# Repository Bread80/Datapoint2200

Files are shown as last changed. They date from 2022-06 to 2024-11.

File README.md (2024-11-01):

# Datapoint 2200 Schematics, Documents and PCB Recreations (WiP)

This is my project to transcribe the schematics for a Datapoint 2200 serial processor machine, reverse engineer them, and recreate the original hardware with added blinkenlights.

The repository contains schematics, PCB layout files, documents and software relevant to the 2200.

The schematics are in Kicad 5 format (at least until I make my peace with the UI in newer versions). To open them you may need to import the symbol library in Datapoint2200.lib and the Datapoint2200.pretty folder.

NOTES:
* These documents are still a work in progress.
* Schematics have not been double checked or verified against original hardware.
* On the original schematics some of the connector pinouts are ambiguous. DO NOT rely on the data in this repository when working with original hardware.

## Files
Some of the included files/PDFs:
* 2200_Drawing_package.pdf - Original schematics and engineering drawings.
* 2200_Reference_Manual.pdf - The operating manual for the machine including the assembly instruction set.
* 2200_Programmers_Man_Aug71.pdf - The processor instruction set, description of the standard libraries and operating instructions for the operating system, editor and assembler. Also contains a source code listing of the operating system software (but not the libraries, assembler or editor).
* 1405_Shift_Memory.pdf - Datasheet for the shift memory used in processor and video display.
* 74LS189_FairchildSemiconductor.pdf - Datasheet for the memory ICs used to implement the processor stack. (Which actually used very similiar 7489 ICs. The recreation has been designed to be able to use either).
* 1982_Standard_Microsystems.pdf - A datasheet catalogue which includes that for a character ROM compatible with one of those used in the video display, including character bitmaps.
* Datapoint2200.lib and .dcm - Kicab custom symbols (for Kicad 5).
* InstructionSet.txt - The instruction sets for both versions of the 2200 and the (very similar) Intel 8008.
* InstructionSet.xlsx - Spreadsheet version of the instruction sets (2200 and 8008) including comparisons against the Z80/8080.

## Folders/Boards
Schematics for each board are in their own folder.

The following lists the key boards of the Datapoint 2200 and the current status of each board.

### Board A1: Power Supply, Regulator
Status: Not transcribed.

### Board A2: Modulator
Modulator for the tape drives

Status: Not transcribed yet.

### Board A3: Demodulator
Demodulator for the tape drives

Status: Not transcribed yet.

### Board A4: Decoder
The system sequencer and output port/command decoder.

The schematic is split into the following files and functional units:
* Scheduler: Contains the system clock and gneerates signals to control the processort and machine as a whole.
* IODecoder: Decodes output port (command) addresses into individual signal lines.
* Speaker_Tape: Generates sound to the speaker (beeps and clicks), and houses some gates spilled over from the tape drive boards.

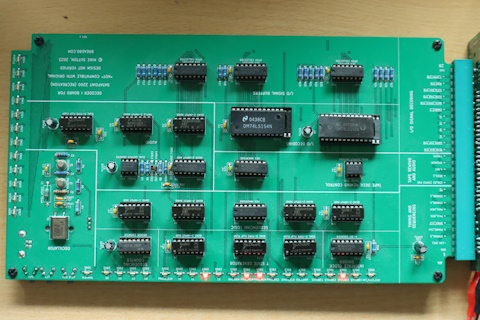
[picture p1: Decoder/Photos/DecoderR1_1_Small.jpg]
Decoder revision 1 PCB


Status: A first revision board has been manufactured and works but has a couple of largely cosmetic issues, the worst of which is an incorrect footprint for the wide-body TTL chips. The PCB currently in the repository is the proposed next revision but which has not been tested - I'll have it manufactured when I know it is driving the rest of the system correctly.

### Board A5: Processor
---
The processor itself. The schematic is divided up as follows:
* AddressRegister: The address register (counter).
* AddrRegAndStackControl: Controls reading data into the address register and program counter, incrementing the program counter, and the stack.
* ALU: The ALU and carry flag.
* ARegister: The A register and I/O bus.
* Flags: The flags (other than carry) and conditional jump/call/return handling.
* InstrDecdoing: Instruction decoding.
* IRegister: The instruction register and register decoding.
* Processor: The main overview.
* Registers1: The H and L registers and data bus logic.
* Registers2: The B, C, D and E registers.
* Stack: The stack and stack pointer, and memory card selection.
* Timing: Fetch-execute cycle, memory word sync, HALTing and running, clocking and miscellaneous.

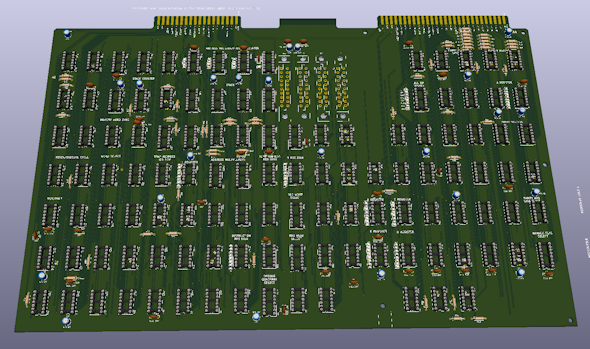
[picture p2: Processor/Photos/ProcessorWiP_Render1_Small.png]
Render of Processor PCB, WiP


Status: The design has been tested in a logic emulator and appears to function correctly. A PCB layout has been made up and I'm currently adding LEDs (and establishing which signals should have LEDs) before sending the board for production.

### Board A6: Keyboard
---
Houses the keyswitches and multiplexing circuitry.

Status: Transcribed but not checked.

### Board A7: Deflection Amplifier
---
This board houses the circuitry for driving the CRT, and also some TTL logic spilled over from the Display Control board.

Status: The TTL circuits have been transcribed. I'm proposing to replace the CRT circuitry with something capable of driving a suitable modern display (ie. something microcontroller based).

### Board A8: Display Control
The 'video card'. Contains video memory, character generator and display driver. The board also controls the reading of data from the keyboard.

The schematic is divided as follows
* Input: I/O decoder for the display and keyboard (they use the same port address) and controls the latching of video data (control register, horizontal and vertical position and data).
* Memory: Video memory (using 1405 shift registers).
* Pixel Gen: Pixel clock, 'diddle scanning' (row and column wthin each character), characters ROMs and cursor generation.
* RowColumnSync: Row and column scanning and latches, and syncing the two for writing video data to memory.
* ClearAndOutput: Clearing memory for to-end-of-row, to-end-of-screen and clear-display functions. Outputting the status register (display busy and keyboard mounted switches).

Status: Transcribed and checked (but not validated).

### Board A9: Keyboard Logic
Contains the logic for scanning the keyboard, latching returned keypresses, and outputting characted codes in ASCII.

Contains the following modules:
* Reboot: Drives the processor after rebooting to load the boot data from a tape drive.
* ReadControl: Controls the processor's input bus. The board either outputs data from the keyboard itself or the bus buffers(probably).
* 'Sheet1': The main keyboard scanning and latching circuit. This name is probably not optimal.
* Shift: A circuit spilled opver from 'Sheet1' which controls 'shifting' of ASCII codes.
* BusBuffers: Comparators to boost the signals from the external bus and forward them to the processor's input bus.
* RunSwitch: A small circuit to latch the state of the Run switch.

Status: Transcribed and checked but not validated.

### Boards A11 to A14: Memory cards
Houses the Intel 1405 shift memories ICs used by the processor and related row and column decoders.

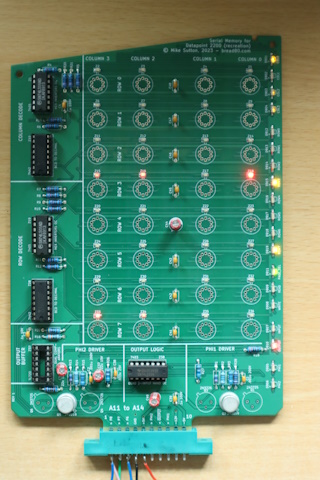
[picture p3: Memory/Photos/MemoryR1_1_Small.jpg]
Memory card revision 1 PCB


Status: Transcribed and first revision boards manufactured. The recreated PCBs include solder links to enable the memory to be operated at TTL voltage levels.
Note: The board has not been tested with actual 1405 chips.
Note: The 1405 ICs require a lot of power. The original PCBs are heavily engineered to be able to supply this power, and include a pair of bus bars for power distribution. The recreated PCBs have not been engineered to the same standards and shift should *not* be used with shift memories.

### Board A17: Motherboard
The 'backplane' into which many of the above boards slot (A1 to A9 except A6) or connect.

Status: Not transcribed yet

(Other board numbers are for smaller boards such as those in the tape machines, speaker mountings etc).

## Other Repository Contents
* Egde56: A test for for attaching to an edge connector.
* Software: A transcription and binaries for the operating system software listed in the Programmers Manual.

## Design Standards
These are mainly notes for myself to keep things consistent between boards.
  
Components:
  LEDs, side facing: Datapoint2200:LED_Dialight_597_xxxx_407F_SMT_RA_3mmx2mmx1mm (custom component and footprint in Datapoint2200 library)

Footprints:
Decoupling capacitors: Capacitor_THT:C_Disc_D7.0mm_W2.5mm_P5.00mm
Resistors (through hole): Resistor_THT:R_Axial_DIN0207_L6.3mm_D2.5mm_P10.16mm_Horizontal
Resistors (surface mount): 
  Decoder uses 0805: Resistor_SMD:R_0805_2012Metric_Pad1.20x1.40mm_HandSolder
  (other boards will vary!)
Mounting holes: MountingHole:MountingHole_3.2mm_M3
  Holes positioned 7x 25mils from board edges
Buttons (side mounted): Button_Switch_THT:SW_Tactile_SPST_Angled_PTS645Vx58-2LFS (exact model to be clarified)

Silkscreen:
All silkscreen placed on a 25mil (0.6250mm) grid
Section titles font size: W1.5 H1.5 Thickness: .25
Text for ICs:
  Top left: chip code (e.g. 7493), stated with original 74 series (no LS, HCT etc)
  Top right: reference code (e.g Z19)
  Below: chip description, centred. Use summary from datasheet where possible
Text for edge connector pins:
  Left (right on reverse) aligned to edge connector
  Use a < or > at connector end to indicate signal direction
  Positioned 50mil (2x0.6350mm) from connector pad
Edge connector pin numbers:
  Label first and last pin on each side.
  Font size: H1.5 H1.5 Thickness: 0.25
  Position: centred aligned
    8x 25mil horizontally from edge of connector pads
	4x 25mil vertically from centre of first pad
Board identifier (e.g. A4)
  Font size: H2 W2 Thickness: 0.35, orientation 90 degrees (i.e. from bottom to top) (Orientation valid for 'main' PCBs)
  Positioning: Centre aligned, 6x 25mils from board edge, 6x 25mils from edge of edge connector
Lines:
  Section separators: 0.5mm width
  Sub-section separators: 0.12mm width

*74x00	4	quad 2-input NAND gate			14	SN74LS00
*74x02	4	quad 2-input NOR gate			14	SN74LS02
*74x03	4	quad 2-input NAND gate		open-collector	14	SN74LS03
*74x04	6	hex inverter gate			14	SN74LS04
*74x05	6	hex inverter gate		open-collector	14	SN74LS05
**74x06	6	hex inverter gate		open-collector 30 V / 40 mA	14
*74x08	4	quad 2-input AND gate			14	SN74LS08
*74x10	3	triple 3-input NAND gate			14	SN74LS10
*74x20	2	dual 4-input NAND gate			14	SN74LS20
*74x30	1	single 8-input NAND gate			14	SN74LS30
**74x37	4	quad 2-input NAND gate		driver NO=30	14	SN74LS37
**74x40	2	dual 4-input NAND gate		driver NO=30	14	SN74LS40
*74x42	1	BCD to decimal decoder			16	SN74LS42
*74x73	2	dual J-K flip-flop, asynchronous clear			14	SN54LS73A
*74x74	2	dual D positive edge triggered flip-flop, asynchronous preset and clear			14	SN74LS74A
*74x85	1	4-bit magnitude comparator			16	SN74LS85
*74x89	1	64-bit RAM (16x4), 4 data inputs, 4 inverted data outputs		open-collector	16	SN7489
*74x95	1	4-bit shift register, parallel in, parallel out, serial input; different pinout for 74L95			14
*74x151	1	8-line to 1-line data selector/multiplexer			16	SN74151A
*74x153	2	dual 4-line to 1-line data selector/multiplexer, non-inverting outputs			16	SN74153
*74x164	1	8-bit serial-in parallel-out (SIPO) shift register, asynchronous clear, not output latch			14	SN74164
*74x193	1	synchronous presettable up/down 4-bit binary counter, clear			16	SN74193

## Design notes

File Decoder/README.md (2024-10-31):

Revision History

===Change History

Rev 1
Original

Revision 2
Fixed footprints for Z14, Z21
Beefed up connections to edge connector for +5V and GND
Renamed S0 to S3 LEDs as C0 to C3
Swapped order of C0 to C3
Added central mounting hole to provide extra physical support
Slightly repositioned sequencer LEDs due to central spacer, and for better grouping
LED for DIV64_CLK LED now driven from S3 (DIV64_CLK requires a pull-up which is positioned on the processor board)

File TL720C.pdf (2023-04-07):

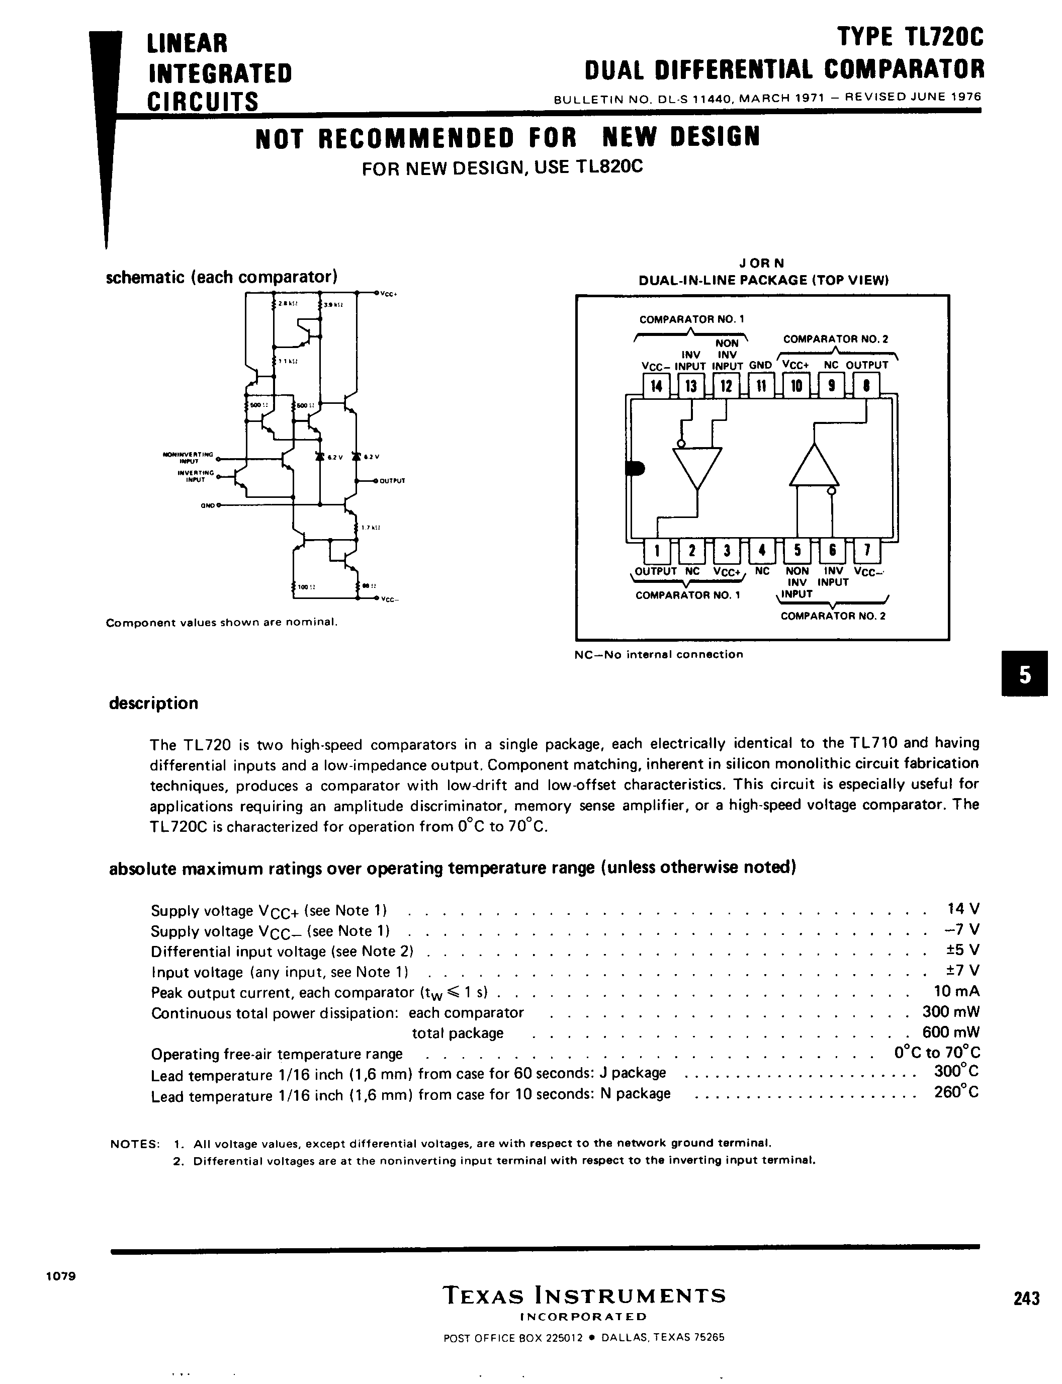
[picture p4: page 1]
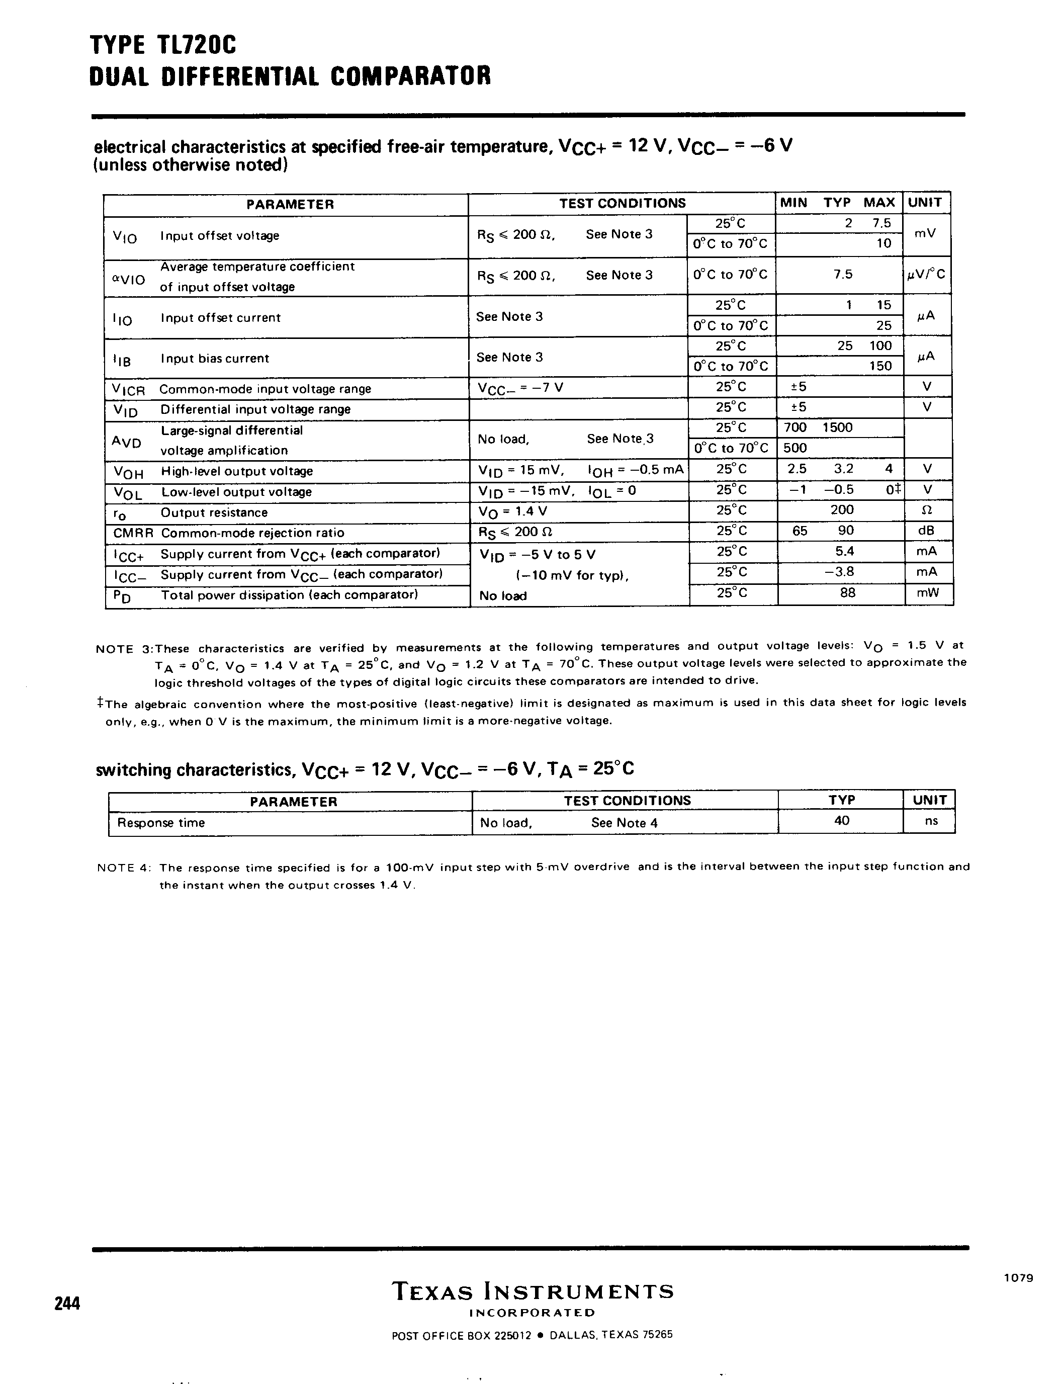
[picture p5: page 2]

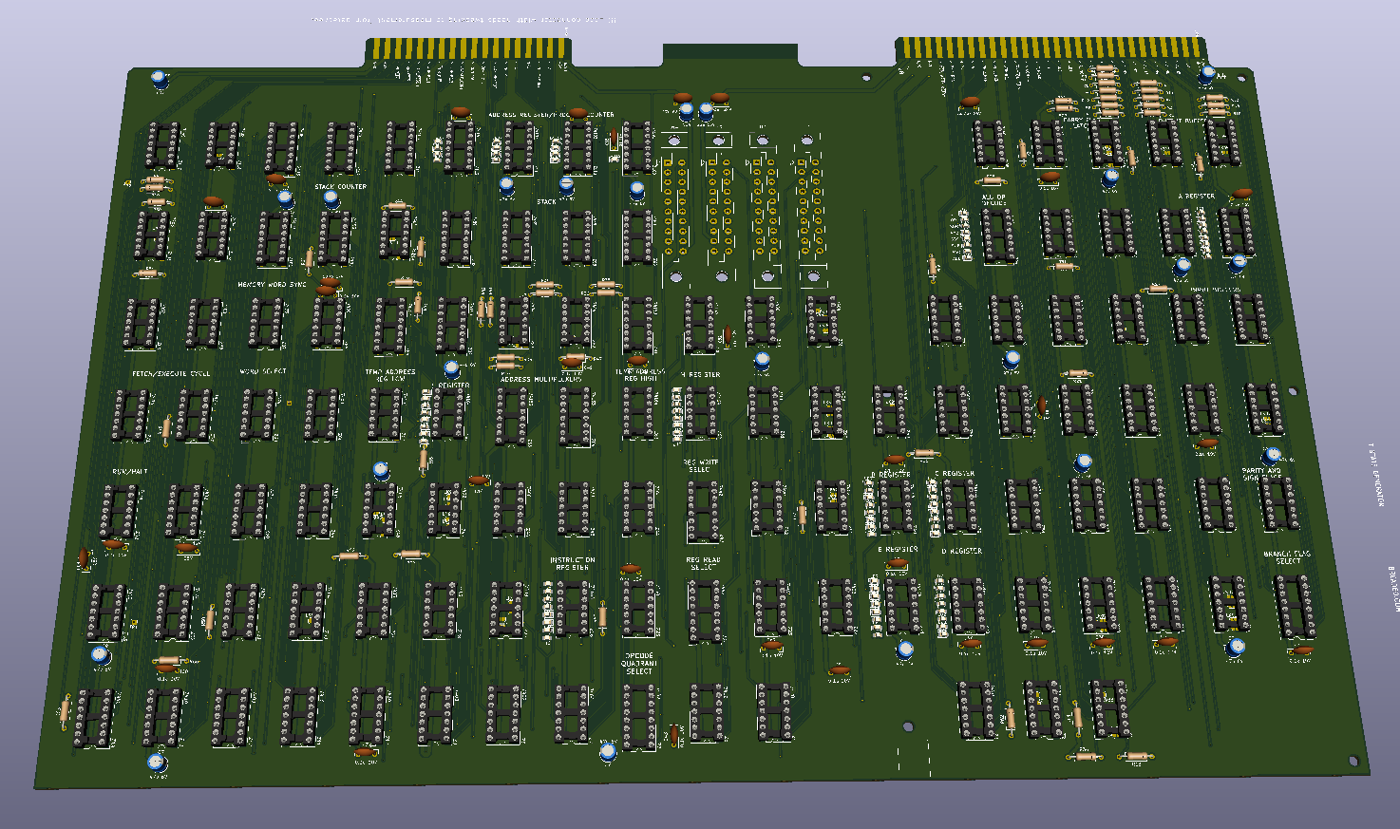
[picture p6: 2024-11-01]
Processor/Photos/ProcessorWiP_Render1.png

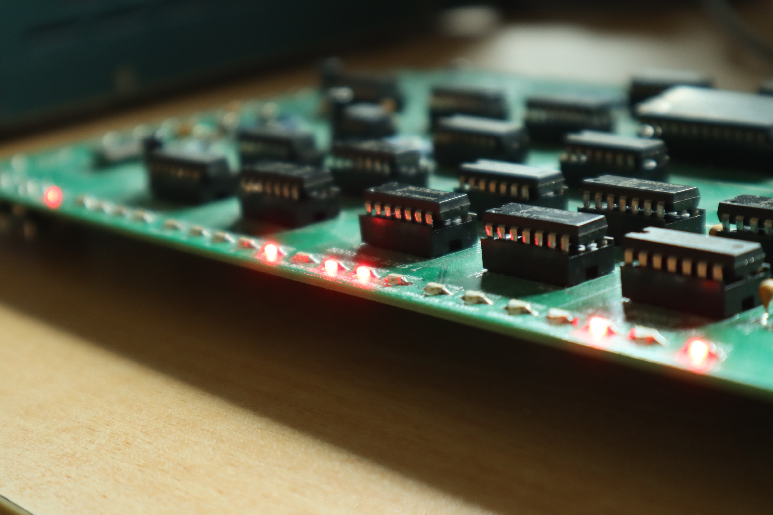
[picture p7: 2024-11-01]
Decoder/Photos/DecoderR1_8.JPG

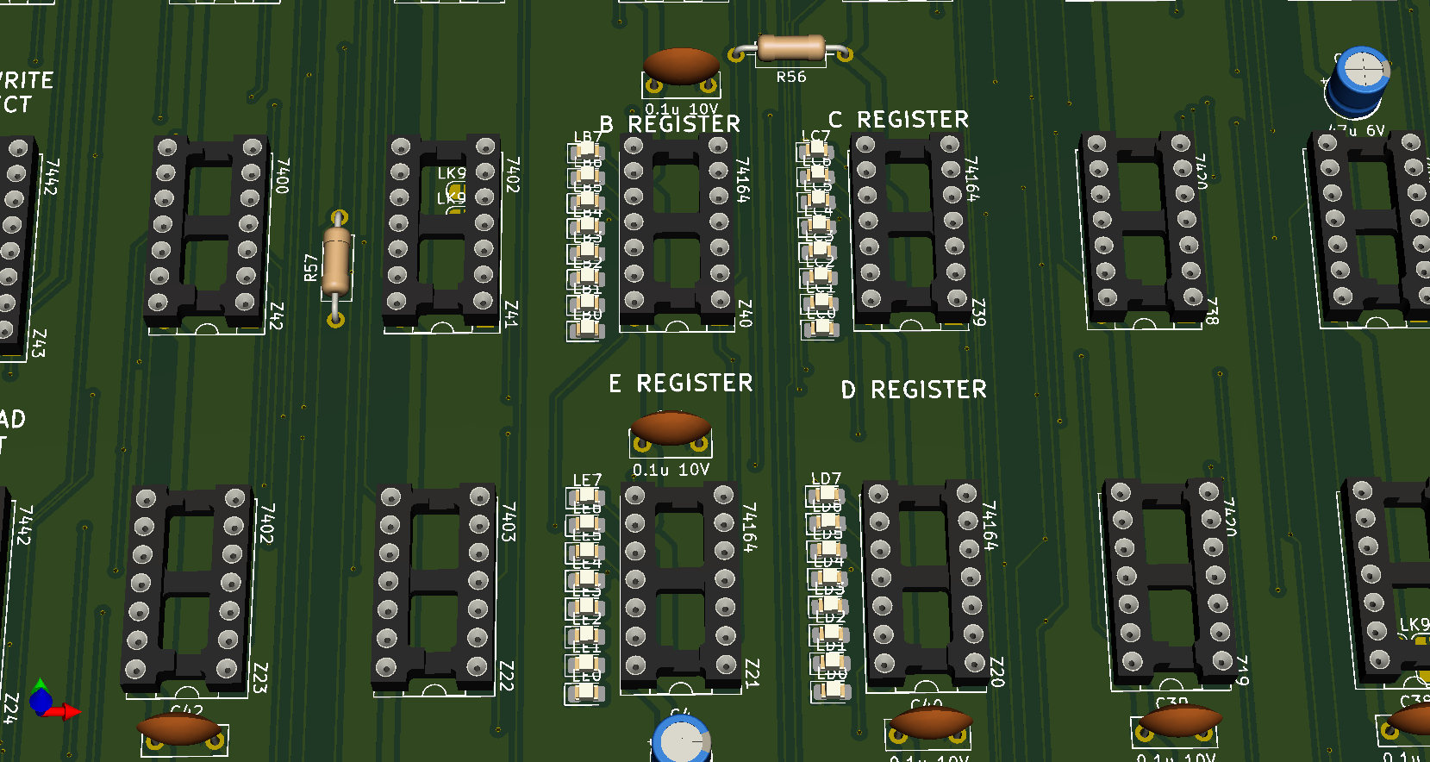
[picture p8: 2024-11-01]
Processor/Photos/ProcessorWiP_Render2.png

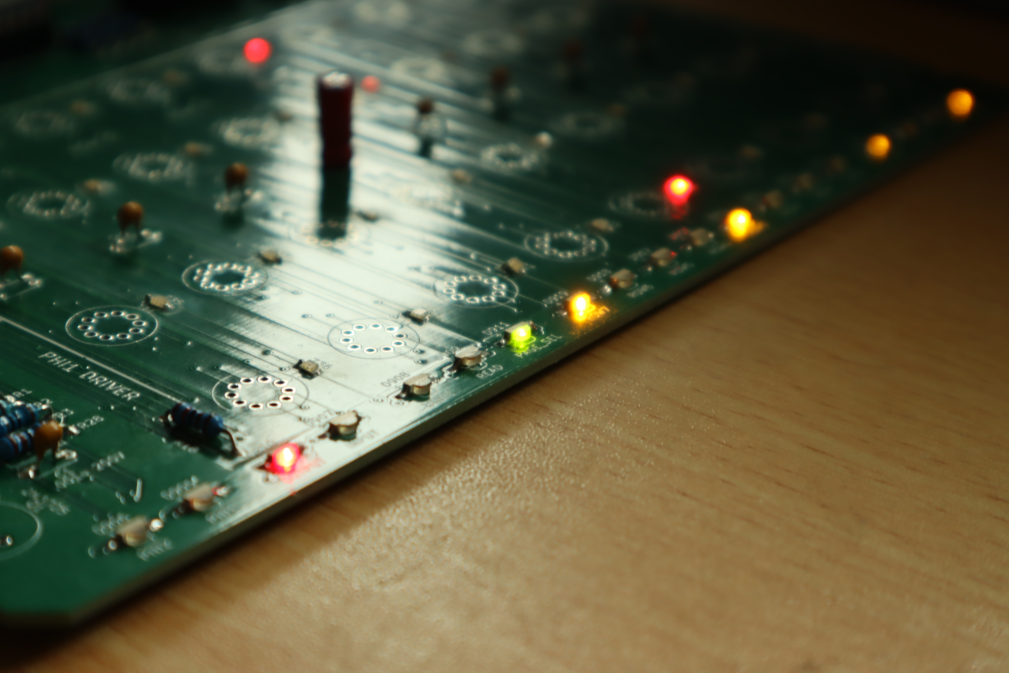
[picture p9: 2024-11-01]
Memory/Photos/MemoryR1_4.JPG

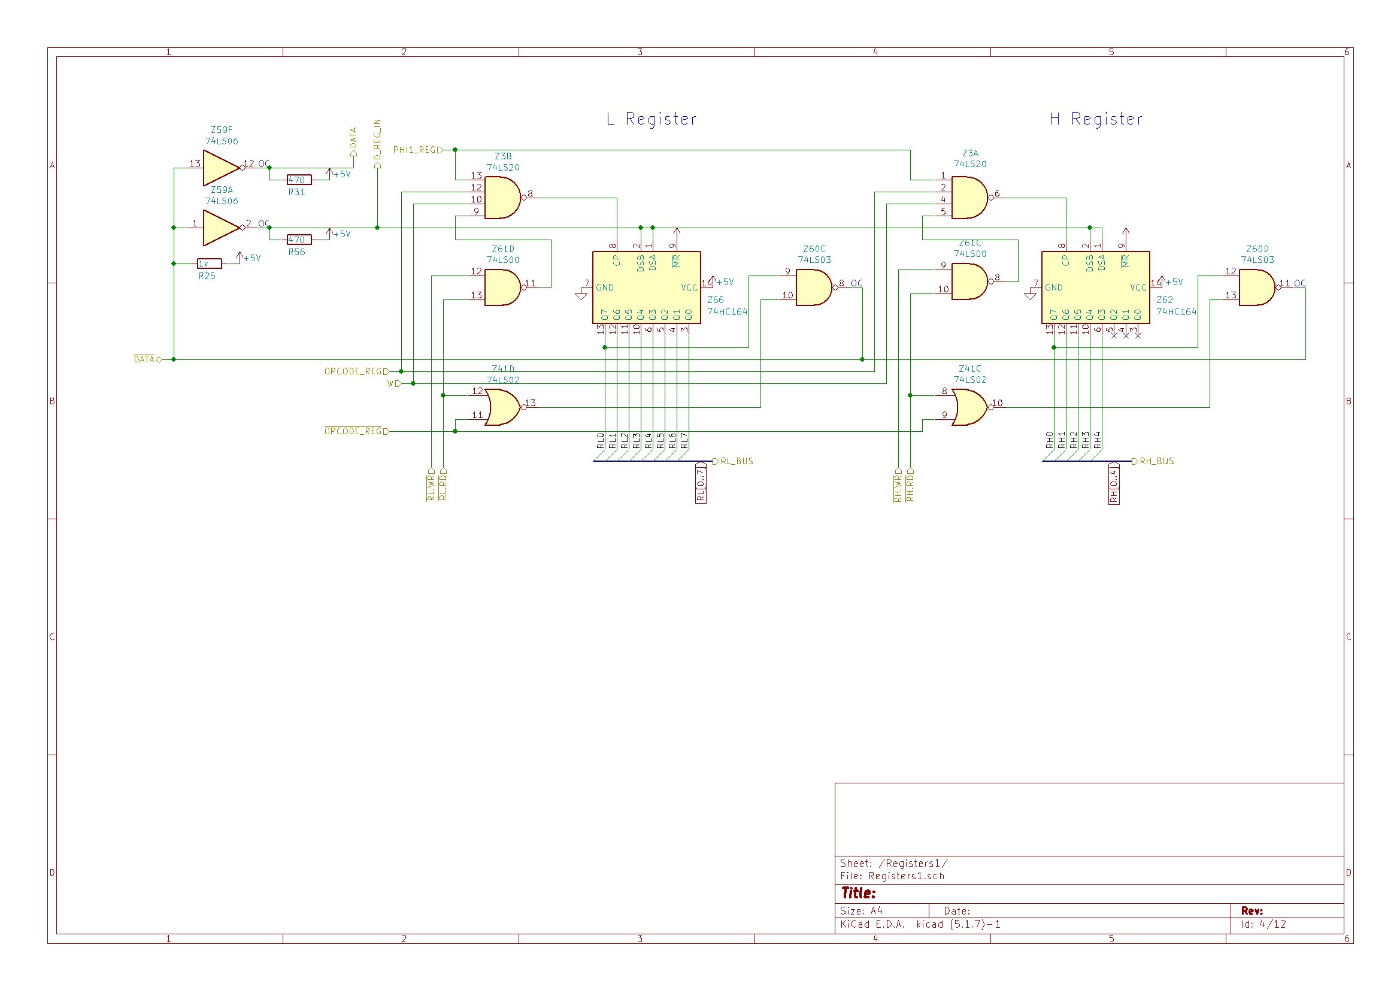
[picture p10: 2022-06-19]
Processor/Registers1.png

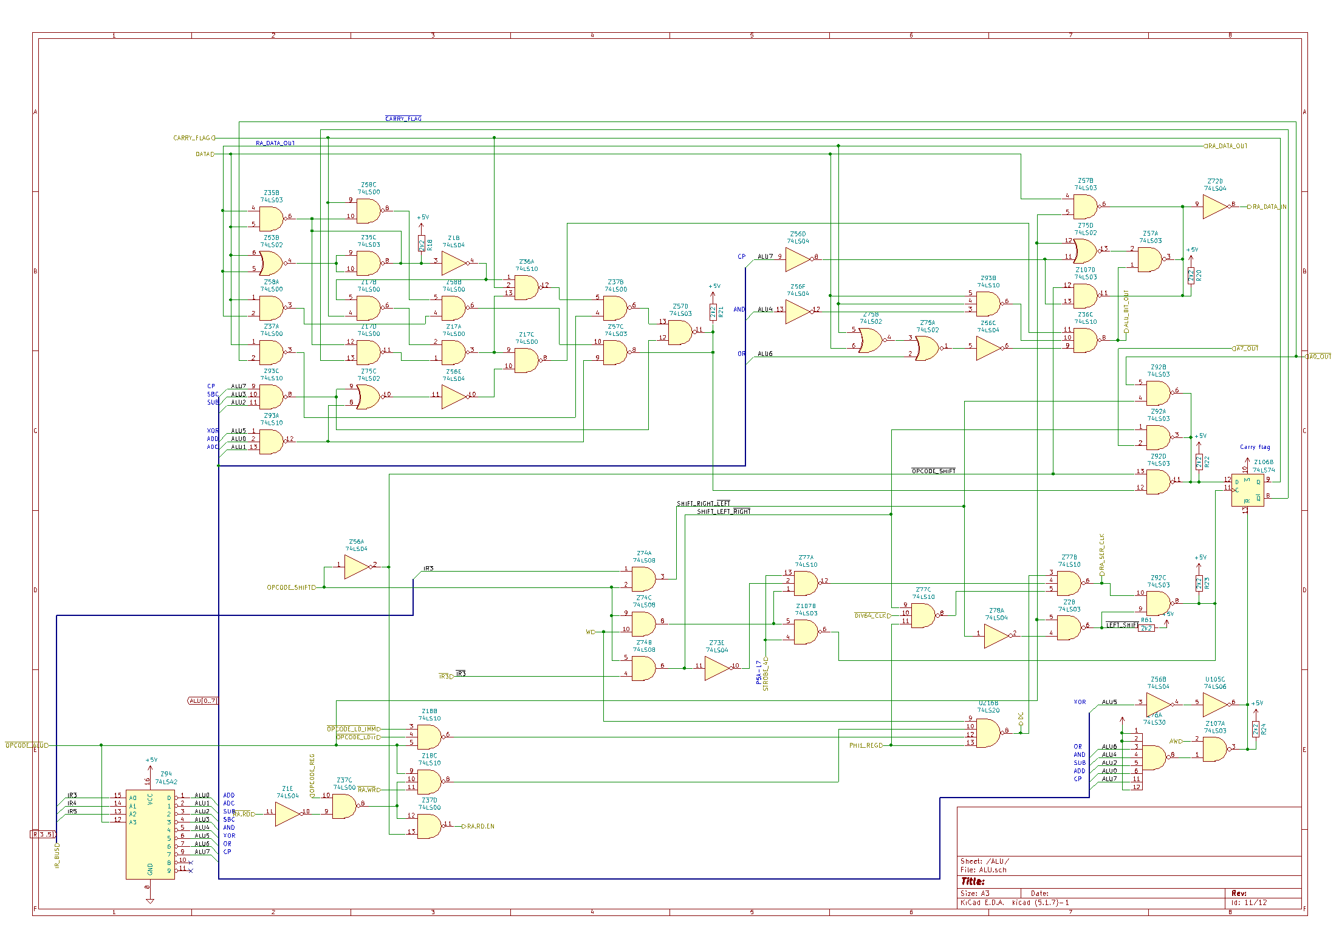
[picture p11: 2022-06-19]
Processor/ALU.png

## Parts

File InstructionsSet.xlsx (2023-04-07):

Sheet: Sheet1
Datapoint 2200 Instruction Set
 | x0 | x1 | x2 | x3 | x4 | x5 | x6 | x7 | x8 | x9 | xA | xB | xC | xD | xE | xF
0x | HALT | HALT | SLC | RFC | AD n |  | LA n | RETURN |  |  | SRC | RFZ | AC n |  | LB n
1x | BETA* |  |  | RFS | SU n |  | LC n |  | ALPHA* |  |  | RFP | SB n |  | LD n
2x | DI* |  |  | RTC | ND n |  | LE n |  | EI* |  |  | RTZ | XR n |  | LH n
3x | POP* |  |  | RTS | OR n |  | LL n |  | PUSH* |  |  | RTP | CP n |  | LM n
4x | JFC nn | INPUT | CFC nn |  | JMP nn |  | CALL nn |  | JFZ nn |  | CFZ nn
5x | JFS nn | EX ADR | CFS nn | EX STATUS |  | EX DATA |  | EX WRITE | JFP nn | EX COM1 | CFP nn | EX COM2 |  | EX COM3 |  | EX COM4
6x | JTC nn | (EX unassigned) | CTC nn | (EX unassigned) |  | (EX unassigned) |  | (EX unassigned) | JTZ nn | EX BEEP | CTZ nn | EX CLICK |  | EX DECK1 |  | EX DECK2
7x | JTS nn | EX RBK | CTS nn | EX WBK |  | (EX unassigned) |  | EX BSP | JTP nn | EX SF | CTP nn | EX SB |  | EX REWIND |  | EX TSTOP
8x | ADA | ADB | ADC | ADD | ADE | ADH | ADL | ADM | ACA | ACB | ACC | ACD | ACE | ACH | ACL | ACM
9x | SUA | SUB | SUC | SUD | SUE | SUH | SUL | SUM | SBA | SBB | SBC | SBD | SBE | SBH | SBL | SBM
Ax | NDA | NDB | NDC | NDD | NDE | NDH | NDL | NDM | XRA | XRB | XRC | XRD | XRE | XRH | XRL | XRM
Bx | ORA | ORB | ORC | ORD | ORE | ORH | ORL | ORM | CPA | CPB | CPC | CPD | CPE | CPH | CPL | CPM
Cx | NOP | LAB | LAC | LAD | LAE | LAH | LAL | LAM | LBA | LBB | LBC | LBD | LBE | LBH | LBL | LBM
Dx | LCA | LCB | LCC | LCD | LCE | LCH | LCL | LCM | LDA | LDB | LDC | LDD | LDE | LDH | LDL | LDM
Ex | LEA | LEB | LEC | LED | LEE | LEH | LEL | LEM | LHA | LHB | LHC | LHD | LHE | LHH | LHL | LHM
Fx | LLA | LLB | LLC | LLD | LLE | LLH | LLL | LLM | LMA | LMB | LMC | LMD | LME | LMH | LML | HALT
* - Instruction only available on version 2 processor
Key:
Load/store/Move
ALU operations
Flow control (Jump, Call, Return)
Input/Output
Miscellaneous
Lxx = Load/store/move. First parameter is destination, second is source. M=indirect read from/write to address in HL register
ADx=Add
ACx=Add with carry
SUx=Subtract
SBx=Substract with borrow
NDx=AND
XRx=XOR
ORx=OR
CPx=Compare
SLC=Shift left circular (rotate accumulator left)
SRC=Shift right circular (rotate the accumulator right)
RTx=Return if flag true
RFX=Return if flag false
Similary, Cxx=Call, Jxx=Jump
EX='Execute', ie send a command to an IO device.
EX ADR=Select a device at the address in the A register
INPUT reads value on IO bus. (Ie use an EX instructions beforehand to select a device and get it to put an input value onto the bus)

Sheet: Sheet2
Datapoint 2200 Instruction Set - Comparison to Z80
 | x0 | x1 | x2 | x3 | x4 | x5 | x6 | x7 | x8 | x9 | xA | xB | xC | xD | xE | xF
0x | HALT | HALT | RLA | RET NC | ADD A,n |  | LD A,n | RET |  |  | RRA | RET NZ | ADC A,n |  | LD B,n
1x | BETA* |  |  | RET P | SUB A,n |  | LD C,n |  | ALPHA* |  |  | RET PO | SBC A,n |  | LD D,n
2x | DI* |  |  | RET C | AND A,n |  | LD E,n |  | EI* |  |  | RET Z | XOR A,n |  | LD H,n
3x | POP HL* |  |  | RET M | OR A,n |  | LD L,n |  | PUSH HL* |  |  | RET PE | CP A,n |  | LD (HL),n
4x | JP NC,nn | INPUT | CALL NC,nn |  | JP nn |  | CALL nn |  | JP NZ,nn |  | CALL NZ,nn
5x | JP P,nn | EX ADR | CALL P,nn | EX STATUS |  | EX DATA |  | EX WRITE | JP PO,nn | EX COM1 | CALL PO,nn | EX COM2 |  | EX COM3 |  | EX COM4
6x | JP C,nn | (EX unassigned) | CALL C,nn | (EX unassigned) |  | (EX unassigned) |  | (EX unassigned) | JP Z,nn | EX BEEP | CALL Z,nn | EX CLICK |  | EX DECK1 |  | EX DECK2
7x | JP M,nn | EX RBK | CALL M,nn | EX WBK |  | (EX unassigned) |  | EX BSP | JP PE,nn | EX SF | CALL PE,nn | EX SB |  | EX REWIND |  | EX TSTOP
8x | ADD A,A | ADD A,B | ADD A,C | ADD A,D | ADD A,E | ADD A,H | ADD A,L | ADD A,(HL) | ADC A,A | ADC A,B | ADC A,C | ADC A,D | ADC A,E | ADC A,H | ADC A,L | ADC A,(HL)
9x | SUB A,A | SUB A,B | SUB A,C | SUB A,D | SUB A,E | SUB A,H | SUB A,L | SUB A,(HL) | SBC A,A | SBC A,B | SBC A,C | SBC A,D | SBC A,E | SBC A,H | SBC A,L | SBC A,(HL)
Ax | AND A | AND B | AND C | AND D | AND E | AND H | AND L | AND (HL) | XOR A | XOR B | XOR C | XOR D | XOR E | XOR H | XOR L | XOR (HL)
Bx | OR A | OR B | OR C | OR D | OR E | OR H | OR L | OR (HL) | CP A | CP B | CP C | CP D | CP E | CP H | CP L | CP (HL)
Cx | NOP | LD A,B | LD A,C | LD A,D | LD A,E | LD A,H | LD A,L | LD A,(HL) | LD B,A | LD B,B | LD B,C | LD B,D | LD B,E | LD B,H | LD B,L | LD B,(HL)
Dx | LD C,A | LD C,B | LD C,C | LD C,D | LD C,E | LD C,H | LC C,L | LD C,(HL) | LD D,A | LD D,B | LD D,C | LD D,D | LD D,E | LD D,H | LD D,L | LD D,(HL)
Ex | LD E,A | LD E,B | LD E,C | LD E,D | LD E,E | LD E,H | LD E,L | LD E,(HL) | LD H,A | LD H,B | LD H,C | LD H,D | LD H,E | LD H,H | LD H,L | LD H,(HL)
Fx | LD L,A | LD L,B | LD L,C | LD L,D | LD L,E | LD L,H | LD H,L | LD H,(HL) | LD (HL),A | LD (HL),B | LD (HL),C | LD (HL),D | LD (HL),E | LD (HL),H | LD (HL),L | HALT
* - Instruction only available on version 2 processor
Key:
Instructions with direct Z80 equivalents

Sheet: Sheet3
Intel 8008 Instruction Set
 | x0 | x1 | x2 | x3 | x4 | x5 | x6 | x7 | x8 | x9 | xA | xB | xC | xD | xE | xF
0x | HLT | HLT | RLC | RFC | ADI n | RST &00 | LAI n | RET | INB | DCB | RRC | RFZ | ACI n | RST &08 | LBI n | RET
1x | INC | DCC | RAL | RFS | SUI n | RST &10 | LCI n | RET | IND | DCD | RAR | RFP | SBI n | RST &18 | LDI n | RET
2x | INE | DCE |  | RTC | NDI n | RST &20 | LEI n | RET | INH | DCH |  | RTZ | XRI n | RST &28 | LHI n | RET
3x | INL | DCL |  | RTS | ORI n | RST &30 | LLI n | RET |  |  |  | RTP | CPI n | RST &38 | LMI n | RET
4x | JFC nn | INP 0 | CFC nn | INP 1 | JMP nn | INP 2 | CALL nn | INP 3 | JFZ nn | INP 4 | CFZ nn | INP 5 | JMP nn | INP 6 | CALL nn | INP 7
5x | JFS nn | OUT 0 | CFS nn | OUT 1 | JMP nn | OUT 2 | CALL nn | OUT 3 | JFP nn | OUT 4 | CFP nn | OUT 5 | JMP nn | OUT 6 | CALL nn | OUT 7
6x | JTC nn | OUT 8 | CTC nn | OUT 9 | JMP nn | OUT 10 | CALL nn | OUT 11 | JTZ nn | OUT 12 | CTZ nn | OUT 13 | JMP nn | OUT 14 | CALL nn | OUT 15
7x | JTS nn | OUT 16 | CTS nn | OUT 17 | JMP nn | OUT 18 | CALL nn | OUT 19 | JTP nn | OUT 20 | CTP nn | OUT 21 | JMP nn | OUT 22 | CALL nn | OUT 23
8x | ADA | ADB | ADC | ADD | ADE | ADH | ADL | ADM | ACA | ACB | ACC | ACD | ACE | ACH | ACL | ACM
9x | SUA | SUB | SUC | SUD | SUE | SUH | SUL | SUM | SBA | SBB | SBC | SBD | SBE | SBH | SBL | SBM
Ax | NDA | NDB | NDC | NDD | NDE | NDH | NDL | NDM | XRA | XRB | XRC | XRD | XRE | XRH | XRL | XRM
Bx | ORA | ORB | ORC | ORD | ORE | ORH | ORL | ORM | CPA | CPB | CPC | CPD | CPE | CPH | CPL | CPM
Cx | LAA | LAB | LAC | LAD | LAE | LAH | LAL | LAM | LBA | LBB | LBC | LBD | LBE | LBH | LBL | LBM
Dx | LCA | LCB | LCC | LCD | LCE | LCH | LCL | LCM | LDA | LDB | LDC | LDD | LDE | LDH | LDL | LDM
Ex | LEA | LEB | LEC | LED | LEE | LEH | LEL | LEM | LHA | LHB | LHC | LHD | LHE | LHH | LHL | LHM
Fx | LLA | LLB | LLC | LLD | LLE | LLH | LLL | LLM | LMA | LMB | LMC | LMD | LME | LMH | LML | HLT
* - Instruction only available on version 2 processor
Key:
Load/store/Move
ALU operations
Flow control (Jump, Call, Return)
Input/Output
Miscellaneous
Lxx = Load/store/move. First parameter is destination, second is source. M=indirect read from/write to address in HL register. I=read immediate data.
ADx=Add
ACx=Add with carry
SUx=Subtract
SBx=Substract with borrow
NDx=AND
XRx=XOR
ORx=OR
CPx=Compare
RLC/RRC= Rotate accumulator left/right
RLCA/RRCA=Rotate accumulator left/right through carry
INx=Increment register. Note the lack of a variants for A and (HL)
DCx=Decrement register. Note the lack of variants for A and (HL)
RTx=Return if flag true
RFx=Return if flag false
Similary, Cxx=Call, Jxx=Jump
RST=A single byte call to the listed destination address. Intended to be 'jammed' into the processor by a interrupt hardware.
INP=Input from the selected port (to the accumulator)
OUT=Output to the selected port (from the accumulator)

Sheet: Sheet4
Intel 8008 Instruction Set - Comparison to Z80
 | x0 | x1 | x2 | x3 | x4 | x5 | x6 | x7 | x8 | x9 | xA | xB | xC | xD | xE | xF
0x | HALT | HALT | RLCA | RET NC | ADD A,n | RST &00 | LD A,n | RET | INC B | DEC B | RRCA | RET NZ | ADC A,n | RST &08 | LD B,n
1x | INC C | DEC C | RLA | RET P | SUB A,n | RST &10 | LD C,n |  | INC D | DEC D | RRA | RET PO | SBC A,n | RST &18 | LD D,n
2x | INC E | DEC E |  | RET C | AND A,n | RST &20 | LD E,n |  | INC H | DEC H |  | RET Z | XOR A,n | RST &28 | LD H,n
3x | INC L | DEC L |  | RET M | OR A,n | RST &30 | LD L,n |  |  |  |  | RET PE | CP A,n | RST &38 | LD (HL),n
4x | JP NC,nn | INP 0 | CALL NC,nn | INP 1 | JP nn | INP 2 | CALL nn | INP 3 | JP NZ,nn | INP 4 | CALL NZ,nn | INP 5 |  | INP 6 |  | INP 7
5x | JP P,nn | OUT 0 | CALL P,nn | OUT 1 | JP nn | OUT 2 | CALL nn | OUT 3 | JP PO,nn | OUT 4 | CALL PO,nn | OUT 5 |  | OUT 6 |  | OUT 7
6x | JP C,nn | OUT 8 | CALL C,nn | OUT 9 | JP nn | OUT 10 | CALL nn | OUT 11 | JP Z,nn | OUT 12 | CALL Z,nn | OUT 13 |  | OUT 14 |  | OUT 15
7x | JP M,nn | OUT 16 | CALL M,nn | OUT 17 | JP nn | OUT 18 | CALL nn | OUT 19 | JP PE,nn | OUT 20 | CALL PE,nn | OUT 21 |  | OUT 22 |  | OUT 23
8x | ADD A,A | ADD A,B | ADD A,C | ADD A,D | ADD A,E | ADD A,H | ADD A,L | ADD A,(HL) | ADC A,A | ADC A,B | ADC A,C | ADC A,D | ADC A,E | ADC A,H | ADC A,L | ADC A,(HL)
9x | SUB A,A | SUB A,B | SUB A,C | SUB A,D | SUB A,E | SUB A,H | SUB A,L | SUB A,(HL) | SBC A,A | SBC A,B | SBC A,C | SBC A,D | SBC A,E | SBC A,H | SBC A,L | SBC A,(HL)
Ax | AND A | AND B | AND C | AND D | AND E | AND H | AND L | AND (HL) | XOR A | XOR B | XOR C | XOR D | XOR E | XOR H | XOR L | XOR (HL)
Bx | OR A | OR B | OR C | OR D | OR E | OR H | OR L | OR (HL) | CP A | CP B | CP C | CP D | CP E | CP H | CP L | CP (HL)
Cx | NOP | LD A,B | LD A,C | LD A,D | LD A,E | LD A,H | LD A,L | LD A,(HL) | LD B,A | LD B,B | LD B,C | LD B,D | LD B,E | LD B,H | LD B,L | LD B,(HL)
Dx | LD C,A | LD C,B | LD C,C | LD C,D | LD C,E | LD C,H | LC C,L | LD C,(HL) | LD D,A | LD D,B | LD D,C | LD D,D | LD D,E | LD D,H | LD D,L | LD D,(HL)
Ex | LD E,A | LD E,B | LD E,C | LD E,D | LD E,E | LD E,H | LD E,L | LD E,(HL) | LD H,A | LD H,B | LD H,C | LD H,D | LD H,E | LD H,H | LD H,L | LD H,(HL)
Fx | LD L,A | LD L,B | LD L,C | LD L,D | LD L,E | LD L,H | LD L,L | LD L,(HL) | LD (HL),A | LD (HL),B | LD (HL),C | LD (HL),D | LD (HL),E | LD (HL),H | LD (HL),L | HALT
* - Instruction only available on version 2 processor
Key:
Instructions with direct Z80 equivalents

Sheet: Sheet5
Z80 Instruction History
 | x0 | x1 | x2 | x3 | x4 | x5 | x6 | x7 | x8 | x9 | xA | xB | xC | xD | xE | xF
0x | NOP | LD BC,nn | LD (BC),A | INC BC | INC B | DEC B | LD B,n | RLCA | EX AF,AF' | ADD HL,BC | LD A,(BC) | DEC BC | INC C | DEC C | LD C,n | RRCA
1x | DJNZ e | LD DE,nn | LD (DE),A | INC DE | INC D | DEC D | LD D,n | RLA | JR e | ADD HL,DE | LD A,(DE) | DEC DE | INC E | DEC E | LD E,n | RRA
2x | JR NZ,e | LD HL,nn | LD (nn),HL | INC HL | INC H | DEC H | LD H,n | DAA | JR Z,e | ADD HL,HL | LD HL,(nn) | DEC HL | INC L | DEC L | LD L,n | CPL
3x | JR NC,e | LD SP,nn | LD (nn),A | INC SP | INC (HL) | DEC (HL) | LD (HL),n | SCF | JR C,e | ADD HL,SP | LD A,(nn) | DEC SP | INC A | DEC A | LD A,n | CCF
4x | LD B,B | LD B,C | LD B,D | LD B,E | LD B,H | LD B,L | LD B,(HL) | LD B,A | LD C,B | LD C,C | LD C,D | LD C,E | LD C,H | LC C,L | LD C,(HL) | LD C,A
5x | LD D,B | LD D,C | LD D,D | LD D,E | LD D,H | LD D,L | LD D,(HL) | LD D,A | LD E,B | LD E,C | LD E,D | LD E,E | LD E,H | LD E,L | LD E,(HL) | LD E,A
6x | LD H,B | LD H,C | LD H,D | LD H,E | LD H,H | LD H,L | LD H,(HL) | LD H,A | LD L,B | LD L,C | LD L,D | LD L,E | LD L,H | LD L,L | LD L,(HL) | LD L,A
7x | LD (HL),B | LD (HL),C | LD (HL),D | LD (HL),E | LD (HL),H | LD (HL),L | HALT | LD (HL),A | LD A,B | LD A,C | LD A,D | LD A,E | LD A,H | LD A,L | LD A,(HL) | LD A,A
8x | ADD A,B | ADD A,C | ADD A,D | ADD A,E | ADD A,H | ADD A,L | ADD A,(HL) | ADD A,A | ADC A,B | ADC A,C | ADC A,D | ADC A,E | ADC A,H | ADC A,L | ADC A,(HL) | ADC A,A
9x | SUB A,B | SUB A,C | SUB A,D | SUB A,E | SUB A,H | SUB A,L | SUB A,(HL) | SUB A,A | SBC A,B | SBC A,C | SBC A,D | SBC A,E | SBC A,H | SBC A,L | SBC A,(HL) | SBC A,A
Ax | AND B | AND C | AND D | AND E | AND H | AND L | AND (HL) | AND A | XOR B | XOR C | XOR D | XOR E | XOR H | XOR L | XOR (HL) | XOR A
Bx | OR B | OR C | OR D | OR E | OR H | OR L | OR (HL) | OR A | CP B | CP C | CP D | CP E | CP H | CP L | CP (HL) | CP A
Cx | RET NZ | POP BC | JP NZ,nn | JP nn | CALL NZ,nn | PUSH BC | ADD A,n | RST &00 | RET Z | RET | JP Z,nn | CB prefix | CALL Z,nn | CALL nn | ADC A,n | RST &08
Dx | RET NC | POP DE | JP NC,nn | OUT (n),A | CALL NC,nn | PUSH DE | SUB A,n | RST &10 | RET C | EXX | JP C,nn | IN A,(n) | CALL C,nn | IX prefix | SBC A,n | RST &18
Ex | RET PO | POP HL | JP PO,nn | EX (SP),HL | CALL PO,nn | PUSH HL | AND A,n | RST &20 | RET PE | JP (HL) | JP PE,nn | EX DE,HL | CALL PE,nn | ED prefix | XOR A,n | RST &28
Fx | RET P | POP AF | JP P,nn | DI | CALL P,nn | PUSH AF | OR A,n | RST &30 | RET M | LD SP,HL | JP M,nn | EI | CALL M,nn | IY prefix | CP A,n | RST &38
Key, showing when the instruction was first introduced:
Datapoint 2200, version 1
Intel 8008
Intel 8080
Zilog Z80
Notes:
(1) Instructions are only shown if they act identically to that in a previous generation (excluding half carry, subtract and undocumented flags).
(2) DI, EI, POP HL and PUSH HL where added by the Datapoint 2200 version 2 processor but this processor existed in a separate timeline.
(3) Bytecodes changed between the 8008 and the 8080.

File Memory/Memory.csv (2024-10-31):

Source: | C:\Dropbox\InfoLaptop\Bread80\Datapoint2200\Memory\Memory.sch
Date: | 04/08/2023 15:44
Tool: | Eeschema (5.1.12)-1
Generator: | C:\Program Files\KiCad\bin\scripting\plugins/bom_csv_grouped_by_value_with_fp.py
Component Count: | 173
Ref | Qnty | Value | Cmp name | Footprint | Description | Vendor
C1, C2, | 2 | .001u 200V | C | Capacitor_THT:C_Disc_D4.7mm_W2.5mm_P5.00mm | Unpolarized capacitor
C3, | 1 | .1u 10V | C | Capacitor_THT:C_Disc_D7.0mm_W2.5mm_P5.00mm | Unpolarized capacitor
C6, C39, C41, C42, C43, C45, C46, C47, C48, | 9 | .1u 100V | C | Capacitor_THT:C_Disc_D7.0mm_W2.5mm_P5.00mm | Unpolarized capacitor
C36, C37, C49, | 3 | 22u 15V | CP | Capacitor_THT:CP_Radial_D5.0mm_P2.50mm | Polarized capacitor
C38, | 1 | .033u 25V | C | Capacitor_THT:C_Disc_D4.7mm_W2.5mm_P5.00mm | Unpolarized capacitor
C44, | 1 | 68u 15V | CP | Capacitor_THT:CP_Radial_D6.3mm_P2.50mm | Polarized capacitor
D901, | 19 | COL0 | LED | DataPoint_2200:LED_Dialight_597_xxxx_407F_SMT_RA_3mmx2mmx1mm | Light emitting diode
D920, | 32 | Z5 | LED | LED_SMD:LED_0805_2012Metric_Pad1.15x1.40mm_HandSolder | Light emitting diode
Q1, Q6, | 2 | 2N3725 | 2N2219 | Package_TO_SOT_THT:TO-39-3 | 800mA Ic, 50V Vce, NPN Transistor, TO-39
Q2, Q5, | 2 | 2N2219 | 2N2219 | Package_TO_SOT_THT:TO-39-3 | 800mA Ic, 50V Vce, NPN Transistor, TO-39
Q3, Q4, | 2 | 2N3726 | Q_PNP_BCE | Package_TO_SOT_THT:TO-39-3 | PNP transistor, base/collector/emitter
R1, R13, | 2 | 220 | R | Resistor_THT:R_Axial_DIN0207_L6.3mm_D2.5mm_P10.16mm_Horizontal | Resistor
R2, R14, | 2 | 100 | R | Resistor_THT:R_Axial_DIN0207_L6.3mm_D2.5mm_P10.16mm_Horizontal | Resistor
R3, R15, | 2 | 680 | R | Resistor_THT:R_Axial_DIN0207_L6.3mm_D2.5mm_P10.16mm_Horizontal | Resistor
R4, R5, R6, R7, R8, R9, R10, R11, R12, R18, R19, R20, R21, | 13 | 2k2 | R | Resistor_THT:R_Axial_DIN0207_L6.3mm_D2.5mm_P10.16mm_Horizontal | Resistor
R16, | 1 | 330 | R | Resistor_THT:R_Axial_DIN0207_L6.3mm_D2.5mm_P10.16mm_Horizontal | Resistor
R22, | 1 | 470 | R | Resistor_THT:R_Axial_DIN0207_L6.3mm_D2.5mm_P10.16mm_Horizontal | Resistor
R25, R28, | 2 | 1k | R | Resistor_THT:R_Axial_DIN0207_L6.3mm_D2.5mm_P10.16mm_Horizontal | Resistor
R26, R27, | 2 | 6R8 | R | Resistor_THT:R_Axial_DIN0207_L6.3mm_D2.5mm_P10.16mm_Horizontal | Resistor
R901, R902, R903, R904, R905, R906, R907, R908, R909, R910, R911, R912, R913, R914, R915, R916, R917, R918, R919, R920, R921, R922, R923, | 23 | 470R | R | Resistor_SMD:R_0805_2012Metric_Pad1.20x1.40mm_HandSolder | Resistor
U904, U905, U906, | 3 | 74HCT245 | 74LS245 | Package_SO:TSSOP-20_4.4x6.5mm_P0.65mm | Octal BUS Transceivers, 3-State outputs
Z1, Z19, | 2 | 7405 | 74LS05 | Package_DIP:DIP-14_W7.62mm_Socket | Inverter Open Collect
Z2, Z3, Z4, Z5, Z6, Z7, Z8, Z9, Z11, Z12, Z13, Z14, Z15, Z16, Z17, Z18, Z20, Z21, Z22, Z23, Z24, Z25, Z26, Z27, Z29, Z30, Z31, Z32, Z33, Z34, Z35, Z36, | 32 | 1405 | 1405 | DataPoint_2200:TO-99-10 | Intel 1405 512-bit (512 x 1) Dymanic Recirculating Shift Register (Shift Memory)
Z10, Z28, | 2 | 7442 | 74LS42 | Package_DIP:DIP-16_W7.62mm_Socket | 4 to 10 line Decoder
Z37, | 1 | TL720 | TL720 | Package_DIP:DIP-14_W7.62mm_Socket | Dual Differential Comparator
Z38, | 1 | 7403 | 74LS03 | Package_DIP:DIP-14_W7.62mm_Socket | Quad 2-input NAND open collector

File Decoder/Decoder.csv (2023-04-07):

Source: | C:\Dropbox\InfoLaptop\Bread80\Datapoint2200\Decoder\Decoder.sch
Date: | 28/03/2023 18:18
Tool: | Eeschema (5.1.12)-1
Generator: | C:\Program Files\KiCad\bin\scripting\plugins/bom_csv_grouped_by_value_with_fp.py
Component Count: | 198
Ref | Qnty | Value | Cmp name | Footprint | Description | Vendor
C1, C2, | 2 | 160p | C | Capacitor_THT:C_Disc_D7.0mm_W2.5mm_P5.00mm | Unpolarized capacitor
C3, | 1 | 51p | C | Capacitor_THT:C_Disc_D7.0mm_W2.5mm_P5.00mm | Unpolarized capacitor
C4, C8, C9, C15, C20, | 5 | 6V47u | CP | Capacitor_THT:CP_Radial_D6.3mm_P2.50mm | Polarized capacitor
C5, C6, C7, C11, C12, C13, C14, C17, C19, C24, C25, C26, | 12 | .1u | C | Capacitor_THT:C_Disc_D7.0mm_W2.5mm_P5.00mm | Unpolarized capacitor
C10, | 1 | .01u 50V | C | Capacitor_THT:C_Disc_D7.0mm_W2.5mm_P5.00mm | Unpolarized capacitor
C16, | 1 | 0.1 | C | Capacitor_THT:C_Disc_D7.0mm_W2.5mm_P5.00mm | Unpolarized capacitor
C21, C22, C23, | 3 | .001u 200V | C | Capacitor_THT:C_Disc_D7.0mm_W2.5mm_P5.00mm | Unpolarized capacitor
CR1, CR2, | 2 | 1N914 | D | Diode_THT:D_DO-34_SOD68_P7.62mm_Horizontal | Diode
D901, to D921 | 21 | 9.84MHz | LED | Datapoint2200:LED_Dialight_597_xxxx_407F_SMT_RA_3mmx2mmx1mm | Light emitting diode
D941, to D964 | 24 | PORT8 | LED | Datapoint2200:LED_Dialight_597_xxxx_407F_SMT_RA_3mmx2mmx1mm | Light emitting diode
H901, H902, H903, H904, H905, H906, | 6 | MountingHole | MountingHole | MountingHole:MountingHole_3.2mm_M3 | Mounting Hole without connection
J4A1, | 1 | EdgeTop | Conn_01x28_Male | Datapoint2200:EdgeConn_28_Pin_Pitch_3.96mm | Generic connector, single row, 01x28, script generated (kicad-library-utils/schlib/autogen/connector/)
J4B1, | 1 | EdgeBottom | Conn_01x28_Male | Datapoint2200:EdgeConn_28_Pin_Pitch_3.96mm | Generic connector, single row, 01x28, script generated (kicad-library-utils/schlib/autogen/connector/)
J981, | 1 | USB_B | USB_B | Connector_USB:USB_B_Lumberg_2411_02_Horizontal | USB Type B connector
JP901, | 1 | CLK SRC | Jumper_3_Open | Connector_PinHeader_2.54mm:PinHeader_1x03_P2.54mm_Vertical | Jumper, 3-pole, both open
L1, | 1 | 120uH 75mA | INDUCTOR | Inductor_THT:L_Axial_L9.5mm_D4.0mm_P12.70mm_Horizontal_Fastron_SMCC | Inductor symbol for simulation only
Q1, Q2, | 2 | 2N2369A | Q_NPN_EBC | Package_TO_SOT_THT:TO-18-3 | NPN transistor, emitter/base/collector
Q901, Q902, Q903, Q904, Q905, | 5 | 2N7002 | 2N7002 | Package_TO_SOT_SMD:SOT-23 | 0.115A Id, 60V Vds, N-Channel MOSFET, SOT-23
R1, | 1 | 1k5 | R | Resistor_THT:R_Axial_DIN0207_L6.3mm_D2.5mm_P7.62mm_Horizontal | Resistor
R2, R9, R19, R20, R21, R22, R23, R24, R25, R26, R27, | 11 | 2k2 | R | Resistor_THT:R_Axial_DIN0207_L6.3mm_D2.5mm_P7.62mm_Horizontal | Resistor
R3, R5, R6, | 3 | 1k | R | Resistor_THT:R_Axial_DIN0207_L6.3mm_D2.5mm_P7.62mm_Horizontal | Resistor
R4, | 1 | 560 | R | Resistor_THT:R_Axial_DIN0207_L6.3mm_D2.5mm_P7.62mm_Horizontal | Resistor
R7, | 1 | 5.1 | R | Resistor_THT:R_Axial_DIN0207_L6.3mm_D2.5mm_P7.62mm_Horizontal | Resistor
R8, | 1 | 1.2 | R | Resistor_THT:R_Axial_DIN0207_L6.3mm_D2.5mm_P7.62mm_Horizontal | Resistor
R10, | 1 | 10k | R | Resistor_THT:R_Axial_DIN0207_L6.3mm_D2.5mm_P7.62mm_Horizontal | Resistor
R11, R12, R13, R14, R15, R16, R17, R18, R28, | 9 | 470 | R | Resistor_THT:R_Axial_DIN0207_L6.3mm_D2.5mm_P7.62mm_Horizontal | Resistor
R901, R902, R903, R904, R905, R906, R907, R908, R909, R910, R911, R912, R913, R914, R915, R916, R917, R918, R919, R920, R921, R941, R942, R943, R944, R945, R946, R947, R948, R949, R950, R951, R952, R953, R954, R955, R956, R957, R958, R959, R960, R961, R962, R963, R964, | 45 | 470 | R | Resistor_SMD:R_0805_2012Metric_Pad1.20x1.40mm_HandSolder | Resistor
SW981, | 1 | BOOTSEL | SW_Push | Button_Switch_SMD:SW_Push_1P1T_NO_6x6mm_H9.5mm | Push button switch, generic, two pins
SW982, | 1 | RUN STOP | SW_Push | Button_Switch_THT:SW_Tactile_SPST_Angled_PTS645Vx58-2LFS | Push button switch, generic, two pins
SW983, | 1 | +/T | SW_Push | Button_Switch_THT:SW_Tactile_SPST_Angled_PTS645Vx58-2LFS | Push button switch, generic, two pins
SW984, | 1 | -/S | SW_Push | Button_Switch_THT:SW_Tactile_SPST_Angled_PTS645Vx58-2LFS | Push button switch, generic, two pins
U901, U902, | 2 | 74HCT245 | 74LS245 | Package_SO:TSSOP-20_4.4x6.5mm_P0.65mm | Octal BUS Transceivers, 3-State outputs
U941, U942, U943, U944, | 4 | 74LS04 | 74LS04 | Package_SO:TSSOP-14_4.4x5mm_P0.65mm | Hex Inverter
U981, | 1 | RP2040_Stamp | RP2040_Stamp | RP2040Stamp:RP2040_Stamp_SMD
U982, | 1 | 74LVC245 | 74LS245 | Package_SO:TSSOP-20_4.4x6.5mm_P0.65mm | Octal BUS Transceivers, 3-State outputs
Y1, | 1 | 9.8400MHz | Crystal | Crystal:Crystal_HC49-U_Horizontal | Two pin crystal
Z1, Z11, Z16, | 3 | 7474 | 74LS74 | Package_DIP:DIP-14_W7.62mm_Socket | Dual D Flip-flop, Set & Reset
Z2, | 1 | 7490 | 74LS90 | Package_DIP:DIP-14_W7.62mm_Socket | BCD Counter ( div 2 & div 5 )
Z3, Z6, Z19, | 3 | 7402 | 74LS02 | Package_DIP:DIP-14_W7.62mm_Socket | quad 2-input NOR gate
Z4, Z20, | 2 | 75451 | 75451 | Package_DIP:DIP-8_W7.62mm_Socket | Dual-Peripheral Drivers for High-Current, High-Speed Switching
Z5, | 1 | 7410 | 74LS10 | Package_DIP:DIP-14_W7.62mm_Socket | Triple 3-input NAND
Z7, Z9, Z17, | 3 | 7400 | 74LS00 | Package_DIP:DIP-14_W7.62mm_Socket | quad 2-input NAND gate
Z8, | 1 | 7408 | 74LS08 | Package_DIP:DIP-14_W7.62mm_Socket | Quad And2
Z10, Z15, Z22, | 3 | 7407 | 74LS07 | Package_DIP:DIP-14_W7.62mm_Socket | Hex Buffers and Drivers With Open Collector High Voltage Outputs
Z12, Z13, | 2 | 7404 | 74LS04 | Package_DIP:DIP-14_W7.62mm_Socket | Hex Inverter
Z14, Z21, | 2 | 74154 | 74LS154 | Package_DIP:DIP-24_W10.16mm_Socket | Decoder 4 to 16
Z18, | 1 | 7493 | 74LS93 | Package_DIP:DIP-14_W7.62mm_Socket | Divide by 2 & 8 counter

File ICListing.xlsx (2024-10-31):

Identifier (Z) | Type (LS) | Outputs used… |  |  |  |  |  | Unit count | Unused | Identifier | Type | Units | Description |  | Pins
1 | 4 | 12 | 6 | 4 | 10 |  |  | 4 | 2 | Z1 | 74x04 | 6 | hex inverter gate |  | 14
2 | 3 | 3 | 6 | 11 |  |  |  | 3 | 1 | Z2 | 74x03 | 4 | quad 2-input NAND gate | open-collector | 14
3 | 20 | 6 | 8 |  |  |  |  | 2 | 0 | Z3 | 74x20 | 2 | dual 4-input NAND gate |  | 14
4 | 20 | 6 | 8 |  |  |  |  | 2 | 0 | Z4 | 74x20 | 2 | dual 4-input NAND gate |  | 14
5 | 10 | 8 | 6 | 12 |  |  |  | 3 | 0 | Z5 | 74x10 | 3 | triple 3-input NAND gate |  | 14
6 | 42 |  |  |  |  |  |  | 1 | 0 | Z6 | 74x42 | 1 | BCD to decimal decoder |  | 16
7 | 4 | 2 | 4 | 6 | 12 | 8 | 10 | 6 | 0 | Z7 | 74x04 | 6 | hex inverter gate |  | 14
8 | 2 | 1 | 4 | 10 | 13 |  |  | 4 | 0 | Z8 | 74x02 | 4 | quad 2-input NOR gate |  | 14
9 | 8 | 8 | 6 | 11 | 3 |  |  | 4 | 0 | Z9 | 74x08 | 4 | quad 2-input AND gate |  | 14
10 | 30 |  |  |  |  |  |  | 1 | 0 | Z10 | 74x30 | 1 | single 8-input NAND gate |  | 14
11 | 10 | 12 | 6 | 8 |  |  |  | 3 | 0 | Z11 | 74x10 | 3 | triple 3-input NAND gate |  | 14
12 | 0 | 11 | 3 | 8 | 99 |  |  | 4 | 0 | Z12 | 74x00 | 4 | quad 2-input NAND gate |  | 14
13 | 10 | 8 | 6 | 12 |  |  |  | 3 | 0 | Z13 | 74x10 | 3 | triple 3-input NAND gate |  | 14
14 | 40 | 6 | 8 |  |  |  |  | 2 | 0 | Z14 | 74x40 | 2 | dual 4-input NAND gate | driver NO=30 | 14
15 | 151 |  |  |  |  |  |  | 1 | 0 | Z15 | 74x151 | 1 | 8-line to 1-line data selector/multiplexer |  | 16
16 | 20 | 8 |  |  |  |  |  | 1 | 1 | Z16 | 74x20 | 2 | dual 4-input NAND gate |  | 14
17 | 0 | 6 | 11 | 3 | 8 |  |  | 4 | 0 | Z17 | 74x00 | 4 | quad 2-input NAND gate |  | 14
18 | 10 | 6 |  |  | 99 |  |  | 2 | 1 | Z18 | 74x10 | 3 | triple 3-input NAND gate |  | 14
19 | 20 | 6 | 8 |  |  |  |  | 2 | 0 | Z19 | 74x20 | 2 | dual 4-input NAND gate |  | 14
20 | 164 |  |  |  |  |  |  | 1 | 0 | Z20 | 74x164 | 1 | 8-bit serial-in parallel-out (SIPO) shift register, asynchronous clear, not output latch |  | 14
21 | 164 |  |  |  |  |  |  | 1 | 0 | Z21 | 74x164 | 1 | 8-bit serial-in parallel-out (SIPO) shift register, asynchronous clear, not output latch |  | 14
22 | 3 | 3 | 6 | 8 | 11 |  |  | 4 | 0 | Z22 | 74x03 | 4 | quad 2-input NAND gate | open-collector | 14
23 | 2 | 1 | 4 | 10 | 13 |  |  | 4 | 0 | Z23 | 74x02 | 4 | quad 2-input NOR gate |  | 14
24 | 42 |  |  |  |  |  |  | 1 | 0 | Z24 | 74x42 | 1 | BCD to decimal decoder |  | 16
25 | 30 |  |  |  |  |  |  | 1 | 0 | Z25 | 74x30 | 1 | single 8-input NAND gate |  | 14
26 | 164 |  |  |  |  |  |  | 1 | 0 | Z26 | 74x164 | 1 | 8-bit serial-in parallel-out (SIPO) shift register, asynchronous clear, not output latch |  | 14
27 | 8 | 3 | 8 |  |  |  |  | 2 | 2 | Z27 | 74x08 | 4 | quad 2-input AND gate |  | 14
28 | 2 | 4 | 1 | 10 | 13 |  |  | 4 | 0 | Z28 | 74x02 | 4 | quad 2-input NOR gate |  | 14
29 | 3 | 3 | 6 | 8 | 11 |  |  | 4 | 0 | Z29 | 74x03 | 4 | quad 2-input NAND gate | open-collector | 14
30 | 4 | 2 |  | 6 | 8 | 10 | 12 | 5 | 1 | Z30 | 74x04 | 6 | hex inverter gate |  | 14
31 | 74 | 5 | 9 |  |  |  |  | 2 | 0 | Z31 | 74x74 | 2 | dual D positive edge triggered flip-flop, asynchronous preset and clear |  | 14
32 | 74 | 5 | 9 |  |  |  |  | 2 | 0 | Z32 | 74x74 | 2 | dual D positive edge triggered flip-flop, asynchronous preset and clear |  | 14
33 | 10 | 6 | 8 | 12 |  |  |  | 3 | 0 | Z33 | 74x10 | 3 | triple 3-input NAND gate |  | 14
34 | 74 | 8 | 5 |  |  |  |  | 2 | 0 | Z34 | 74x74 | 2 | dual D positive edge triggered flip-flop, asynchronous preset and clear |  | 14
35 | 3 | 3 | 11 | 6 | 8 |  |  | 4 | 0 | Z35 | 74x03 | 4 | quad 2-input NAND gate | open-collector | 14
36 | 10 | 6 | 8 | 12 |  |  |  | 3 | 0 | Z36 | 74x10 | 3 | triple 3-input NAND gate |  | 14
37 | 0 | 3 | 6 | 8 | 11 |  |  | 4 | 0 | Z37 | 74x00 | 4 | quad 2-input NAND gate |  | 14
38 | 20 | 6 | 8 |  |  |  |  | 2 | 0 | Z38 | 74x20 | 2 | dual 4-input NAND gate |  | 14
39 | 164 |  |  |  |  |  |  | 1 | 0 | Z39 | 74x164 | 1 | 8-bit serial-in parallel-out (SIPO) shift register, asynchronous clear, not output latch |  | 14
40 | 164 |  |  |  |  |  |  | 1 | 0 | Z40 | 74x164 | 1 | 8-bit serial-in parallel-out (SIPO) shift register, asynchronous clear, not output latch |  | 14
41 | 2 | 1 |  | 10 | 13 |  |  | 3 | 1 | Z41 | 74x02 | 4 | quad 2-input NOR gate |  | 14
42 | 0 | 3 | 6 | 11 | 8 |  |  | 4 | 0 | Z42 | 74x00 | 4 | quad 2-input NAND gate |  | 14
43 | 42 |  |  |  |  |  |  | 1 | 0 | Z43 | 74x42 | 1 | BCD to decimal decoder |  | 16
44 | 4 | 6 | 4 | 2 | 10 | 12 | 8 | 6 | 0 | Z44 | 74x04 | 6 | hex inverter gate |  | 14
45 | 30 |  |  |  |  |  |  | 1 | 0 | Z45 | 74x30 | 1 | single 8-input NAND gate |  | 14
46 | 0 | 3 | 6 | 8 | 11 |  |  | 4 | 0 | Z46 | 74x00 | 4 | quad 2-input NAND gate |  | 14
47 | 2 | 10 | 13 |  |  |  |  | 2 | 2 | Z47 | 74x02 | 4 | quad 2-input NOR gate |  | 14
48 | 5 | 12 |  | 6 | 8 |  |  | 3 | 3 | Z48 | 74x05 | 6 | hex inverter gate | open-collector | 14
49 | 4 | 2 | 6 | 4 | 10 | 8 | 12 | 6 | 0 | Z49 | 74x04 | 6 | hex inverter gate |  | 14
50 | 37 | 3 | 6 | 8 | 11 |  |  | 4 | 0 | Z50 | 74x37 | 4 | quad 2-input NAND gate | driver NO=30 | 14
51 | 2 | 1 | 4 | 10 | 13 |  |  | 4 | 0 | Z51 | 74x02 | 4 | quad 2-input NOR gate |  | 14
52 | 74 | 5 | 9 |  |  |  |  | 2 | 0 | Z52 | 74x74 | 2 | dual D positive edge triggered flip-flop, asynchronous preset and clear |  | 14
53 | 2 | 10 | 13 | 4 |  |  |  | 3 | 1 | Z53 | 74x02 | 4 | quad 2-input NOR gate |  | 14
54 | 0 | 11 | 8 | 6 | 3 |  |  | 4 | 0 | Z54 | 74x00 | 4 | quad 2-input NAND gate |  | 14
55 | 10 | 8 | 12 | 6 |  |  |  | 3 | 0 | Z55 | 74x10 | 3 | triple 3-input NAND gate |  | 14
56 | 4 | 2 | 4 | 10 | 12 | 8 | 6 | 6 | 0 | Z56 | 74x04 | 6 | hex inverter gate |  | 14
57 | 3 | 3 | 6 | 8 | 11 |  |  | 4 | 0 | Z57 | 74x03 | 4 | quad 2-input NAND gate | open-collector | 14
58 | 0 | 3 | 6 | 8 | 11 |  |  | 4 | 0 | Z58 | 74x00 | 4 | quad 2-input NAND gate |  | 14
59 | 6 | 2 | 4 |  | 8 | 10 | 12 | 5 | 1 | Z59 | 74x06 | 6 | hex inverter gate | open-collector 30 V / 40 mA | 14
60 | 3 |  |  | 8 | 11 |  |  | 2 | 2 | Z60 | 74x03 | 4 | quad 2-input NAND gate | open-collector | 14
61 | 0 | 3 | 6 | 8 | 11 |  |  | 4 | 0 | Z61 | 74x00 | 4 | quad 2-input NAND gate |  | 14
62 | 164 |  |  |  |  |  |  | 1 | 0 | Z62 | 74x164 | 1 | 8-bit serial-in parallel-out (SIPO) shift register, asynchronous clear, not output latch |  | 14
63 | 164 |  |  |  |  |  |  | 1 | 0 | Z63 | 74x164 | 1 | 8-bit serial-in parallel-out (SIPO) shift register, asynchronous clear, not output latch |  | 14
64 | 153 |  |  |  |  |  |  | 2 | 0 | Z64 | 74x153 | 2 | dual 4-line to 1-line data selector/multiplexer, non-inverting outputs |  | 16
65 | 153 |  |  |  |  |  |  | 2 | 0 | Z65 | 74x153 | 2 | dual 4-line to 1-line data selector/multiplexer, non-inverting outputs |  | 16
66 | 164 |  |  |  |  |  |  | 1 | 0 | Z66 | 74x164 | 1 | 8-bit serial-in parallel-out (SIPO) shift register, asynchronous clear, not output latch |  | 14
67 | 164 |  |  |  |  |  |  | 1 | 0 | Z67 | 74x164 | 1 | 8-bit serial-in parallel-out (SIPO) shift register, asynchronous clear, not output latch |  | 14
68 | 0 | 3 | 6 | 8 | 11 |  |  | 4 | 0 | Z68 | 74x00 | 4 | quad 2-input NAND gate |  | 14
69 | 74 | 5 | 9 |  |  |  |  | 2 | 0 | Z69 | 74x74 | 2 | dual D positive edge triggered flip-flop, asynchronous preset and clear |  | 14
70 | 74 | 5 | 9 |  |  |  |  | 2 | 0 | Z70 | 74x74 | 2 | dual D positive edge triggered flip-flop, asynchronous preset and clear |  | 14
71 | 74 | 5 | 9 |  |  |  |  | 2 | 0 | Z71 | 74x74 | 2 | dual D positive edge triggered flip-flop, asynchronous preset and clear |  | 14
72 | 4 | 12 | 8 | 10 | 4 | 2 | 6 | 6 | 0 | Z72 | 74x04 | 6 | hex inverter gate |  | 14
73 | 4 | 10 | 8 | 6 | 4 | 2 | 12 | 6 | 0 | Z73 | 74x04 | 6 | hex inverter gate |  | 14
74 | 8 | 3 | 6 | 8 |  |  |  | 3 | 1 | Z74 | 74x08 | 4 | quad 2-input AND gate |  | 14
75 | 2 | 10 | 13 | 4 | 1 |  |  | 4 | 0 | Z75 | 74x02 | 4 | quad 2-input NOR gate |  | 14
76 | 30 | 8 |  |  |  |  |  | 1 | 0 | Z76 | 74x30 | 1 | single 8-input NAND gate |  | 14
77 | 10 | 12 | 8 | 6 |  |  |  | 3 | 0 | Z77 | 74x10 | 3 | triple 3-input NAND gate |  | 14
78 | 4 | 12 | 10 | 2 |  |  |  | 3 | 3 | Z78 | 74x04 | 6 | hex inverter gate |  | 14
79 | 0 | 3 | 6 | 11 | 8 |  |  | 4 | 0 | Z79 | 74x00 | 4 | quad 2-input NAND gate |  | 14
80 | 153 |  |  |  |  |  |  | 2 | 0 | Z80 | 74x153 | 2 | dual 4-line to 1-line data selector/multiplexer, non-inverting outputs |  | 16
81 | 153 |  |  |  |  |  |  | 2 | 0 | Z81 | 74x153 | 2 | dual 4-line to 1-line data selector/multiplexer, non-inverting outputs |  | 16
82 | 4 | 4 | 6 | 8 | 10 | 2 |  | 5 | 1 | Z82 | 74x04 | 6 | hex inverter gate |  | 14
83 | 4 | 4 | 6 | 8 | 10 |  |  | 4 | 2 | Z83 | 74x04 | 6 | hex inverter gate |  | 14
84 | 153 |  |  |  |  |  |  | 2 | 0 | Z84 | 74x153 | 2 | dual 4-line to 1-line data selector/multiplexer, non-inverting outputs |  | 16
85 | 153 |  |  |  |  |  |  | 2 | 0 | Z85 | 74x153 | 2 | dual 4-line to 1-line data selector/multiplexer, non-inverting outputs |  | 16
86 | 0 | 3 | 6 | 8 | 11 |  |  | 4 | 0 | Z86 | 74x00 | 4 | quad 2-input NAND gate |  | 14
87 | 73 | 9 | 12 |  |  |  |  | 2 | 0 | Z87 | 74x73 | 2 | dual J-K flip-flop, asynchronous clear |  | 14
88 | 0 | 3 | 6 | 11 | 8 |  |  | 4 | 0 | Z88 | 74x00 | 4 | quad 2-input NAND gate |  | 14
89 | 3 | 8 | 6 | 11 | 3 |  |  | 4 | 0 | Z89 | 74x03 | 4 | quad 2-input NAND gate | open-collector | 14
90 | 95 |  |  |  |  |  |  | 1 | 0 | Z90 | 74x95 | 1 | 4-bit shift register, parallel in, parallel out, serial input; different pinout for 74L95 |  | 14
91 | 95 |  |  |  |  |  |  | 1 | 0 | Z91 | 74x95 | 1 | 4-bit shift register, parallel in, parallel out, serial input; different pinout for 74L95 |  | 14
92 | 3 | 6 | 3 | 11 | 8 |  |  | 4 | 0 | Z92 | 74x03 | 4 | quad 2-input NAND gate | open-collector | 14
93 | 10 | 6 | 8 | 12 |  |  |  | 3 | 0 | Z93 | 74x10 | 3 | triple 3-input NAND gate |  | 14
94 | 42 |  |  |  |  |  |  | 1 | 0 | Z94 | 74x42 | 1 | BCD to decimal decoder |  | 16
95 | 89 |  |  |  |  |  |  | 1 | 0 | Z95 | 74x89 | 1 | 64-bit RAM (16x4), 4 data inputs, 4 inverted data outputs | open-collector | 16
96 | 89 |  |  |  |  |  |  | 1 | 0 | Z96 | 74x89 | 1 | 64-bit RAM (16x4), 4 data inputs, 4 inverted data outputs | open-collector | 16
97 | 89 |  |  |  |  |  |  | 1 | 0 | Z97 | 74x89 | 1 | 64-bit RAM (16x4), 4 data inputs, 4 inverted data outputs | open-collector | 16
98 | 89 |  |  |  |  |  |  | 1 | 0 | Z98 | 74x89 | 1 | 64-bit RAM (16x4), 4 data inputs, 4 inverted data outputs | open-collector | 16
99 | 4 | 12 | 8 | 6 | 4 |  |  | 4 | 2 | Z99 | 74x04 | 6 | hex inverter gate |  | 14
100 | 193 |  |  |  |  |  |  | 1 | 0 | Z100 | 74x193 | 1 | synchronous presettable up/down 4-bit binary counter, clear |  | 16
101 | 193 |  |  |  |  |  |  | 1 | 0 | Z101 | 74x193 | 1 | synchronous presettable up/down 4-bit binary counter, clear |  | 16
102 | 4 | 2 | 6 | 8 | 10 | 12 | 4 | 6 | 0 | Z102 | 74x04 | 6 | hex inverter gate |  | 14
103 | 3 | 3 |  | 8 | 11 |  |  | 3 | 1 | Z103 | 74x03 | 4 | quad 2-input NAND gate | open-collector | 14
104 | 6 | 2 | 8 | 10 | 12 |  |  | 4 | 2 | Z104 | 74x06 | 6 | hex inverter gate | open-collector 30 V / 40 mA | 14
105 | 6 | 6 | 2 | 8 | 10 | 12 |  | 5 | 1 | Z105 | 74x06 | 6 | hex inverter gate | open-collector 30 V / 40 mA | 14
106 | 74 | 9 |  |  |  |  |  | 1 | 1 | Z106 | 74x74 | 2 | dual D positive edge triggered flip-flop, asynchronous preset and clear |  | 14
107 | 3 | 6 | 3 | 8 | 11 |  |  | 4 | 0 | Z107 | 74x03 | 4 | quad 2-input NAND gate | open-collector | 14
108 | 40 | 6 | 8 |  |  |  |  | 2 | 0 | Z108 | 74x40 | 2 | dual 4-input NAND gate | driver NO=30 | 14
109 | 193 |  |  |  |  |  |  | 1 | 0 | Z109 | 74x193 | 1 | synchronous presettable up/down 4-bit binary counter, clear |  | 16
110 | 193 |  |  |  |  |  |  | 1 | 0 | Z110 | 74x193 | 1 | synchronous presettable up/down 4-bit binary counter, clear |  | 16
111 | 193 |  |  |  |  |  |  | 1 | 0 | Z111 | 74x193 | 1 | synchronous presettable up/down 4-bit binary counter, clear |  | 16
112 | 193 |  |  |  |  |  |  | 1 | 0 | Z112 | 74x193 | 1 | synchronous presettable up/down 4-bit binary counter, clear |  | 16
113 | 153 |  |  |  |  |  |  | 2 | 0 | Z113 | 74x153 | 2 | dual 4-line to 1-line data selector/multiplexer, non-inverting outputs |  | 16
114 | 85 |  |  |  |  |  |  | 1 | 0 | Z114 | 74x85 | 1 | 4-bit magnitude comparator |  | 16
115 | 85 |  |  |  |  |  |  | 1 | 0 | Z115 | 74x85 | 1 | 4-bit magnitude comparator |  | 16
116 | 8 | 3 | 6 | 8 |  |  |  | 3 | 1 | Z116 | 74x08 | 4 | quad 2-input AND gate |  | 14
117 | 40 | 6 | 8 |  |  |  |  | 2 | 0 | Z117 | 74x40 | 2 | dual 4-input NAND gate | driver NO=30 | 14

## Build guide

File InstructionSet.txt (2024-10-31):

DataPoint 2200 Instruction Set
---
Also includes data for the Intel 8008 processor

Where two opcodes are given separated by a forward slash the second is the 
alternate spelling for the 8008.
Where there is a forward slash with only one opcode given the opcode is only 
available on either Datapoint (before slash) or 8008 (after slash).

Hex Oct Opcode/8008 Opcode
00  000 HALT/HLT    ;Halt
01  001 HALT/HLT
02  002 SLC/RLC     ;Shift left circular/Rotate accumulator left
					;Bit 7 to Carry flag. Bit 7 to Bit 0.
03  003 RFC         ;Return if not carry
04  004 AD n/ADI n  ;Add immediate
05  005 /RST &00    ;Call &0000
06  006 LA n/LAI n  ;Load A immediate
07  007 RETURN/RET  ;Return from subroutine. Middle octal digit is ignored on 8008, so maps to 007,017,027,037,047,057,067,077

08  010 /INB        ;Inc B (Note: there is no INA or INM opcode)
09  011 /DCB        ;Dec B (Note: there is no DCA or DCM opcode)
0A  012 SRC/RRC     ;Shift right circular (through carry)/Rotate accumulator right
					;Bit 0 to Carry flag, Bit 0 to Bit 7.
0B  013 RFZ         ;Return if not zero
0C  014 AC n/ACI n  ;Add immediate with carry
0D  015 /RST &08    ;Call &0008
0E  016 LB n/LBI n  ;Load B immediate

10  020 BETA/INC    ;Switch to Beta register set. Version 2 only. (Inc C on 8008)
11  021 /DCC        ;Dec C
12  022 /RAL        ;Rotate accumulator left through carry
13  023 RFS         ;Return if not sign
14  024 SU n/SUI n  ;Subtract immediate
15  025 /RST &10    ;Call &0010
16  026 LC n/LCI n  ;Load C immediate

18  030 ALPHA/IND   ;Switch to alpha register set. Version 2 only. (Inc D on 8008)
19  031 /DCD        ;Dec D
1A  032 /RRL        ;Rotate accumulator right through carry
1B  033 RFP         ;Return if not parity
1C  034 SB n/SBI n  ;Subtract immediate with borrow
1D  035 /RST &18    ;Call &0018
1E  036 LD n/LDI n  ;Load D immediate

20  040 DI/INE      ;Disable interrupts. Version 2 only. (Inc E on 8008)
21  041 /DCE        ;Dec E

23  043 RTC         ;Return if carry
24  044 ND n/NDI n  ;AND immediate
25  045 /RST &20    ;Call &0020
26  046 LE n/LEI n  ;Load E immediate

28  050 EI/INH      ;Enable interrupts. Version 2 only. (Inc H on 8008)
29  051 /DCH        ;Dec H

2B  053 RTZ         ;Return if zero
2C  054 XR n/XRI n  ;XOR immediate
2D  055 /RST &28    ;Call &0028
2E  056 LH n/LHI n  ;Load H immediate

30  060 POP/INL     ;Pop HL. Version 2 only. (Inc L on 8008)
31  061 /DCL        ;Dec L

33  063 RTS         ;Return if sign
34  064 OR n/ORI n  ;OR immediate
35  065 /RST &30    ;Call &0030
36  066 LL n/LLI n  ;Load L immediate

38  070 PUSH/       ;Push HL. Version 2 only

3B  073 RTP         ;Return if parity
3C  074 CP n/CPI n  ;Compare immediate
3D  075 /RST &0038  ;Call &0030

3F  077 LM n/LMI n  ;To (HL) location with immediate data

40  100 JFC nn              ;Jump if not carry
41  101 INPUT/INP 0         ;Reads IO bus into A/Input from port 0
42  102 CFC nn              ;Call if not carry
43  103 /INP 1              ;Input from port 1
44  104 JMP nn              ;Unconditional jump. Middle octal digit is ignored on 8008, so maps to 104,114,124,134,144,154,164,174
45  105 /INP 2              ;Input from port 2
46  106 CALL nn             ;Subroutine call. Middle octal digit is ignored on 8008, so maps to 106,116,126,136,146,156,166,176
47  107 /INP 3              ;Input from port 3
48  110 JFZ nn              ;Jump if not zero
49  111 /INP 4              ;Input from port 4
4A  112 CFZ nn              ;Call if not zero
4B  113 /INP 5              ;Input from port 5

4D  115 /INP 6              ;Input from port 6

4F  117 /INP 7              ;Input from port 7
50  120 JFS nn              ;Jump if not sign
51  121 EX ADR/OUT 0        ;1 Address. Selects device specified by A register. All device addresses. (Output to port 0)
52  122 CFS nn              ;Call if not sign
53  123 EX STATUS/OUT 1     ;2 Sense status. Connects selected device status to input lines. All device addresses (Output to port 1)

55  125 EX DATA/OUT 2       ;3 Sense data. Connects selected device data to input lines. All device addresses (Output to port 2)

57  127 EX WRITE/OUT 3      ;4 Write strobe. Signals selected device that output data word is on output lines. All device addresses (Output to port 3)
58  130 JFP nn              ;Jump if not parity
59  131 EX COM1/OUT 4       ;5 Command1. Outputs a control function to selected device. All device addresses (Output to port 4)
5A  132 CFP nn              ;Call if not parity
5B  133 EX COM2/OUT 5       ;6 Command2. Outputs a control function to selected device. All device addresses (Output to port 5)

5D  135 EX COM3/OUT 6       ;7 Command3. Outputs a control function to selected device. All device addresses (Output to port 6)

5F  137 EX COM4/OUT 7       ;8 Command4. Outputs a control function to selected device. All device addresses (Output to port 7)
60  140 JTC nn              ;Jump if carry
61  141 /OUT 8              ;9 EX unassigned (Output to port 8)
62  142 CTC nn              ;Call if carry
63  143 /OUT 9              ;10 EX unassigned (Output to port 9)

65  145 /OUT 10             ;11 EX unassigned (Output to port 10)

67  147 /OUT 11             ;12 EX unassigned (Output to port 11)
68  150 JTZ nn              ;Jump if zero
69  151 EX BEEP/OUT 12      ;13 Beep. Activates tone producing mechanism. Device address 341(octal) (Output to port 12)
6A  152 CTZ nn              ;Call if zero
6B  153 EX CLICK/OUT 13     ;14 Click. Activates audible click producing mechanism. Device address 341(octal) (Output to port 13)

6D  155 EX DECK1/OUT 14     ;15 Select Deck 1. Connects deck 1 to I/O bus. Device address 360(octal) (Output to port 14)

6F  157 EX DECK2/OUT 15     ;16 Select Deck 2. Connects deck 2 to I/O bus. Device address 360(octal) (Output to port 15)
70  160 JTS nn              ;Jump if sign
71  161 EX RBK/OUT 16       ;17 Read block. Enables read circuitry and sets tape in forward motion. Device address 360(octal) (Output to port 16)
72  162 CTS nn              ;Call if sign
73  163 EX WBK/OUT 17       ;18 Write block. Enables write circuitry and sets tape in forward motion. Device address 360(octal) (Output to port 17)

75  165 /OUT 18             ;19 EX unassigned (Output to port 18)

77  167 EX BSP/OUT 19       ;20 Backspace one block. Backs up the selected tape one record. Device address 360(octal) (Output to port 19)
78  170 JTP nn              ;Jump if parity
79  171 EX SF/OUT 20        ;21 Slew forward. Sets selected tape deck in forward motion. Device address 360(octal) (Output to port 20)
7A  172 CTP nn              ;Call if parity
7B  173 EX SB/OUT 21        ;22 Slew backward. Set selected tape deck in backward motion. Device address 360(octal) (Output to port 21)

7D  175 EX REWIND/OUT 22    ;23 Rewind. Rewinds the selected deck to beginning of tape. Device address 360(octal) (Output to port 22)

7F  177 EX TSTOP/OUT 23     ;24 Stop tape. Halts motion of the selected tape deck. Device address 360(octal) (Output to port 23)

80  200 ADA     ;Add A
81  201 ADB     ;Add B
82  202 ADC     ;Add C
83  203 ADD     ;Add D
84  204 ADE     ;Add E
85  205 ADH     ;Add H
86  206 ADL     ;Add L
87  207 ADM     ;Add data at (HL)
88  210 ACA     ;Add with carry
89  211 ACB
8A  212 ACC
8B  213 ACD
8C  214 ACE
8D  215 ACH
8E  216 ACL
8F  217 ACM     ;Add data at (HL)
90  220 SUA     ;Subtract
91  221 SUB
92  222 SUC
93  223 SUD
94  224 SUE
95  225 SUH
96  226 SUL
97  227 SUM     ;Data at (HL)
98  230 SBA     ;Subtract with borrow
99  231 SBB
9A  232 SBC
9B  233 SBD
9C  234 SBE
9D  235 SBH
9E  236 SBL
9F  237 SBM     ;Data at (HL)
A0  240 NDA     ;AND
A1  241 NDB
A2  242 NDC
A3  243 NDD
A4  244 NDE
A5  245 NDH
A6  246 NDL
A7  247 NDM     ;Data at (HL)
A8  250 XRA     ;XOR
A9  251 XRB
AA  252 XRC
AB  253 XRD
AC  254 XRE
AD  255 XRH
AE  256 XRL
AF  257 XRM     ;Data at (HL)
B0  260 ORA     ;OR
B1  261 ORB
B2  262 ORC
B3  263 ORD
B4  264 ORE
B5  265 ORH
B6  266 ORL
B7  267 ORM     ;Data at (HL)
B8  270 CPA     ;Compare
B9  271 CPB
BA  272 CPC
BB  273 CPD
BC  274 CPE
BD  275 CPH
BE  276 CPL
BF  277 CPM     ;Data at (HL)
   
C0  300 NOP     ;NOP (applies to all 'load into same register' opcodes). LAA on 8008.
C1  301 LAB     ;<dest><source>
C2  302 LAC
C3  303 LAD
C4  304 LAE
C5  305 LAH
C6  306 LAL
C7  307 LAM     ;Source is (HL) location
C8  310 LBA
C9  311 LBB
CA  312 LBC
CB  313 LBD
CC  314 LBE
CD  315 LBH
CE  316 LBL
CF  317 LBM     ;Source is (HL) location
D0  320 LCA
D1  321 LCB
D2  322 LCC
D3  323 LCD
D4  324 LCE
D5  325 LCH
D6  326 LCL
D7  327 LCM     ;Source is (HL) location
D8  330 LDA
D9  331 LDB
DA  332 LDC
DB  333 LDD
DC  334 LDE
DD  335 LDH
DE  336 LDL
DF  337 LDM     ;Source is (HL) location
E0  340 LEA
E1  341 LEB
E2  342 LEC
E3  343 LED
E4  344 LEE
E5  345 LEH
E6  346 LEL
E7  347 LEM     ;Source is (HL) location
E8  350 LHA
E9  351 LHB
EA  352 LHC
EB  353 LHD
EC  354 LHE
ED  355 LHH
EE  356 LHL
EF  357 LHM     ;Source is (HL) location
F0  360 LLA
F1  361 LLB
F2  362 LLC
F3  363 LLD
F4  364 LLE
F5  365 LLH     
F6  366 LLL
F7  367 LLM     ;Source is (HL) location
F8  370 LMA     ;Dest is memory at (HL)
F9  371 LMB     ;Dest is memory at (HL)
FA  372 LMC     ;Dest is memory at (HL)
FB  373 LMD     ;Dest is memory at (HL)
FC  374 LME     ;Dest is memory at (HL)
FD  375 LMH     ;Dest is memory at (HL)
FE  376 LML     ;Dest is memory at (HL)
FF  377 HALT/HLT

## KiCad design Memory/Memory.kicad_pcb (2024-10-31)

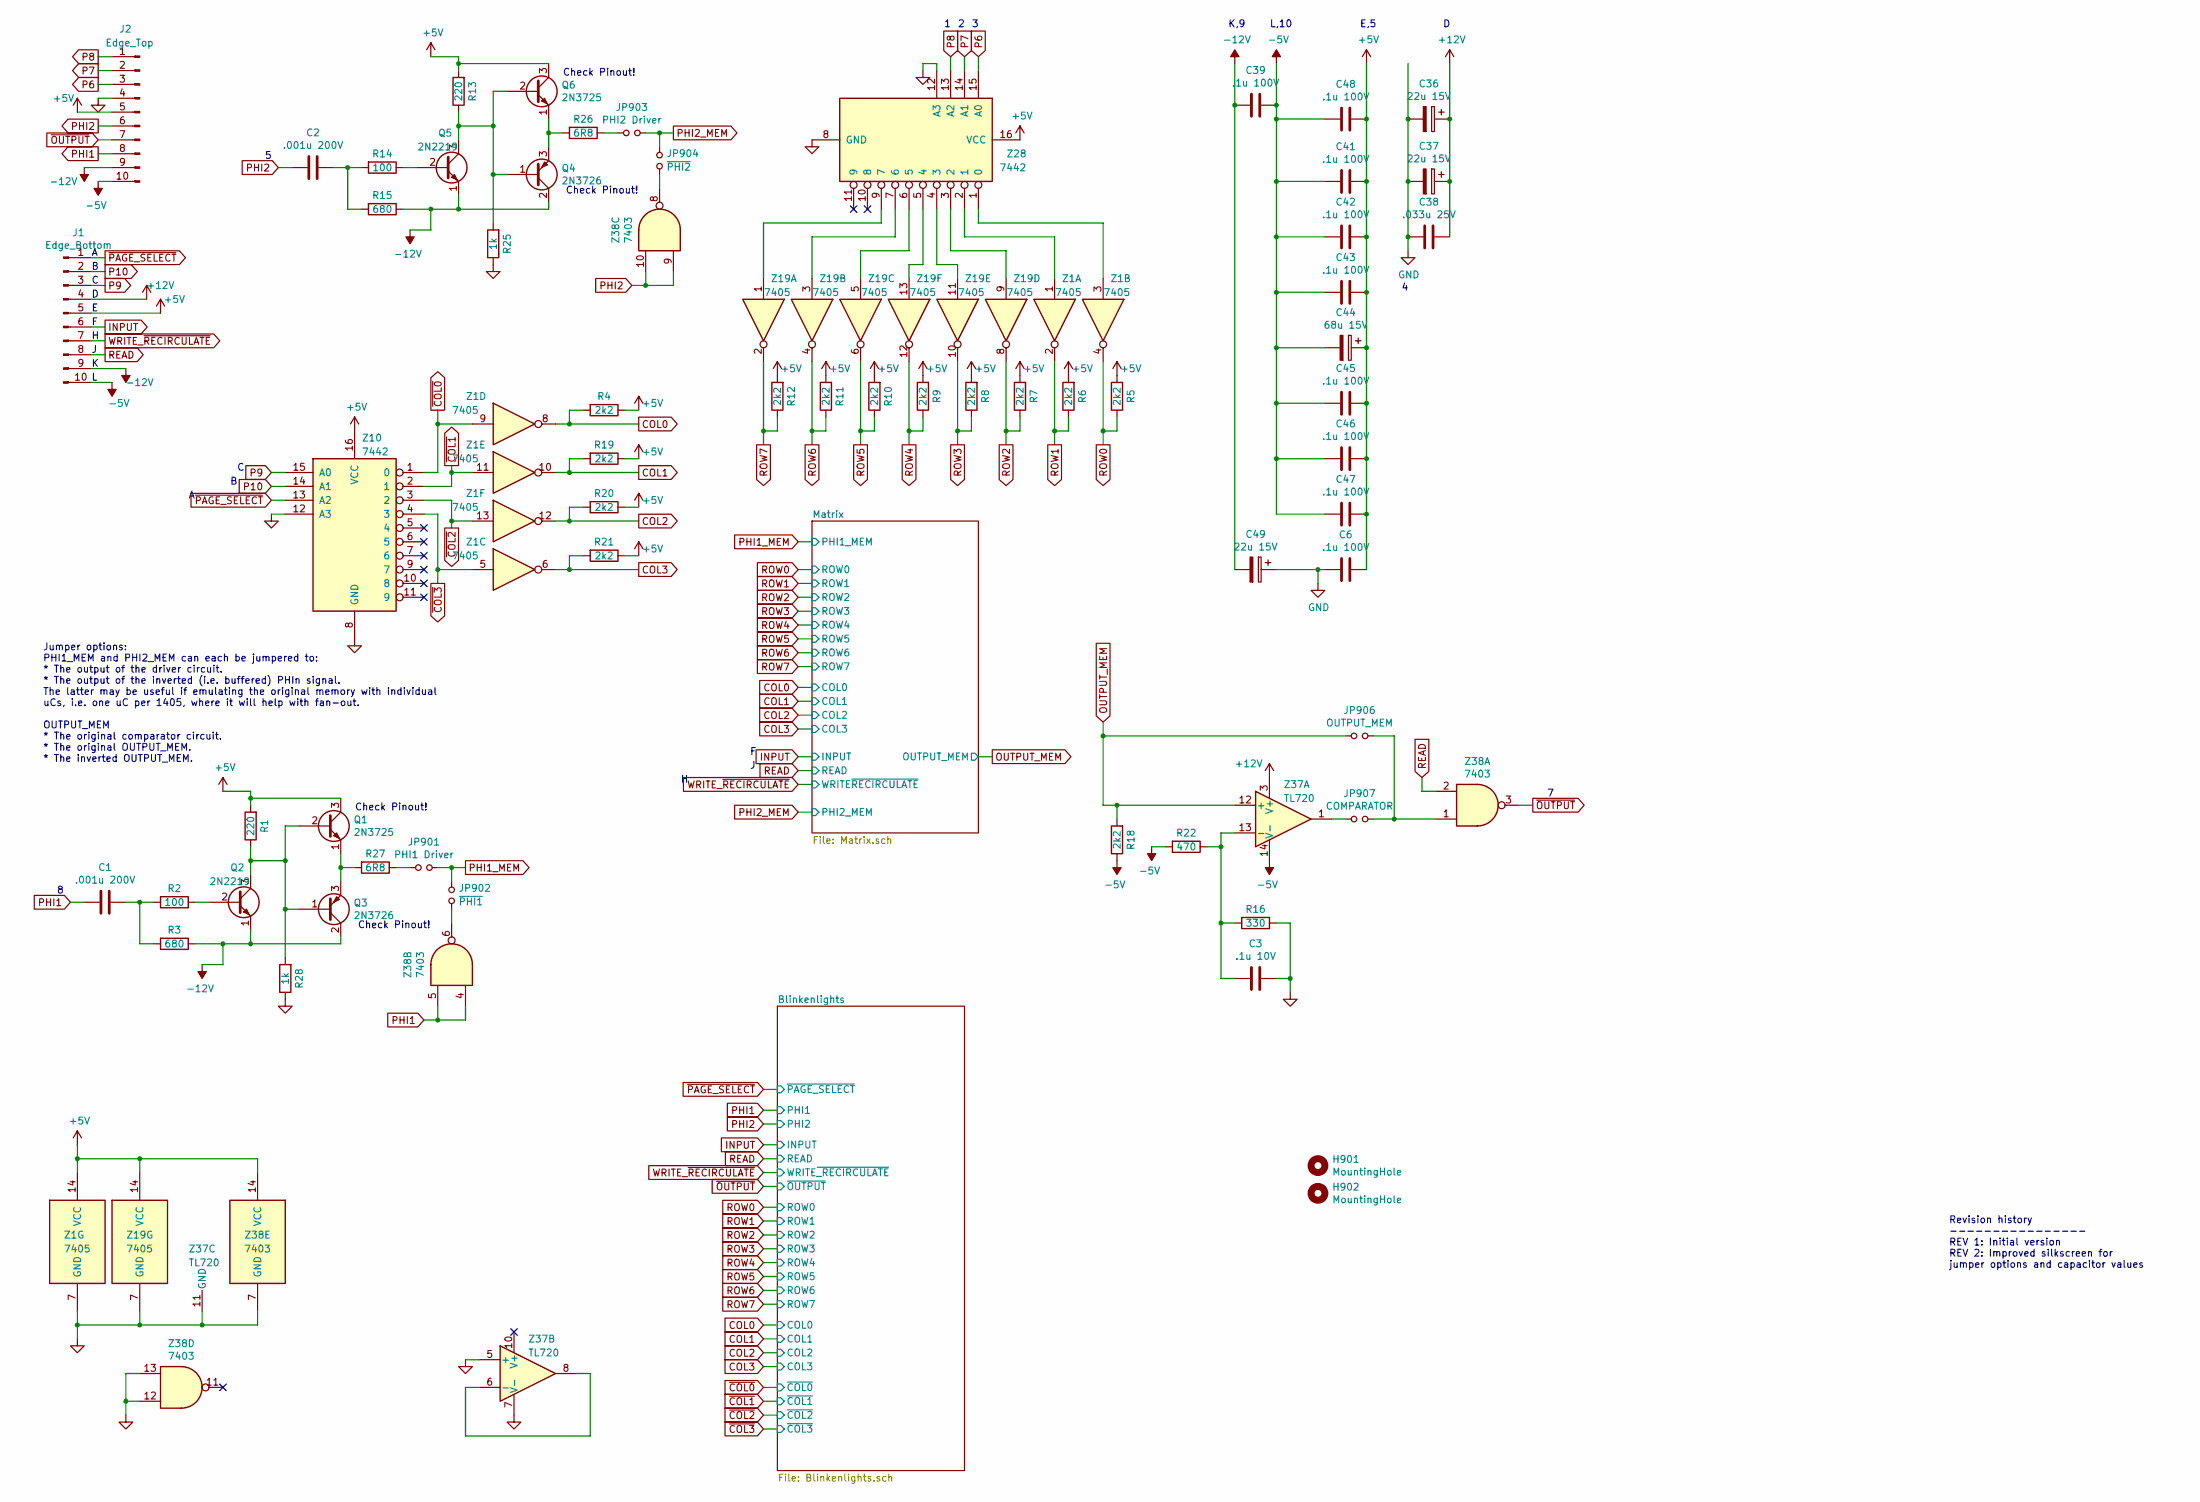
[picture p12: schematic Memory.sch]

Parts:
C1, C2: .001u 200V; C_Disc_D4.7mm_W2.5mm_P5.00mm
C3: .1u 10V; C_Disc_D7.0mm_W2.5mm_P5.00mm
C6, C39, C41, C42, C43, C45, C46, C47, C48: .1u 100V; C_Disc_D7.0mm_W2.5mm_P5.00mm
C36, C37, C49: 22u 15V; CP_Radial_D5.0mm_P2.50mm
C38: .033u 25V; C_Disc_D4.7mm_W2.5mm_P5.00mm
C44: 68u 15V; CP_Radial_D6.3mm_P2.50mm
H901, H902: MountingHole; MountingHole_3.2mm_M3
J1: Edge_Bottom; EdgeConn_10_Pin_Pitch_3.96mm
J2: Edge_Top; EdgeConn_10_Pin_Pitch_3.96mm
JP901: PHI1 Driver; SolderJumper-2_P1.3mm_Open_RoundedPad1.0x1.5mm
JP902: ~PHI1; SolderJumper-2_P1.3mm_Open_RoundedPad1.0x1.5mm
JP903: PHI2 Driver; SolderJumper-2_P1.3mm_Open_RoundedPad1.0x1.5mm
JP904: ~PHI2; SolderJumper-2_P1.3mm_Open_RoundedPad1.0x1.5mm
JP906: OUTPUT_MEM; SolderJumper-2_P1.3mm_Open_RoundedPad1.0x1.5mm
JP907: COMPARATOR; SolderJumper-2_P1.3mm_Open_RoundedPad1.0x1.5mm
Q1, Q6: 2N3725; TO-39-3
Q2, Q5: 2N2219; TO-39-3
Q3, Q4: 2N3726; TO-39-3
R1, R13: 220; R_Axial_DIN0207_L6.3mm_D2.5mm_P10.16mm_Horizontal
R2, R14: 100; R_Axial_DIN0207_L6.3mm_D2.5mm_P10.16mm_Horizontal
R3, R15: 680; R_Axial_DIN0207_L6.3mm_D2.5mm_P10.16mm_Horizontal
R4, R5, R6, R7, R8, R9, R10, R11, R12, R18, R19, R20, R21: 2k2; R_Axial_DIN0207_L6.3mm_D2.5mm_P10.16mm_Horizontal
R16: 330; R_Axial_DIN0207_L6.3mm_D2.5mm_P10.16mm_Horizontal
R22: 470; R_Axial_DIN0207_L6.3mm_D2.5mm_P10.16mm_Horizontal
R25, R28: 1k; R_Axial_DIN0207_L6.3mm_D2.5mm_P10.16mm_Horizontal
R26, R27: 6R8; R_Axial_DIN0207_L6.3mm_D2.5mm_P10.16mm_Horizontal
Z1, Z19: 7405; DIP-14_W7.62mm_Socket
Z10, Z28: 7442; DIP-16_W7.62mm_Socket
Z37: TL720; DIP-14_W7.62mm_Socket
Z38: 7403; DIP-14_W7.62mm_Socket

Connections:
+5V: C6.1, C41.1, C42.1, C43.1, C44.1, C45.1, C46.1, C47.1, C48.1, J1.5, J2.5, Q1.3 (C), Q6.3 (C), R1.2, R4.1, R5.2, R6.2, R7.2, R8.2, R9.2, R10.2, R11.2, R12.2, R13.2, R19.1, R20.1, R21.1, Z1.14 (VCC), Z10.16 (VCC), Z19.14 (VCC), Z28.16 (VCC), Z38.14 (VCC); also elsewhere on the board
+12V: C36.1, C37.1, C38.1, J1.4, Z37.3 (V+)
-5V: C39.1, C41.2, C42.2, C43.2, C44.2, C45.2, C46.2, C47.2, C48.2, J1.10, J2.10, R18.1, R22.2, Z37.14 (V-); also elsewhere on the board
-12V: C39.2, C49.2, J1.9, J2.9, Q2.1 (E), Q3.2 (C), Q4.2 (C), Q5.1 (E), R3.1, R15.1
COL0: R4.2, Z1.8; also elsewhere on the board
COL1: R19.2, Z1.10; also elsewhere on the board
COL2: R20.2, Z1.12; also elsewhere on the board
COL3: R21.2, Z1.6; also elsewhere on the board
GND: C3.1, C6.2, C36.2, C37.2, C38.2, C49.1, J2.4, R16.1, R25.1, R28.1, Z1.7 (GND), Z10.8 (GND), Z10.12 (A3), Z19.7 (GND), Z28.8 (GND), Z28.12 (A3), Z37.5 (+), Z37.7 (V-), Z37.11 (GND), Z38.7 (GND), Z38.12, Z38.13; also elsewhere on the board
INPUT: J1.6; also elsewhere on the board
unnamed: C1.1, R2.2, R3.2
unnamed: C2.1, R14.2, R15.2
unnamed: C3.2, R16.2, R22.1, Z37.13 (-)
unnamed: JP901.1, R27.1
unnamed: JP902.2, Z38.6
unnamed: JP903.1, R26.1
unnamed: JP904.2, Z38.8
unnamed: JP906.1, JP907.1, Z38.1
unnamed: JP907.2, Z37.1
unnamed: Q1.1 (E), Q3.3 (E), R27.2
unnamed: Q1.2 (B), Q2.3 (C), Q3.1 (B), R1.1, R28.2
unnamed: Q2.2 (B), R2.1
unnamed: Q4.1 (B), Q5.3 (C), Q6.2 (B), R13.1, R25.2
unnamed: Q4.3 (E), Q6.1 (E), R26.2
unnamed: Q5.2 (B), R14.1
unnamed: Z1.1, Z28.2 (1)
unnamed: Z1.3, Z28.1 (0)
unnamed: Z19.1, Z28.9 (7)
unnamed: Z19.3, Z28.7 (6)
unnamed: Z19.5, Z28.6 (5)
unnamed: Z19.9, Z28.3 (2)
unnamed: Z19.11, Z28.4 (3)
unnamed: Z19.13, Z28.5 (4)
unnamed: Z37.6 (-), Z37.8
OUTPUT_MEM: JP906.2, R18.2, Z37.12 (+); also elsewhere on the board
P6: J2.3, Z28.15 (A0)
P7: J2.2, Z28.14 (A1)
P8: J2.1, Z28.13 (A2)
P9: J1.3, Z10.15 (A0)
P10: J1.2, Z10.14 (A1)
PHI1: C1.2, J2.8, Z38.4, Z38.5; also elsewhere on the board
PHI1_MEM: JP901.2, JP902.1; also elsewhere on the board
PHI2: C2.2, J2.6, Z38.9, Z38.10; also elsewhere on the board
PHI2_MEM: JP903.2, JP904.1; also elsewhere on the board
READ: J1.8, Z38.2; also elsewhere on the board
ROW0: R5.1, Z1.4; also elsewhere on the board
ROW1: R6.1, Z1.2; also elsewhere on the board
ROW2: R7.1, Z19.8; also elsewhere on the board
ROW3: R8.1, Z19.10; also elsewhere on the board
ROW4: R9.1, Z19.12; also elsewhere on the board
ROW5: R10.1, Z19.6; also elsewhere on the board
ROW6: R11.1, Z19.4; also elsewhere on the board
ROW7: R12.1, Z19.2; also elsewhere on the board
WRITE_~RECIRCULATE: J1.7; also elsewhere on the board
~COL0: Z1.9, Z10.1 (0); also elsewhere on the board
~COL1: Z1.11, Z10.2 (1); also elsewhere on the board
~COL2: Z1.13, Z10.3 (2); also elsewhere on the board
~COL3: Z1.5, Z10.4 (3); also elsewhere on the board
~OUTPUT: J2.7, Z38.3; also elsewhere on the board
~PAGE_SELECT: J1.1, Z10.13 (A2); also elsewhere on the board

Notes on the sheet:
Check Pinout!
K,9
L,10
E,5
Jumper options: PHI1_MEM and PHI2_MEM can each be jumpered to: * The output of the driver circuit. * The output of the inverted (i.e. buffered) PHIn signal. The latter may be useful if emulating the original memory with individual uCs, i.e. one uC per 1405, where it will help with fan-out. OUTPUT_M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
Revision history ---------------- REV 1: Initial version REV 2: Improved silkscreen for jumper options and capacitor values

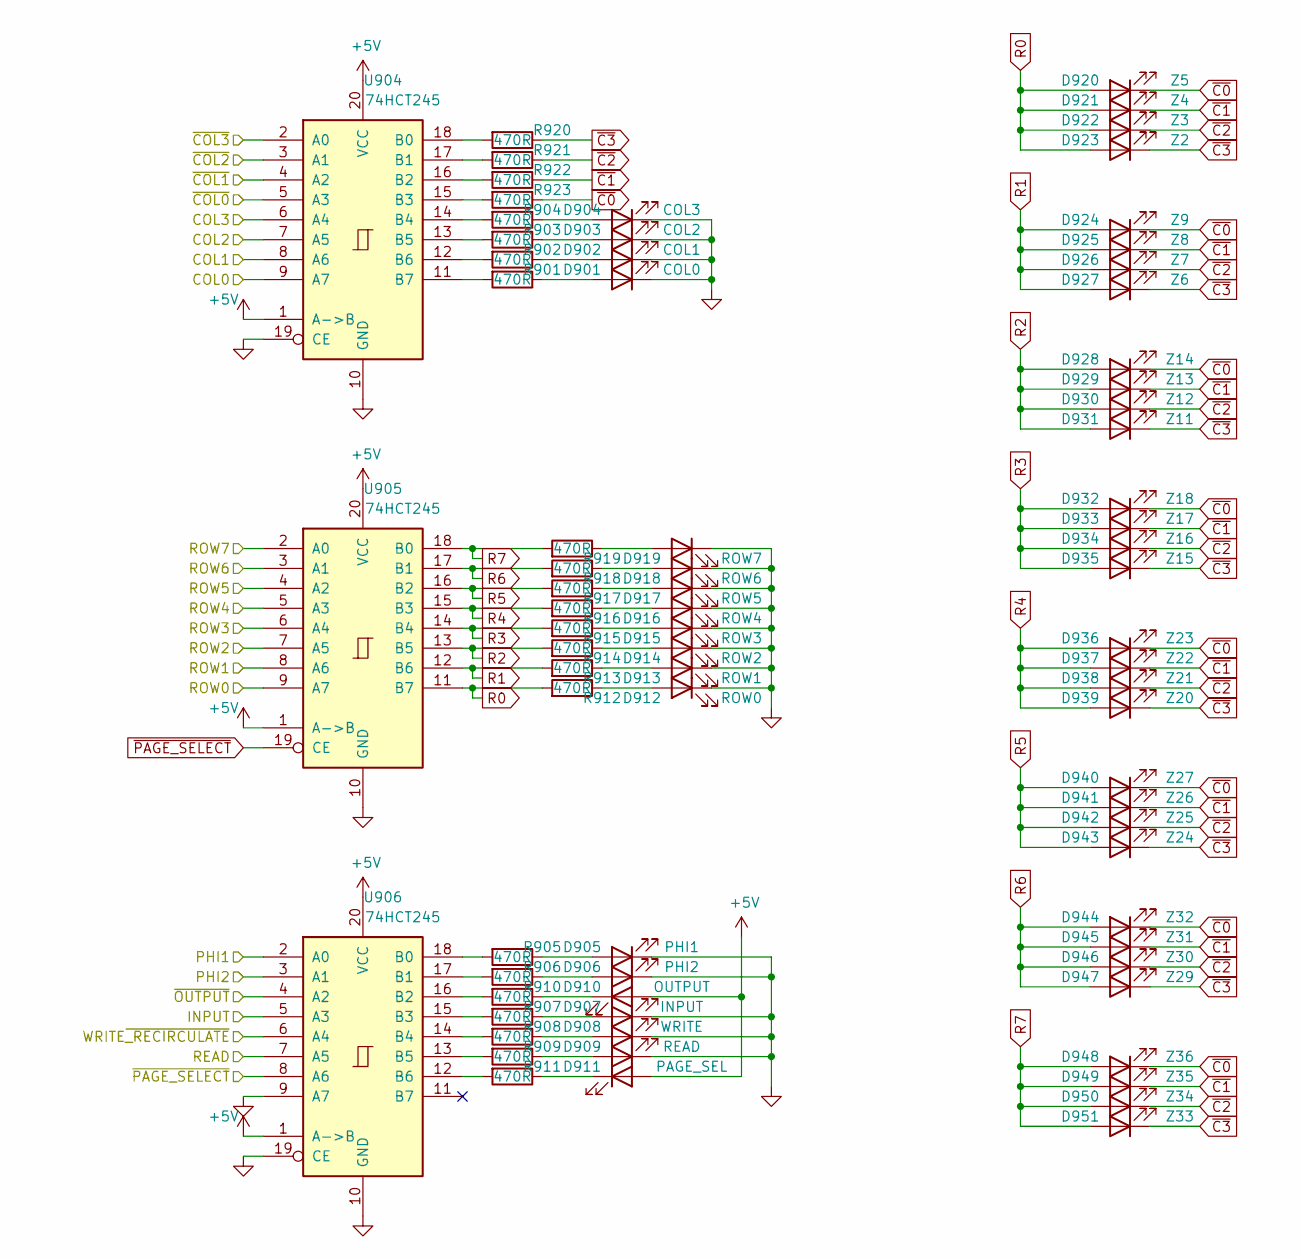
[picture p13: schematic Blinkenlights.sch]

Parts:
D901: COL0; LED_Dialight_597_xxxx_407F_SMT_RA_3mmx2mmx1mm
D902: COL1; LED_Dialight_597_xxxx_407F_SMT_RA_3mmx2mmx1mm
D903: COL2; LED_Dialight_597_xxxx_407F_SMT_RA_3mmx2mmx1mm
D904: COL3; LED_Dialight_597_xxxx_407F_SMT_RA_3mmx2mmx1mm
D905: PHI1; LED_Dialight_597_xxxx_407F_SMT_RA_3mmx2mmx1mm
D906: PHI2; LED_Dialight_597_xxxx_407F_SMT_RA_3mmx2mmx1mm
D907: INPUT; LED_Dialight_597_xxxx_407F_SMT_RA_3mmx2mmx1mm
D908: WRITE; LED_Dialight_597_xxxx_407F_SMT_RA_3mmx2mmx1mm
D909: READ; LED_Dialight_597_xxxx_407F_SMT_RA_3mmx2mmx1mm
D910: OUTPUT; LED_Dialight_597_xxxx_407F_SMT_RA_3mmx2mmx1mm
D911: PAGE_SEL; LED_Dialight_597_xxxx_407F_SMT_RA_3mmx2mmx1mm
D912: ROW0; LED_Dialight_597_xxxx_407F_SMT_RA_3mmx2mmx1mm
D913: ROW1; LED_Dialight_597_xxxx_407F_SMT_RA_3mmx2mmx1mm
D914: ROW2; LED_Dialight_597_xxxx_407F_SMT_RA_3mmx2mmx1mm
D915: ROW3; LED_Dialight_597_xxxx_407F_SMT_RA_3mmx2mmx1mm
D916: ROW4; LED_Dialight_597_xxxx_407F_SMT_RA_3mmx2mmx1mm
D917: ROW5; LED_Dialight_597_xxxx_407F_SMT_RA_3mmx2mmx1mm
D918: ROW6; LED_Dialight_597_xxxx_407F_SMT_RA_3mmx2mmx1mm
D919: ROW7; LED_Dialight_597_xxxx_407F_SMT_RA_3mmx2mmx1mm
D920: Z5; LED_0805_2012Metric_Pad1.15x1.40mm_HandSolder
D921: Z4; LED_0805_2012Metric_Pad1.15x1.40mm_HandSolder
D922: Z3; LED_0805_2012Metric_Pad1.15x1.40mm_HandSolder
D923: Z2; LED_0805_2012Metric_Pad1.15x1.40mm_HandSolder
D924: Z9; LED_0805_2012Metric_Pad1.15x1.40mm_HandSolder
D925: Z8; LED_0805_2012Metric_Pad1.15x1.40mm_HandSolder
D926: Z7; LED_0805_2012Metric_Pad1.15x1.40mm_HandSolder
D927: Z6; LED_0805_2012Metric_Pad1.15x1.40mm_HandSolder
D928: Z14; LED_0805_2012Metric_Pad1.15x1.40mm_HandSolder
D929: Z13; LED_0805_2012Metric_Pad1.15x1.40mm_HandSolder
D930: Z12; LED_0805_2012Metric_Pad1.15x1.40mm_HandSolder
D931: Z11; LED_0805_2012Metric_Pad1.15x1.40mm_HandSolder
D932: Z18; LED_0805_2012Metric_Pad1.15x1.40mm_HandSolder
D933: Z17; LED_0805_2012Metric_Pad1.15x1.40mm_HandSolder
D934: Z16; LED_0805_2012Metric_Pad1.15x1.40mm_HandSolder
D935: Z15; LED_0805_2012Metric_Pad1.15x1.40mm_HandSolder
D936: Z23; LED_0805_2012Metric_Pad1.15x1.40mm_HandSolder
D937: Z22; LED_0805_2012Metric_Pad1.15x1.40mm_HandSolder
D938: Z21; LED_0805_2012Metric_Pad1.15x1.40mm_HandSolder
D939: Z20; LED_0805_2012Metric_Pad1.15x1.40mm_HandSolder
D940: Z27; LED_0805_2012Metric_Pad1.15x1.40mm_HandSolder
D941: Z26; LED_0805_2012Metric_Pad1.15x1.40mm_HandSolder
D942: Z25; LED_0805_2012Metric_Pad1.15x1.40mm_HandSolder
D943: Z24; LED_0805_2012Metric_Pad1.15x1.40mm_HandSolder
D944: Z32; LED_0805_2012Metric_Pad1.15x1.40mm_HandSolder
D945: Z31; LED_0805_2012Metric_Pad1.15x1.40mm_HandSolder
D946: Z30; LED_0805_2012Metric_Pad1.15x1.40mm_HandSolder
D947: Z29; LED_0805_2012Metric_Pad1.15x1.40mm_HandSolder
D948: Z36; LED_0805_2012Metric_Pad1.15x1.40mm_HandSolder
D949: Z35; LED_0805_2012Metric_Pad1.15x1.40mm_HandSolder
D950: Z34; LED_0805_2012Metric_Pad1.15x1.40mm_HandSolder
D951: Z33; LED_0805_2012Metric_Pad1.15x1.40mm_HandSolder
R901, R902, R903, R904, R905, R906, R907, R908, R909, R910, R911, R912, R913, R914, R915, R916, R917, R918, R919, R920, R921, R922, R923: 470R; R_0805_2012Metric_Pad1.20x1.40mm_HandSolder
U904, U905, U906: 74HCT245; TSSOP-20_4.4x6.5mm_P0.65mm

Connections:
+5V: D910.2 (A), D911.2 (A), U904.1 (A->B), U904.20 (VCC), U905.1 (A->B), U905.20 (VCC), U906.1 (A->B), U906.20 (VCC); also elsewhere on the board
COL0: U904.9 (A7); also elsewhere on the board
COL1: U904.8 (A6); also elsewhere on the board
COL2: U904.7 (A5); also elsewhere on the board
COL3: U904.6 (A4); also elsewhere on the board
GND: D901.1 (K), D902.1 (K), D903.1 (K), D904.1 (K), D905.1 (K), D906.1 (K), D907.1 (K), D908.1 (K), D909.1 (K), D912.1 (K), D913.1 (K), D914.1 (K), D915.1 (K), D916.1 (K), D917.1 (K), D918.1 (K), D919.1 (K), U904.10 (GND), U904.19 (CE), U905.10 (GND), U906.9 (A7), U906.10 (GND), U906.19 (CE); also elsewhere on the board
INPUT: U906.5 (A3); also elsewhere on the board
unnamed: D901.2 (A), R901.1
unnamed: D902.2 (A), R902.1
unnamed: D903.2 (A), R903.1
unnamed: D904.2 (A), R904.1
unnamed: D905.2 (A), R905.1
unnamed: D906.2 (A), R906.1
unnamed: D907.2 (A), R907.1
unnamed: D908.2 (A), R908.1
unnamed: D909.2 (A), R909.1
unnamed: D910.1 (K), R910.1
unnamed: D911.1 (K), R911.1
unnamed: D912.2 (A), R912.1
unnamed: D913.2 (A), R913.1
unnamed: D914.2 (A), R914.1
unnamed: D915.2 (A), R915.1
unnamed: D916.2 (A), R916.1
unnamed: D917.2 (A), R917.1
unnamed: D918.2 (A), R918.1
unnamed: D919.2 (A), R919.1
unnamed: R901.2, U904.11 (B7)
unnamed: R902.2, U904.12 (B6)
unnamed: R903.2, U904.13 (B5)
unnamed: R904.2, U904.14 (B4)
unnamed: R905.2, U906.18 (B0)
unnamed: R906.2, U906.17 (B1)
unnamed: R907.2, U906.15 (B3)
unnamed: R908.2, U906.14 (B4)
unnamed: R909.2, U906.13 (B5)
unnamed: R910.2, U906.16 (B2)
unnamed: R911.2, U906.12 (B6)
unnamed: R920.2, U904.18 (B0)
unnamed: R921.2, U904.17 (B1)
unnamed: R922.2, U904.16 (B2)
unnamed: R923.2, U904.15 (B3)
PHI1: U906.2 (A0); also elsewhere on the board
PHI2: U906.3 (A1); also elsewhere on the board
R0: D920.2 (A), D921.2 (A), D922.2 (A), D923.2 (A), R912.2, U905.11 (B7)
R1: D924.2 (A), D925.2 (A), D926.2 (A), D927.2 (A), R913.2, U905.12 (B6)
R2: D928.2 (A), D929.2 (A), D930.2 (A), D931.2 (A), R914.2, U905.13 (B5)
R3: D932.2 (A), D933.2 (A), D934.2 (A), D935.2 (A), R915.2, U905.14 (B4)
R4: D936.2 (A), D937.2 (A), D938.2 (A), D939.2 (A), R916.2, U905.15 (B3)
R5: D940.2 (A), D941.2 (A), D942.2 (A), D943.2 (A), R917.2, U905.16 (B2)
R6: D944.2 (A), D945.2 (A), D946.2 (A), D947.2 (A), R918.2, U905.17 (B1)
R7: D948.2 (A), D949.2 (A), D950.2 (A), D951.2 (A), R919.2, U905.18 (B0)
READ: U906.7 (A5); also elsewhere on the board
ROW0: U905.9 (A7); also elsewhere on the board
ROW1: U905.8 (A6); also elsewhere on the board
ROW2: U905.7 (A5); also elsewhere on the board
ROW3: U905.6 (A4); also elsewhere on the board
ROW4: U905.5 (A3); also elsewhere on the board
ROW5: U905.4 (A2); also elsewhere on the board
ROW6: U905.3 (A1); also elsewhere on the board
ROW7: U905.2 (A0); also elsewhere on the board
WRITE_~RECIRCULATE: U906.6 (A4); also elsewhere on the board
~C0: D920.1 (K), D924.1 (K), D928.1 (K), D932.1 (K), D936.1 (K), D940.1 (K), D944.1 (K), D948.1 (K), R923.1
~C1: D921.1 (K), D925.1 (K), D929.1 (K), D933.1 (K), D937.1 (K), D941.1 (K), D945.1 (K), D949.1 (K), R922.1
~C2: D922.1 (K), D926.1 (K), D930.1 (K), D934.1 (K), D938.1 (K), D942.1 (K), D946.1 (K), D950.1 (K), R921.1
~C3: D923.1 (K), D927.1 (K), D931.1 (K), D935.1 (K), D939.1 (K), D943.1 (K), D947.1 (K), D951.1 (K), R920.1
~COL0: U904.5 (A3); also elsewhere on the board
~COL1: U904.4 (A2); also elsewhere on the board
~COL2: U904.3 (A1); also elsewhere on the board
~COL3: U904.2 (A0); also elsewhere on the board
~OUTPUT: U906.4 (A2); also elsewhere on the board
~PAGE_SELECT: U905.19 (CE), U906.8 (A6); also elsewhere on the board

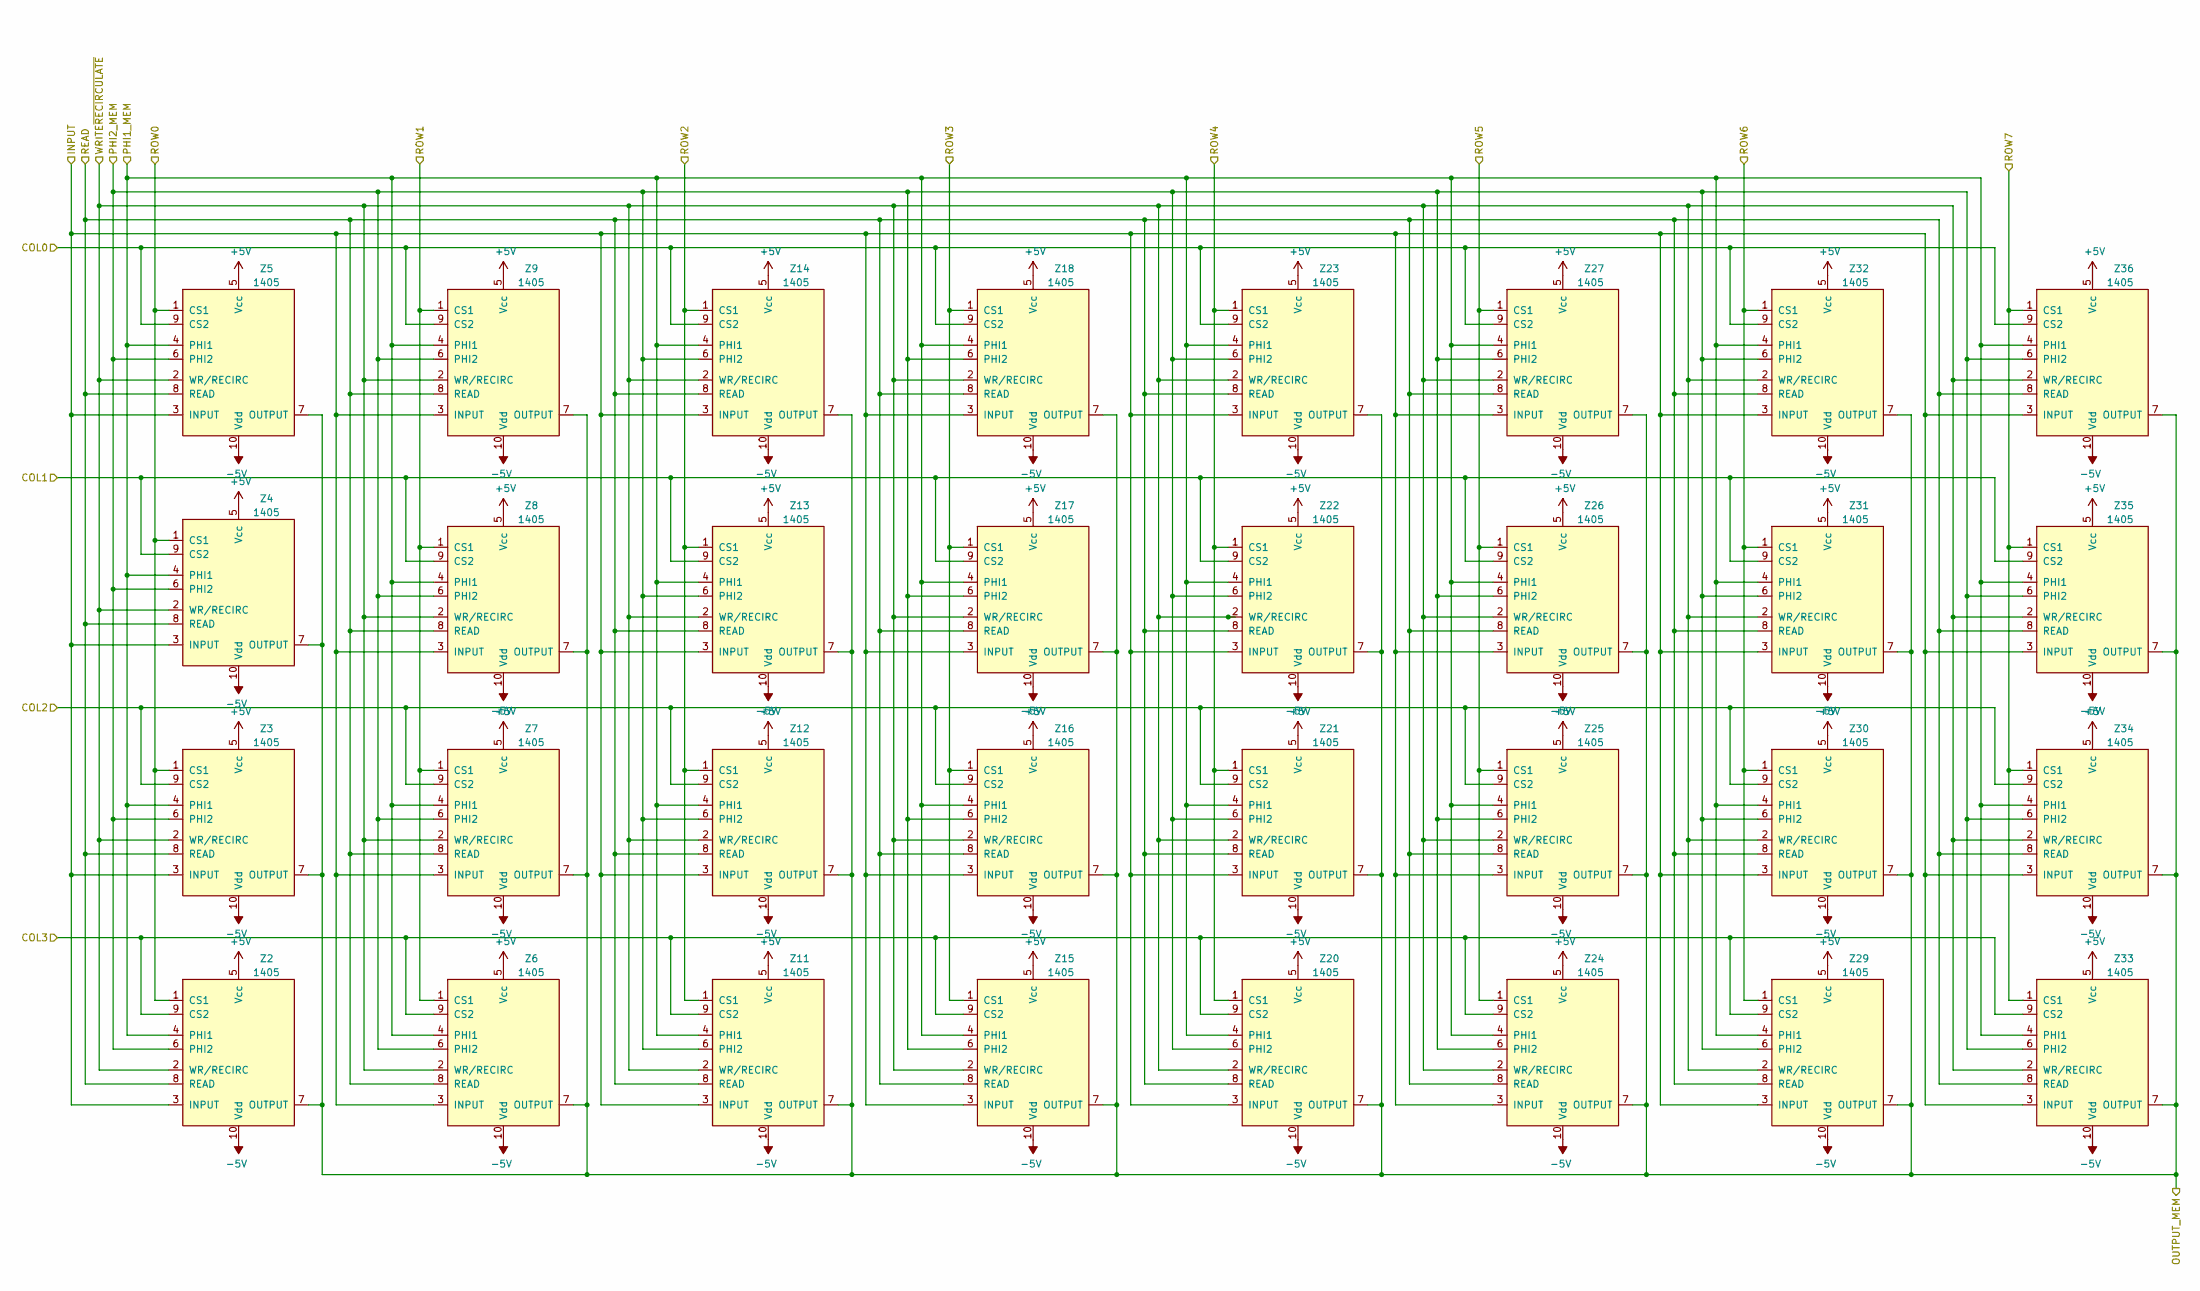
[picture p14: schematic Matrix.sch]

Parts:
Z2, Z3, Z4, Z5, Z6, Z7, Z8, Z9, Z11, Z12, Z13, Z14, Z15, Z16, Z17, Z18, Z20, Z21, Z22, Z23, Z24, Z25, Z26, Z27, Z29, Z30, Z31, Z32, Z33, Z34, Z35, Z36: 1405; TO-99-10

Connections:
+5V: Z2.5 (Vcc), Z3.5 (Vcc), Z4.5 (Vcc), Z5.5 (Vcc), Z6.5 (Vcc), Z7.5 (Vcc), Z8.5 (Vcc), Z9.5 (Vcc), Z11.5 (Vcc), Z12.5 (Vcc), Z13.5 (Vcc), Z14.5 (Vcc), Z15.5 (Vcc), Z16.5 (Vcc), Z17.5 (Vcc), Z18.5 (Vcc), Z20.5 (Vcc), Z21.5 (Vcc), Z22.5 (Vcc), Z23.5 (Vcc), Z24.5 (Vcc), Z25.5 (Vcc), Z26.5 (Vcc), Z27.5 (Vcc), Z29.5 (Vcc), Z30.5 (Vcc), Z31.5 (Vcc), Z32.5 (Vcc), Z33.5 (Vcc), Z34.5 (Vcc), Z35.5 (Vcc), Z36.5 (Vcc); also elsewhere on the board
-5V: Z2.10 (Vdd), Z3.10 (Vdd), Z4.10 (Vdd), Z5.10 (Vdd), Z6.10 (Vdd), Z7.10 (Vdd), Z8.10 (Vdd), Z9.10 (Vdd), Z11.10 (Vdd), Z12.10 (Vdd), Z13.10 (Vdd), Z14.10 (Vdd), Z15.10 (Vdd), Z16.10 (Vdd), Z17.10 (Vdd), Z18.10 (Vdd), Z20.10 (Vdd), Z21.10 (Vdd), Z22.10 (Vdd), Z23.10 (Vdd), Z24.10 (Vdd), Z25.10 (Vdd), Z26.10 (Vdd), Z27.10 (Vdd), Z29.10 (Vdd), Z30.10 (Vdd), Z31.10 (Vdd), Z32.10 (Vdd), Z33.10 (Vdd), Z34.10 (Vdd), Z35.10 (Vdd), Z36.10 (Vdd); also elsewhere on the board
COL0: Z5.9 (CS2), Z9.9 (CS2), Z14.9 (CS2), Z18.9 (CS2), Z23.9 (CS2), Z27.9 (CS2), Z32.9 (CS2), Z36.9 (CS2); also elsewhere on the board
COL1: Z4.9 (CS2), Z8.9 (CS2), Z13.9 (CS2), Z17.9 (CS2), Z22.9 (CS2), Z26.9 (CS2), Z31.9 (CS2), Z35.9 (CS2); also elsewhere on the board
COL2: Z3.9 (CS2), Z7.9 (CS2), Z12.9 (CS2), Z16.9 (CS2), Z21.9 (CS2), Z25.9 (CS2), Z30.9 (CS2), Z34.9 (CS2); also elsewhere on the board
COL3: Z2.9 (CS2), Z6.9 (CS2), Z11.9 (CS2), Z15.9 (CS2), Z20.9 (CS2), Z24.9 (CS2), Z29.9 (CS2), Z33.9 (CS2); also elsewhere on the board
INPUT: Z2.3 (INPUT), Z3.3 (INPUT), Z4.3 (INPUT), Z5.3 (INPUT), Z6.3 (INPUT), Z7.3 (INPUT), Z8.3 (INPUT), Z9.3 (INPUT), Z11.3 (INPUT), Z12.3 (INPUT), Z13.3 (INPUT), Z14.3 (INPUT), Z15.3 (INPUT), Z16.3 (INPUT), Z17.3 (INPUT), Z18.3 (INPUT), Z20.3 (INPUT), Z21.3 (INPUT), Z22.3 (INPUT), Z23.3 (INPUT), Z24.3 (INPUT), Z25.3 (INPUT), Z26.3 (INPUT), Z27.3 (INPUT), Z29.3 (INPUT), Z30.3 (INPUT), Z31.3 (INPUT), Z32.3 (INPUT), Z33.3 (INPUT), Z34.3 (INPUT), Z35.3 (INPUT), Z36.3 (INPUT); also elsewhere on the board
OUTPUT_MEM: Z2.7 (OUTPUT), Z3.7 (OUTPUT), Z4.7 (OUTPUT), Z5.7 (OUTPUT), Z6.7 (OUTPUT), Z7.7 (OUTPUT), Z8.7 (OUTPUT), Z9.7 (OUTPUT), Z11.7 (OUTPUT), Z12.7 (OUTPUT), Z13.7 (OUTPUT), Z14.7 (OUTPUT), Z15.7 (OUTPUT), Z16.7 (OUTPUT), Z17.7 (OUTPUT), Z18.7 (OUTPUT), Z20.7 (OUTPUT), Z21.7 (OUTPUT), Z22.7 (OUTPUT), Z23.7 (OUTPUT), Z24.7 (OUTPUT), Z25.7 (OUTPUT), Z26.7 (OUTPUT), Z27.7 (OUTPUT), Z29.7 (OUTPUT), Z30.7 (OUTPUT), Z31.7 (OUTPUT), Z32.7 (OUTPUT), Z33.7 (OUTPUT), Z34.7 (OUTPUT), Z35.7 (OUTPUT), Z36.7 (OUTPUT); also elsewhere on the board
PHI1_MEM: Z2.4 (PHI1), Z3.4 (PHI1), Z4.4 (PHI1), Z5.4 (PHI1), Z6.4 (PHI1), Z7.4 (PHI1), Z8.4 (PHI1), Z9.4 (PHI1), Z11.4 (PHI1), Z12.4 (PHI1), Z13.4 (PHI1), Z14.4 (PHI1), Z15.4 (PHI1), Z16.4 (PHI1), Z17.4 (PHI1), Z18.4 (PHI1), Z20.4 (PHI1), Z21.4 (PHI1), Z22.4 (PHI1), Z23.4 (PHI1), Z24.4 (PHI1), Z25.4 (PHI1), Z26.4 (PHI1), Z27.4 (PHI1), Z29.4 (PHI1), Z30.4 (PHI1), Z31.4 (PHI1), Z32.4 (PHI1), Z33.4 (PHI1), Z34.4 (PHI1), Z35.4 (PHI1), Z36.4 (PHI1); also elsewhere on the board
PHI2_MEM: Z2.6 (PHI2), Z3.6 (PHI2), Z4.6 (PHI2), Z5.6 (PHI2), Z6.6 (PHI2), Z7.6 (PHI2), Z8.6 (PHI2), Z9.6 (PHI2), Z11.6 (PHI2), Z12.6 (PHI2), Z13.6 (PHI2), Z14.6 (PHI2), Z15.6 (PHI2), Z16.6 (PHI2), Z17.6 (PHI2), Z18.6 (PHI2), Z20.6 (PHI2), Z21.6 (PHI2), Z22.6 (PHI2), Z23.6 (PHI2), Z24.6 (PHI2), Z25.6 (PHI2), Z26.6 (PHI2), Z27.6 (PHI2), Z29.6 (PHI2), Z30.6 (PHI2), Z31.6 (PHI2), Z32.6 (PHI2), Z33.6 (PHI2), Z34.6 (PHI2), Z35.6 (PHI2), Z36.6 (PHI2); also elsewhere on the board
READ: Z2.8 (READ), Z3.8 (READ), Z4.8 (READ), Z5.8 (READ), Z6.8 (READ), Z7.8 (READ), Z8.8 (READ), Z9.8 (READ), Z11.8 (READ), Z12.8 (READ), Z13.8 (READ), Z14.8 (READ), Z15.8 (READ), Z16.8 (READ), Z17.8 (READ), Z18.8 (READ), Z20.8 (READ), Z21.8 (READ), Z22.8 (READ), Z23.8 (READ), Z24.8 (READ), Z25.8 (READ), Z26.8 (READ), Z27.8 (READ), Z29.8 (READ), Z30.8 (READ), Z31.8 (READ), Z32.8 (READ), Z33.8 (READ), Z34.8 (READ), Z35.8 (READ), Z36.8 (READ); also elsewhere on the board
ROW0: Z2.1 (CS1), Z3.1 (CS1), Z4.1 (CS1), Z5.1 (CS1); also elsewhere on the board
ROW1: Z6.1 (CS1), Z7.1 (CS1), Z8.1 (CS1), Z9.1 (CS1); also elsewhere on the board
ROW2: Z11.1 (CS1), Z12.1 (CS1), Z13.1 (CS1), Z14.1 (CS1); also elsewhere on the board
ROW3: Z15.1 (CS1), Z16.1 (CS1), Z17.1 (CS1), Z18.1 (CS1); also elsewhere on the board
ROW4: Z20.1 (CS1), Z21.1 (CS1), Z22.1 (CS1), Z23.1 (CS1); also elsewhere on the board
ROW5: Z24.1 (CS1), Z25.1 (CS1), Z26.1 (CS1), Z27.1 (CS1); also elsewhere on the board
ROW6: Z29.1 (CS1), Z30.1 (CS1), Z31.1 (CS1), Z32.1 (CS1); also elsewhere on the board
ROW7: Z33.1 (CS1), Z34.1 (CS1), Z35.1 (CS1), Z36.1 (CS1); also elsewhere on the board
WRITE_~RECIRCULATE: Z2.2 (WR/RECIRC), Z3.2 (WR/RECIRC), Z4.2 (WR/RECIRC), Z5.2 (WR/RECIRC), Z6.2 (WR/RECIRC), Z7.2 (WR/RECIRC), Z8.2 (WR/RECIRC), Z9.2 (WR/RECIRC), Z11.2 (WR/RECIRC), Z12.2 (WR/RECIRC), Z13.2 (WR/RECIRC), Z14.2 (WR/RECIRC), Z15.2 (WR/RECIRC), Z16.2 (WR/RECIRC), Z17.2 (WR/RECIRC), Z18.2 (WR/RECIRC), Z20.2 (WR/RECIRC), Z21.2 (WR/RECIRC), Z22.2 (WR/RECIRC), Z23.2 (WR/RECIRC), Z24.2 (WR/RECIRC), Z25.2 (WR/RECIRC), Z26.2 (WR/RECIRC), Z27.2 (WR/RECIRC), Z29.2 (WR/RECIRC), Z30.2 (WR/RECIRC), Z31.2 (WR/RECIRC), Z32.2 (WR/RECIRC), Z33.2 (WR/RECIRC), Z34.2 (WR/RECIRC), Z35.2 (WR/RECIRC), Z36.2 (WR/RECIRC); also elsewhere on the board

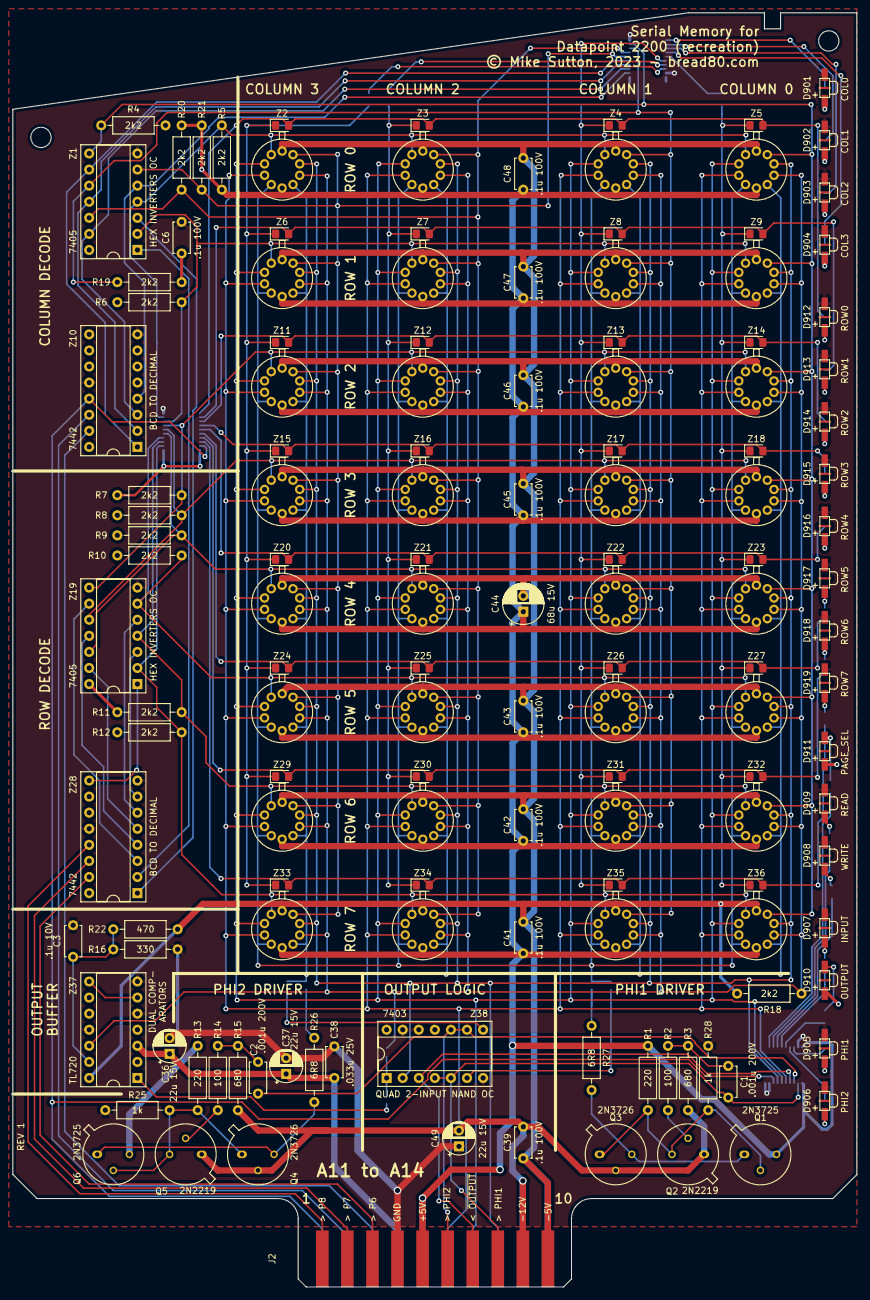
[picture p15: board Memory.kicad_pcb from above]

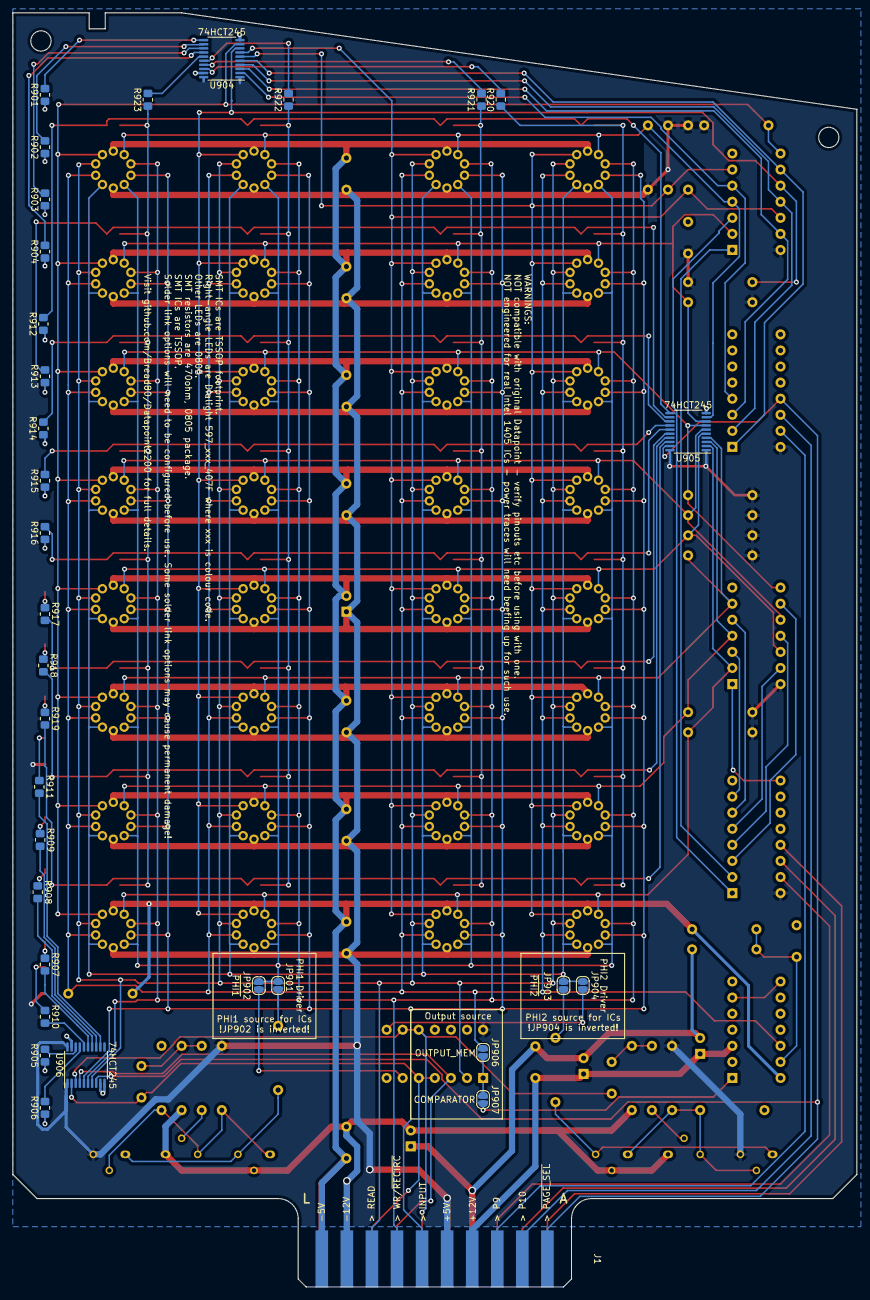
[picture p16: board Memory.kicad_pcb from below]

Board: 2 copper layers, 133.3 x 201.3 mm, 173 parts (33 on the bottom side), 106 nets.

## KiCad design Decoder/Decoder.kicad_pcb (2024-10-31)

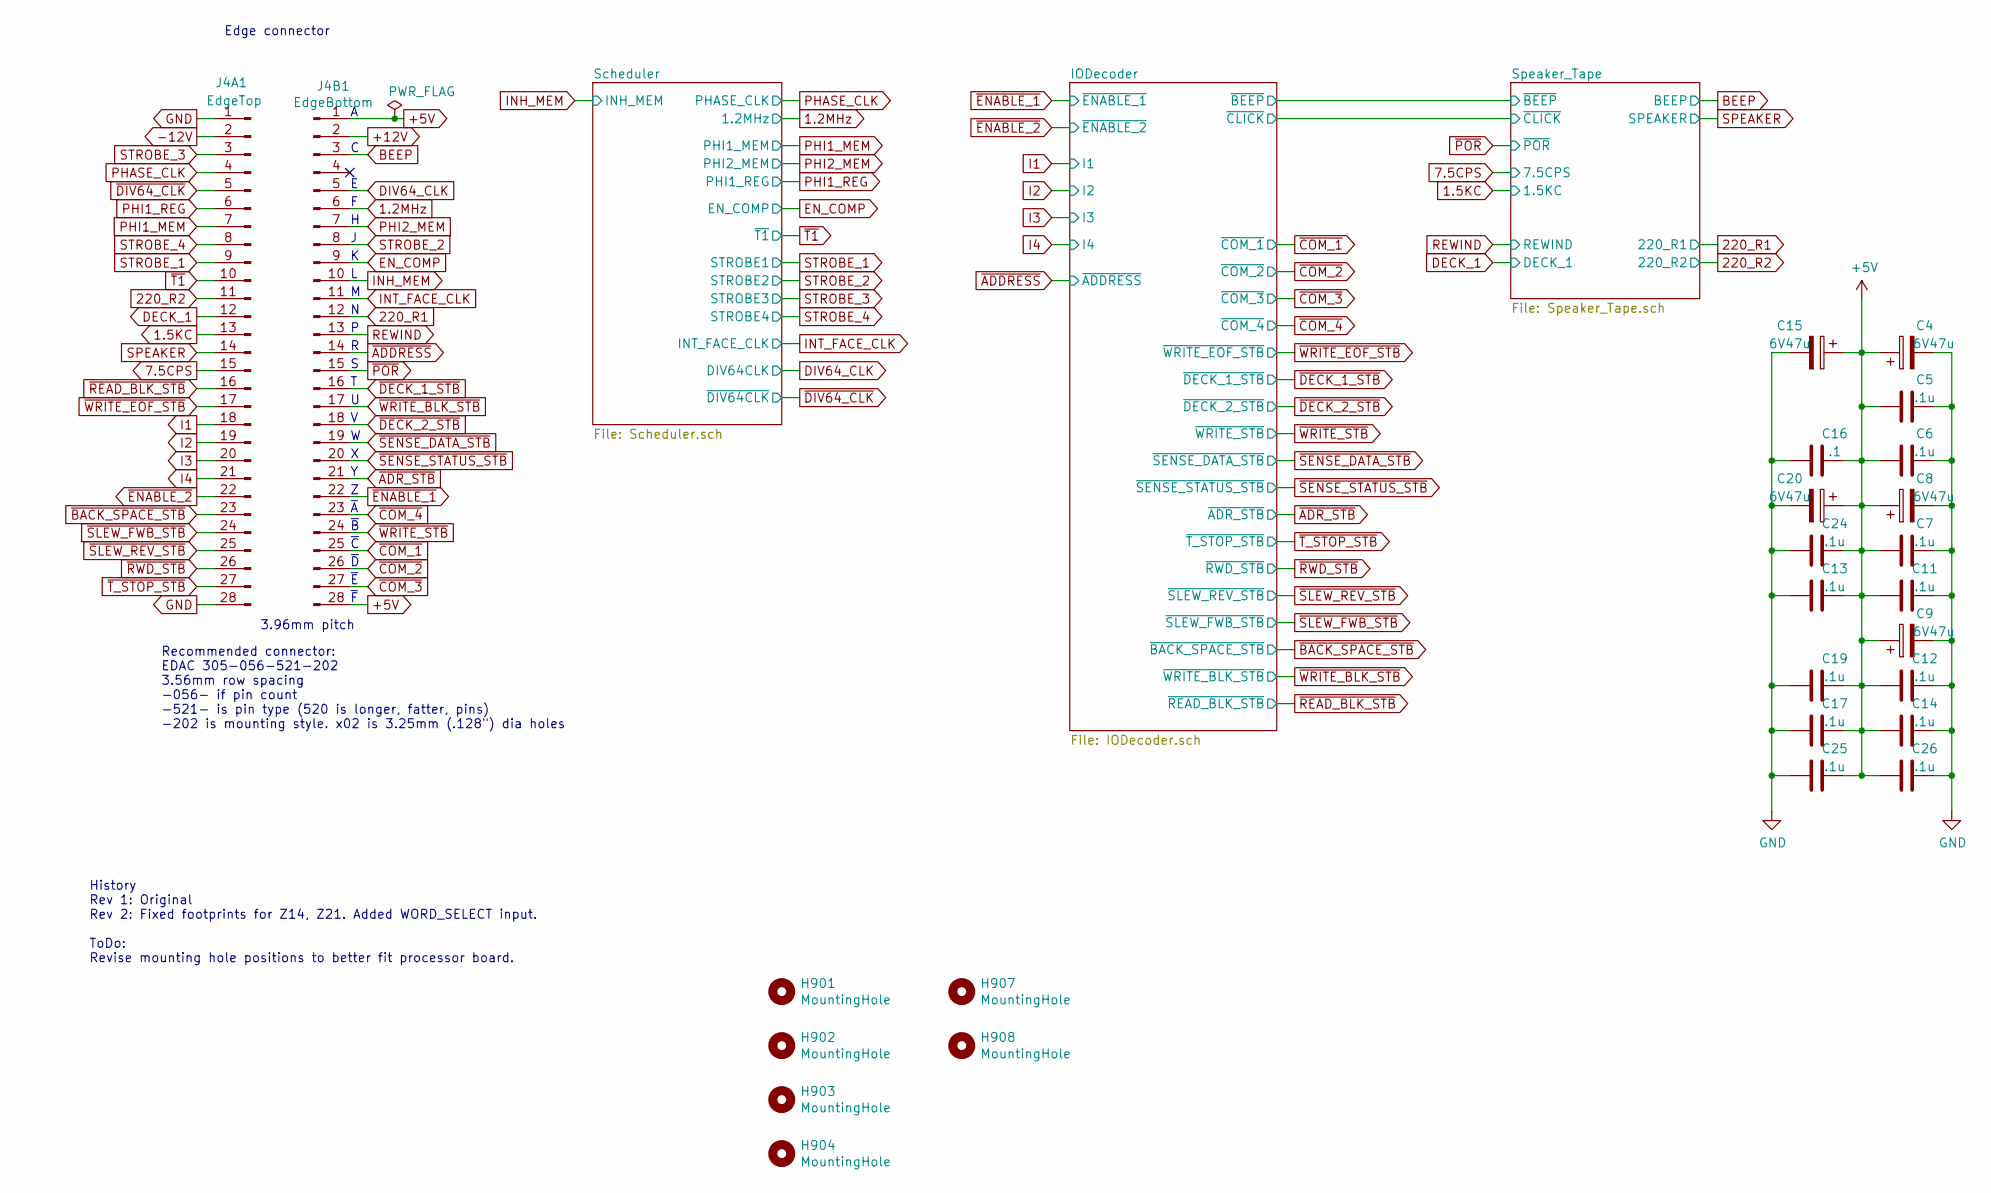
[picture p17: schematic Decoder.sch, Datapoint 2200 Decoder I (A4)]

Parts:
C4, C8, C9, C15, C20: 6V47u; CP_Radial_D6.3mm_P2.50mm
C5, C6, C7, C11, C12, C13, C14, C17, C19, C24, C25, C26: .1u; C_Disc_D7.0mm_W2.5mm_P5.00mm
C16: .1; C_Disc_D7.0mm_W2.5mm_P5.00mm
H901, H902, H903, H904, H907, H908: MountingHole; MountingHole_3.2mm_M3
J4A1: EdgeTop; EdgeConn_28_Pin_Pitch_3.96mm
J4B1: EdgeBottom; EdgeConn_28_Pin_Pitch_3.96mm

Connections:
1.2MHz: J4B1.6; also elsewhere on the board
1.5KC: J4A1.13; also elsewhere on the board
7.5CPS: J4A1.15; also elsewhere on the board
220_R1: J4B1.12; also elsewhere on the board
220_R2: J4A1.11; also elsewhere on the board
+5V: C4.1, C5.2, C6.2, C7.2, C8.1, C9.1, C11.2, C12.2, C13.1, C14.2, C15.1, C16.1, C17.1, C19.1, C20.1, C24.1, C25.1, C26.2, J4B1.1, J4B1.28; also elsewhere on the board
+12V: J4B1.2
-12V: J4A1.2
BEEP: J4B1.3; also elsewhere on the board
DECK_1: J4A1.12; also elsewhere on the board
DIV64_CLK: J4B1.5; also elsewhere on the board
EN_COMP: J4B1.9; also elsewhere on the board
GND: C4.2, C5.1, C6.1, C7.1, C8.2, C9.2, C11.1, C12.1, C13.2, C14.1, C15.2, C16.2, C17.2, C19.2, C20.2, C24.2, C25.2, C26.1, J4A1.1, J4A1.28; also elsewhere on the board
I1: J4A1.18; also elsewhere on the board
I2: J4A1.19; also elsewhere on the board
I3: J4A1.20; also elsewhere on the board
I4: J4A1.21; also elsewhere on the board
INH_MEM: J4B1.10; also elsewhere on the board
INT_FACE_CLK: J4B1.11; also elsewhere on the board
PHASE_CLK: J4A1.4; also elsewhere on the board
PHI1_MEM: J4A1.7; also elsewhere on the board
PHI1_REG: J4A1.6; also elsewhere on the board
PHI2_MEM: J4B1.7; also elsewhere on the board
REWIND: J4B1.13; also elsewhere on the board
SPEAKER: J4A1.14; also elsewhere on the board
STROBE_1: J4A1.9; also elsewhere on the board
STROBE_2: J4B1.8; also elsewhere on the board
STROBE_3: J4A1.3; also elsewhere on the board
STROBE_4: J4A1.8; also elsewhere on the board
~ADDRESS: J4B1.14; also elsewhere on the board
~ADR_STB: J4B1.21; also elsewhere on the board
~BACK_SPACE_STB: J4A1.23; also elsewhere on the board
~COM_1: J4B1.25; also elsewhere on the board
~COM_2: J4B1.26; also elsewhere on the board
~COM_3: J4B1.27; also elsewhere on the board
~COM_4: J4B1.23; also elsewhere on the board
~DECK_1_STB: J4B1.16; also elsewhere on the board
~DECK_2_STB: J4B1.18; also elsewhere on the board
~DIV64_CLK: J4A1.5; also elsewhere on the board
~ENABLE_1: J4B1.22; also elsewhere on the board
~ENABLE_2: J4A1.22; also elsewhere on the board
~POR: J4B1.15; also elsewhere on the board
~READ_BLK_STB: J4A1.16; also elsewhere on the board
~RWD_STB: J4A1.26; also elsewhere on the board
~SENSE_DATA_STB: J4B1.19; also elsewhere on the board
~SENSE_STATUS_STB: J4B1.20; also elsewhere on the board
~SLEW_FWB_STB: J4A1.24; also elsewhere on the board
~SLEW_REV_STB: J4A1.25; also elsewhere on the board
~T1: J4A1.10; also elsewhere on the board
~T_STOP_STB: J4A1.27; also elsewhere on the board
~WRITE_BLK_STB: J4B1.17; also elsewhere on the board
~WRITE_EOF_STB: J4A1.17; also elsewhere on the board
~WRITE_STB: J4B1.24; also elsewhere on the board

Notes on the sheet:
3.96mm pitch
History Rev 1: Original Rev 2: Fixed footprints for Z14, Z21. Added WORD_SELECT input. ToDo: Revise mounting hole positions to better fit processor board.
Recommended connector: EDAC 305-056-521-202 3.56mm row spacing -056- if pin count -521- is pin type (520 is longer, fatter, pins) -202 is mounting style. x02 is 3.25mm (.128") dia holes
Edge connector

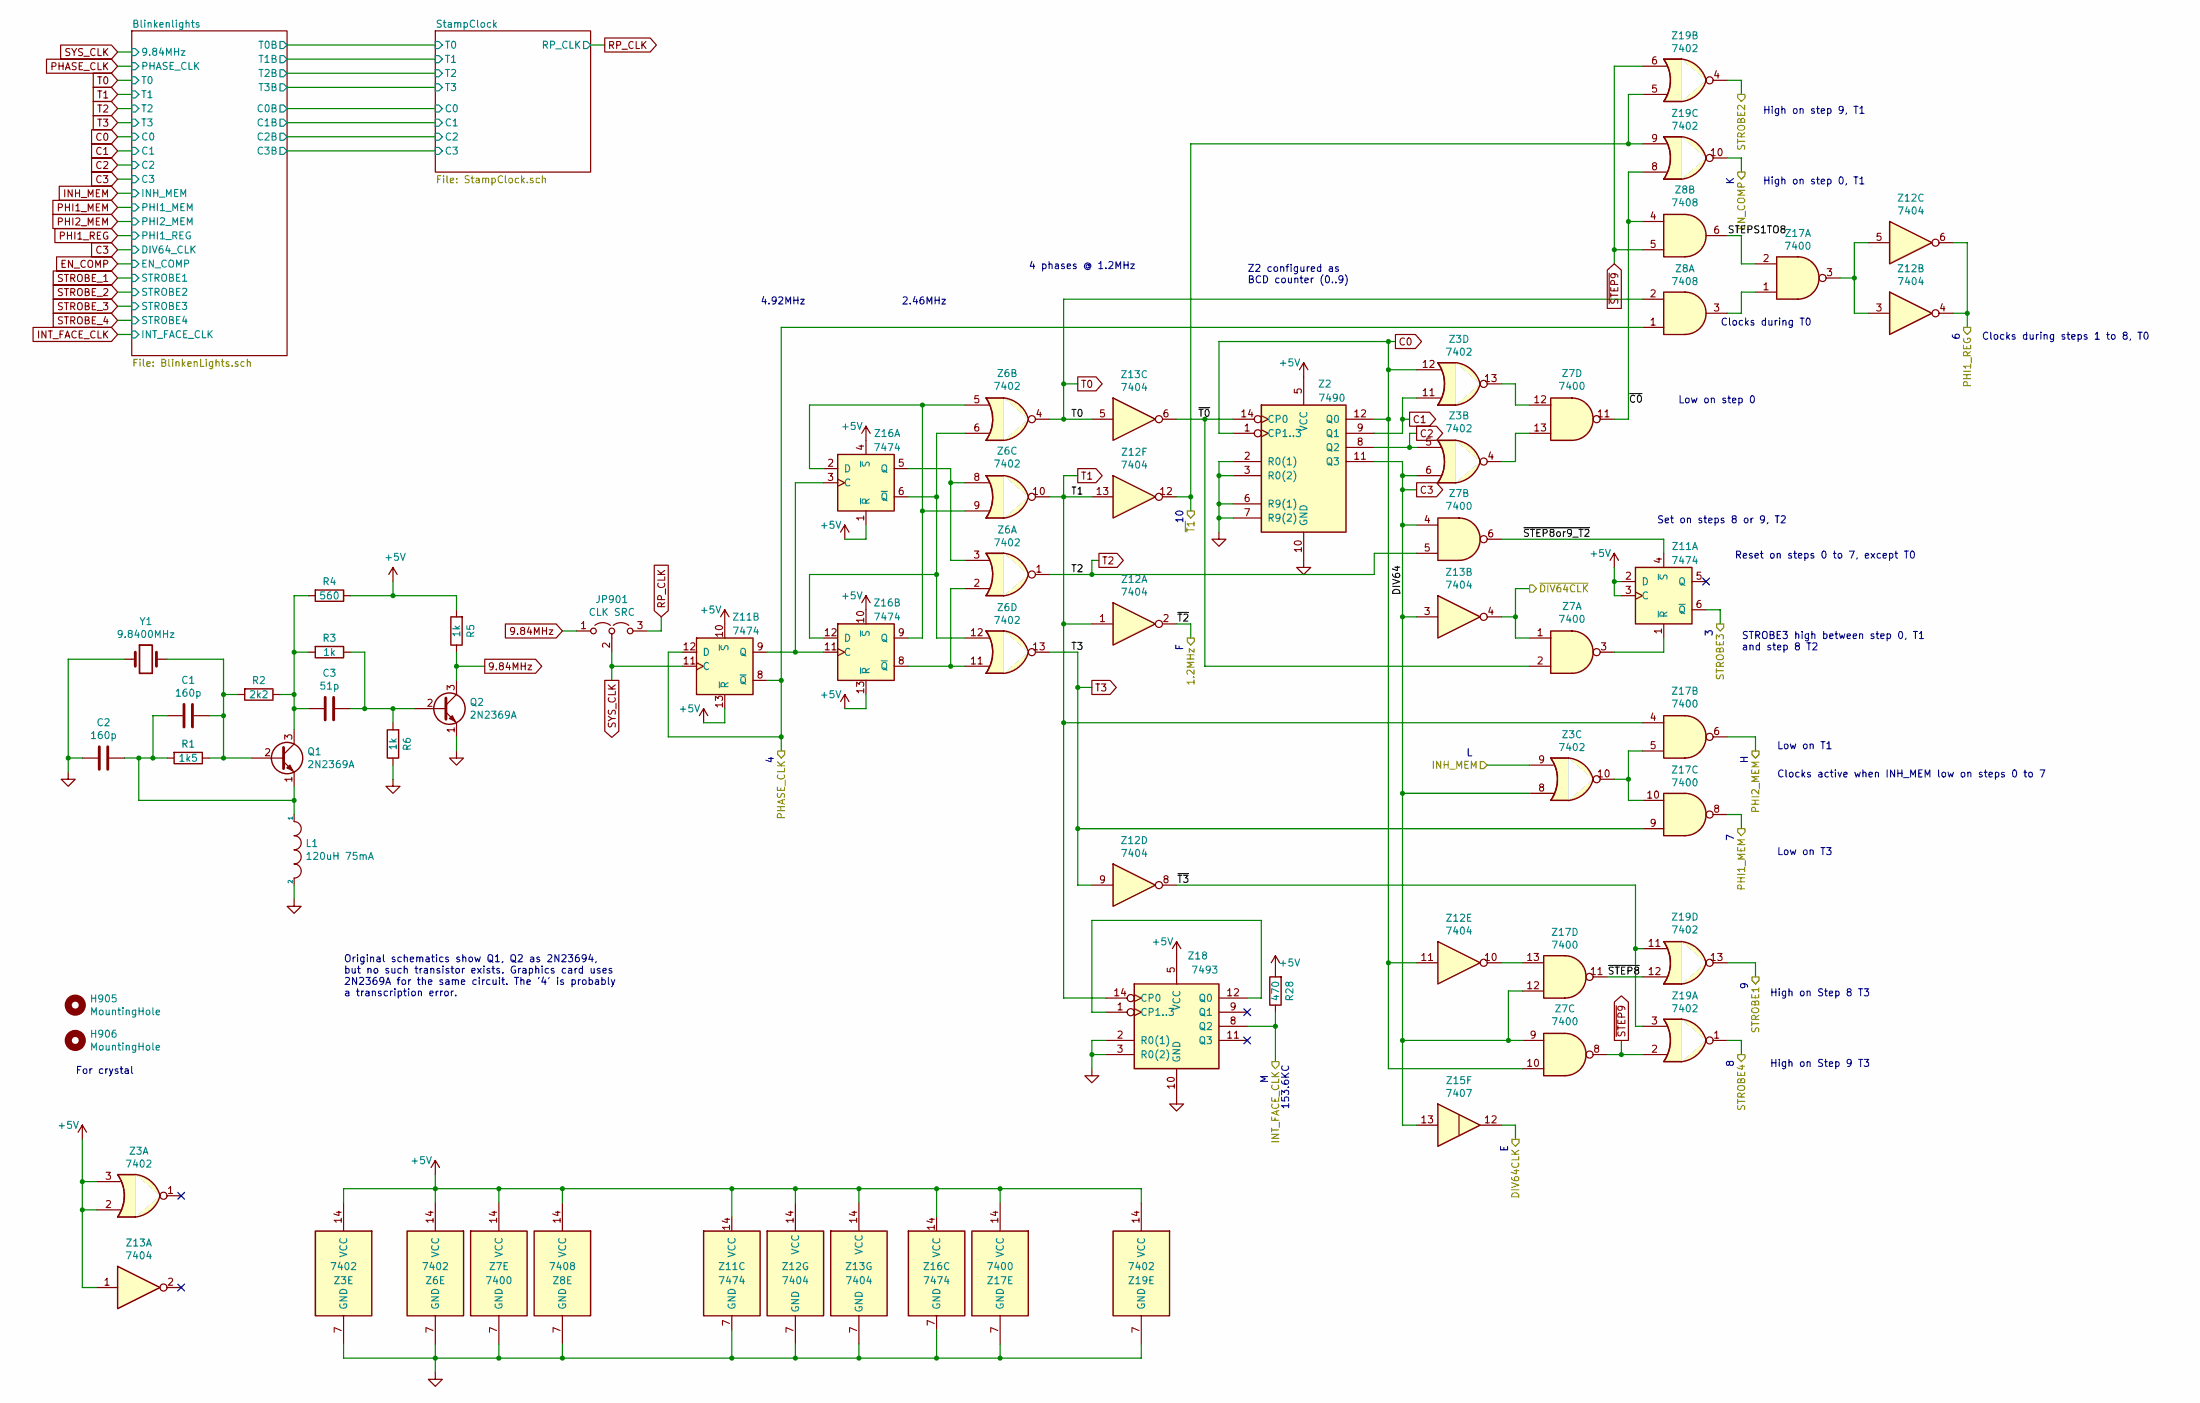
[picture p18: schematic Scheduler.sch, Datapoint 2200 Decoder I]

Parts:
C1, C2: 160p; C_Disc_D7.0mm_W2.5mm_P5.00mm
C3: 51p; C_Disc_D7.0mm_W2.5mm_P5.00mm
H905, H906: MountingHole; MountingHole_3.2mm_M3
JP901: CLK SRC; PinHeader_1x03_P2.54mm_Vertical
L1: 120uH 75mA; L_Axial_L9.5mm_D4.0mm_P12.70mm_Horizontal_Fastron_SMCC
Q1, Q2: 2N2369A; TO-18-3
R1: 1k5; R_Axial_DIN0207_L6.3mm_D2.5mm_P10.16mm_Horizontal
R2: 2k2; R_Axial_DIN0207_L6.3mm_D2.5mm_P10.16mm_Horizontal
R3, R5, R6: 1k; R_Axial_DIN0207_L6.3mm_D2.5mm_P10.16mm_Horizontal
R4: 560; R_Axial_DIN0207_L6.3mm_D2.5mm_P10.16mm_Horizontal
R28: 470; R_Axial_DIN0207_L6.3mm_D2.5mm_P10.16mm_Horizontal
Y1: 9.8400MHz; Crystal_HC49-U_Horizontal
Z2: 7490; DIP-14_W7.62mm_Socket
Z3, Z6, Z19: 7402; DIP-14_W7.62mm_Socket
Z7, Z17: 7400; DIP-14_W7.62mm_Socket
Z8: 7408; DIP-14_W7.62mm_Socket
Z11, Z16: 7474; DIP-14_W7.62mm_Socket
Z12, Z13: 7404; DIP-14_W7.62mm_Socket
Z15: 7407
Z18: 7493; DIP-14_W7.62mm_Socket

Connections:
1.2MHz: Z12.2; also elsewhere on the board
9.84MHz: JP901.1 (A), Q2.3 (C), R5.1
+5V: R4.1, R5.2, R28.2, Z2.5 (VCC), Z3.2, Z3.3, Z3.14 (VCC), Z6.14 (VCC), Z7.14 (VCC), Z8.14 (VCC), Z11.2 (D), Z11.3 (C), Z11.10 (~S), Z11.13 (~R), Z11.14 (VCC), Z12.14 (VCC), Z13.1, Z13.14 (VCC), Z16.1 (~R), Z16.4 (~S), Z16.10 (~S), Z16.13 (~R), Z16.14 (VCC), Z17.14 (VCC), Z18.5 (VCC), Z19.14 (VCC); also elsewhere on the board
/Scheduler/STEPS1TO8: Z8.6, Z17.2
/Scheduler/~C0: Z7.11, Z8.4, Z19.8
/Scheduler/~STEP8: Z17.11, Z19.12
/Scheduler/~STEP8or9_T2: Z7.6, Z11.4 (~S)
/Scheduler/~T0: Z2.14 (CP0), Z7.2, Z13.6
/Scheduler/~T3: Z12.8, Z19.3, Z19.11
C0: Z2.1 (CP1..3), Z2.12 (Q0), Z3.12, Z7.10, Z12.11; also elsewhere on the board
C1: Z2.9 (Q1), Z3.11; also elsewhere on the board
C2: Z2.8 (Q2), Z3.5; also elsewhere on the board
C3: Z2.11 (Q3), Z3.6, Z3.8, Z7.4, Z7.9, Z13.3, Z15.13, Z17.12; also elsewhere on the board
DIV64_CLK: Z15.12; also elsewhere on the board
EN_COMP: Z19.10; also elsewhere on the board
GND: C2.2, L1.2, Q2.1 (E), R6.1, Y1.1, Z2.2 (R0(1)), Z2.3 (R0(2)), Z2.6 (R9(1)), Z2.7 (R9(2)), Z2.10 (GND), Z3.7 (GND), Z6.7 (GND), Z7.7 (GND), Z8.7 (GND), Z11.7 (GND), Z12.7 (GND), Z13.7 (GND), Z16.7 (GND), Z17.7 (GND), Z18.2 (R0(1)), Z18.3 (R0(2)), Z18.10 (GND), Z19.7 (GND); also elsewhere on the board
INH_MEM: Z3.9; also elsewhere on the board
INT_FACE_CLK: R28.1, Z18.8 (Q2); also elsewhere on the board
unnamed: C1.1, Q1.2 (B), R1.1, R2.2, Y1.2
unnamed: C1.2, C2.1, L1.1, Q1.1 (E), R1.2
unnamed: C3.1, Q2.2 (B), R3.1, R6.2
unnamed: C3.2, Q1.3 (C), R2.1, R3.2, R4.2
unnamed: Z3.4, Z7.13
unnamed: Z3.13, Z7.12
unnamed: Z7.3, Z11.1 (~R)
unnamed: Z11.9 (Q), Z16.3 (C), Z16.11 (C)
unnamed: Z12.3, Z12.5, Z17.3
unnamed: Z12.10, Z17.13
unnamed: Z6.5, Z6.9, Z16.2 (D), Z16.9 (Q)
unnamed: Z6.3, Z6.8, Z16.5 (Q)
unnamed: Z6.2, Z6.11, Z16.8 (~Q)
unnamed: Z6.6, Z6.12, Z16.6 (~Q), Z16.12 (D)
unnamed: Z8.3, Z17.1
unnamed: Z3.10, Z17.5, Z17.10
unnamed: Z18.1 (CP1..3), Z18.12 (Q0)
PHASE_CLK: Z8.1, Z11.8 (~Q), Z11.12 (D); also elsewhere on the board
PHI1_MEM: Z17.8; also elsewhere on the board
PHI1_REG: Z12.4, Z12.6; also elsewhere on the board
PHI2_MEM: Z17.6; also elsewhere on the board
RP_CLK: JP901.3 (B); also elsewhere on the board
STROBE_1: Z19.13; also elsewhere on the board
STROBE_2: Z19.4; also elsewhere on the board
STROBE_3: Z11.6 (~Q); also elsewhere on the board
STROBE_4: Z19.1; also elsewhere on the board
SYS_CLK: JP901.2 (C), Z11.11 (C); also elsewhere on the board
T0: Z6.4, Z8.2, Z13.5; also elsewhere on the board
T1: Z6.10, Z12.1, Z12.13, Z17.4, Z18.14 (CP0); also elsewhere on the board
T2: Z6.1, Z7.5; also elsewhere on the board
T3: Z6.13, Z12.9, Z17.9; also elsewhere on the board
~DIV64_CLK: Z7.1, Z13.4; also elsewhere on the board
~STEP9: Z7.8, Z8.5, Z19.2, Z19.6
~T1: Z12.12, Z19.5, Z19.9; also elsewhere on the board

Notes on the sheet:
4.92MHz
153.6KC
2.46MHz
4 phases @ 1.2MHz
Z2 configured as BCD counter (0..9)
Low on step 0
Set on steps 8 or 9, T2
Reset on steps 0 to 7, except T0
STROBE3 high between step 0, T1 and step 8 T2
Clocks active when INH_MEM low on steps 0 to 7
Low on T1
Low on T3
High on Step 8 T3
High on Step 9 T3
High on step 9, T1
High on step 0, T1
Clocks during T0
Clocks during steps 1 to 8, T0
Original schematics show Q1, Q2 as 2N23694, but no such transistor exists. Graphics card uses 2N2369A for the same circuit. The '4' is probably a transcription error.
For crystal

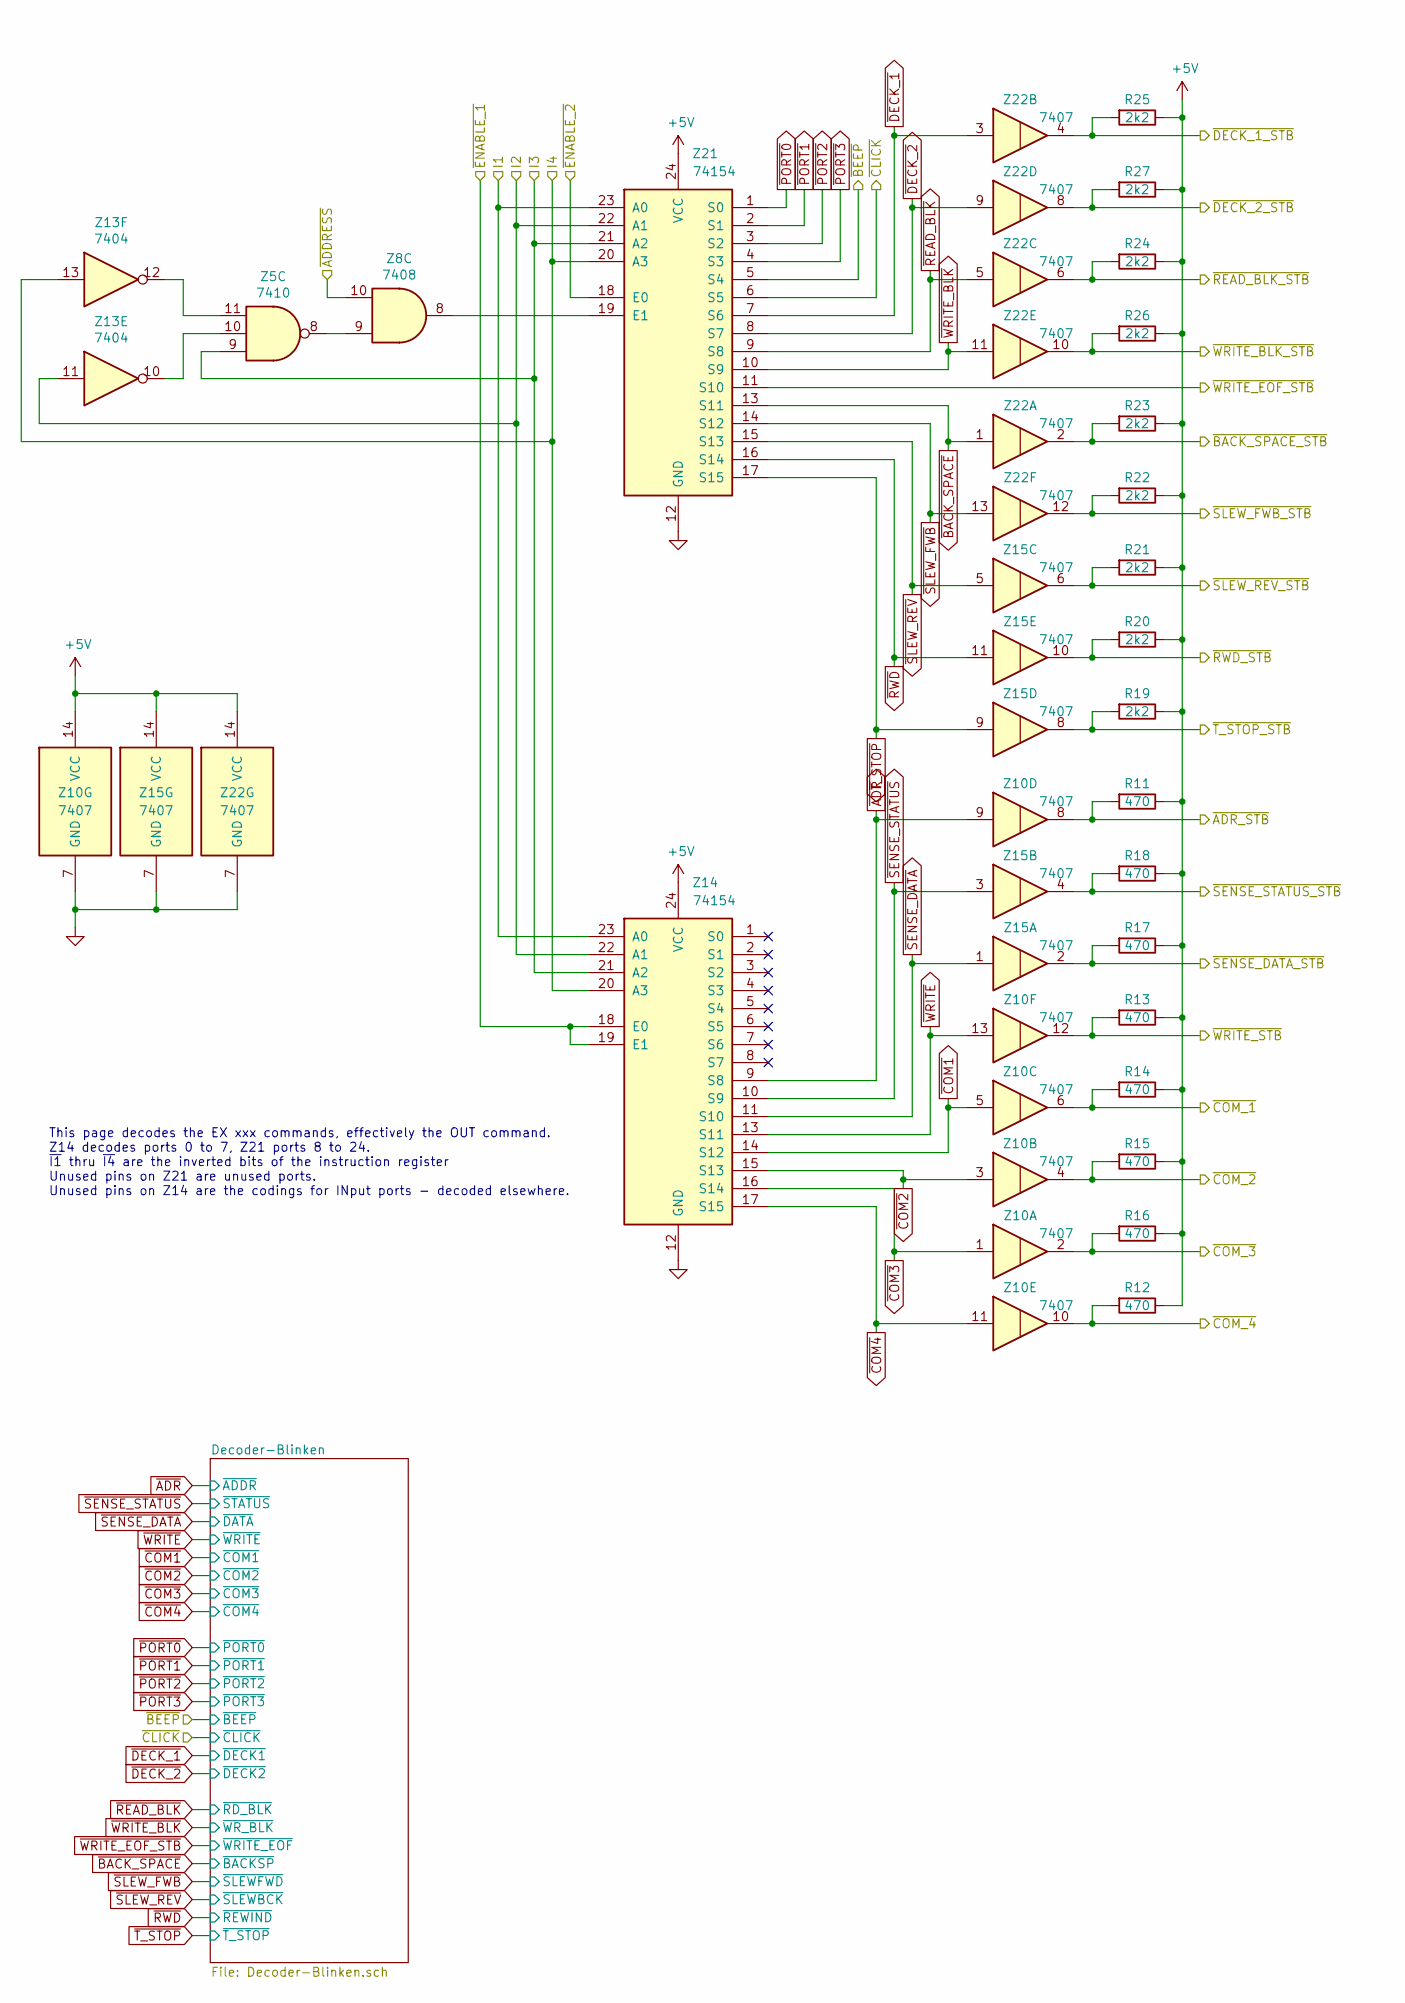
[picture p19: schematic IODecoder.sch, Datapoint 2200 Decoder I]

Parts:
R11, R12, R13, R14, R15, R16, R17, R18: 470; R_Axial_DIN0207_L6.3mm_D2.5mm_P10.16mm_Horizontal
R19, R20, R21, R22, R23, R24, R25, R26, R27: 2k2; R_Axial_DIN0207_L6.3mm_D2.5mm_P10.16mm_Horizontal
Z5: 7410; DIP-14_W7.62mm_Socket
Z8: 7408; DIP-14_W7.62mm_Socket
Z10, Z15, Z22: 7407; DIP-14_W7.62mm_Socket
Z13: 7404; DIP-14_W7.62mm_Socket
Z14, Z21: 74154; DIP-24_W15.24mm_Socket

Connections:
+5V: R11.1, R12.1, R13.1, R14.1, R15.1, R16.1, R17.1, R18.1, R19.1, R20.1, R21.1, R22.1, R23.1, R24.1, R25.1, R26.1, R27.1, Z10.14 (VCC), Z14.24 (VCC), Z15.14 (VCC), Z21.24 (VCC), Z22.14 (VCC); also elsewhere on the board
/IODecoder/~BEEP: Z21.5 (S4); also elsewhere on the board
/IODecoder/~CLICK: Z21.6 (S5); also elsewhere on the board
GND: Z10.7 (GND), Z14.12 (GND), Z15.7 (GND), Z21.12 (GND), Z22.7 (GND); also elsewhere on the board
I1: Z14.23 (A0), Z21.23 (A0); also elsewhere on the board
I2: Z13.11, Z14.22 (A1), Z21.22 (A1); also elsewhere on the board
I3: Z5.9, Z14.21 (A2), Z21.21 (A2); also elsewhere on the board
I4: Z13.13, Z14.20 (A3), Z21.20 (A3); also elsewhere on the board
unnamed: Z5.8, Z8.9
unnamed: Z5.10, Z13.10
unnamed: Z5.11, Z13.12
unnamed: Z8.8, Z21.19 (E1)
~ADDRESS: Z8.10; also elsewhere on the board
~ADR: Z10.9, Z14.9 (S8); also elsewhere on the board
~ADR_STB: R11.2, Z10.8; also elsewhere on the board
~BACK_SPACE: Z21.13 (S11), Z22.1; also elsewhere on the board
~BACK_SPACE_STB: R23.2, Z22.2; also elsewhere on the board
~COM1: Z10.5, Z14.14 (S12); also elsewhere on the board
~COM2: Z10.3, Z14.15 (S13); also elsewhere on the board
~COM3: Z10.1, Z14.16 (S14); also elsewhere on the board
~COM4: Z10.11, Z14.17 (S15); also elsewhere on the board
~COM_1: R14.2, Z10.6; also elsewhere on the board
~COM_2: R15.2, Z10.4; also elsewhere on the board
~COM_3: R16.2, Z10.2; also elsewhere on the board
~COM_4: R12.2, Z10.10; also elsewhere on the board
~DECK_1: Z21.7 (S6), Z22.3; also elsewhere on the board
~DECK_1_STB: R25.2, Z22.4; also elsewhere on the board
~DECK_2: Z21.8 (S7), Z22.9; also elsewhere on the board
~DECK_2_STB: R27.2, Z22.8; also elsewhere on the board
~ENABLE_1: Z14.18 (E0), Z14.19 (E1); also elsewhere on the board
~ENABLE_2: Z21.18 (E0); also elsewhere on the board
~PORT0: Z21.1 (S0); also elsewhere on the board
~PORT1: Z21.2 (S1); also elsewhere on the board
~PORT2: Z21.3 (S2); also elsewhere on the board
~PORT3: Z21.4 (S3); also elsewhere on the board
~READ_BLK: Z21.9 (S8), Z22.5; also elsewhere on the board
~READ_BLK_STB: R24.2, Z22.6; also elsewhere on the board
~RWD: Z15.11, Z21.16 (S14); also elsewhere on the board
~RWD_STB: R20.2, Z15.10; also elsewhere on the board
~SENSE_DATA: Z14.11 (S10), Z15.1; also elsewhere on the board
~SENSE_DATA_STB: R17.2, Z15.2; also elsewhere on the board
~SENSE_STATUS: Z14.10 (S9), Z15.3; also elsewhere on the board
~SENSE_STATUS_STB: R18.2, Z15.4; also elsewhere on the board
~SLEW_FWB: Z21.14 (S12), Z22.13; also elsewhere on the board
~SLEW_FWB_STB: R22.2, Z22.12; also elsewhere on the board
~SLEW_REV: Z15.5, Z21.15 (S13); also elsewhere on the board
~SLEW_REV_STB: R21.2, Z15.6; also elsewhere on the board
~T_STOP: Z15.9, Z21.17 (S15); also elsewhere on the board
~T_STOP_STB: R19.2, Z15.8; also elsewhere on the board
~WRITE: Z10.13, Z14.13 (S11); also elsewhere on the board
~WRITE_BLK: Z21.10 (S9), Z22.11; also elsewhere on the board
~WRITE_BLK_STB: R26.2, Z22.10; also elsewhere on the board
~WRITE_EOF_STB: Z21.11 (S10); also elsewhere on the board
~WRITE_STB: R13.2, Z10.12; also elsewhere on the board

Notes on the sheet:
This page decodes the EX xxx commands, effectively the OUT command. Z14 decodes ports 0 to 7, Z21 ports 8 to 24. ~I1~ thru ~I4~ are the inverted bits of the instruction register Unused pins on Z21 are unused ports. Unused pins on Z14 are the codings for INput ports - decoded elsewhere.

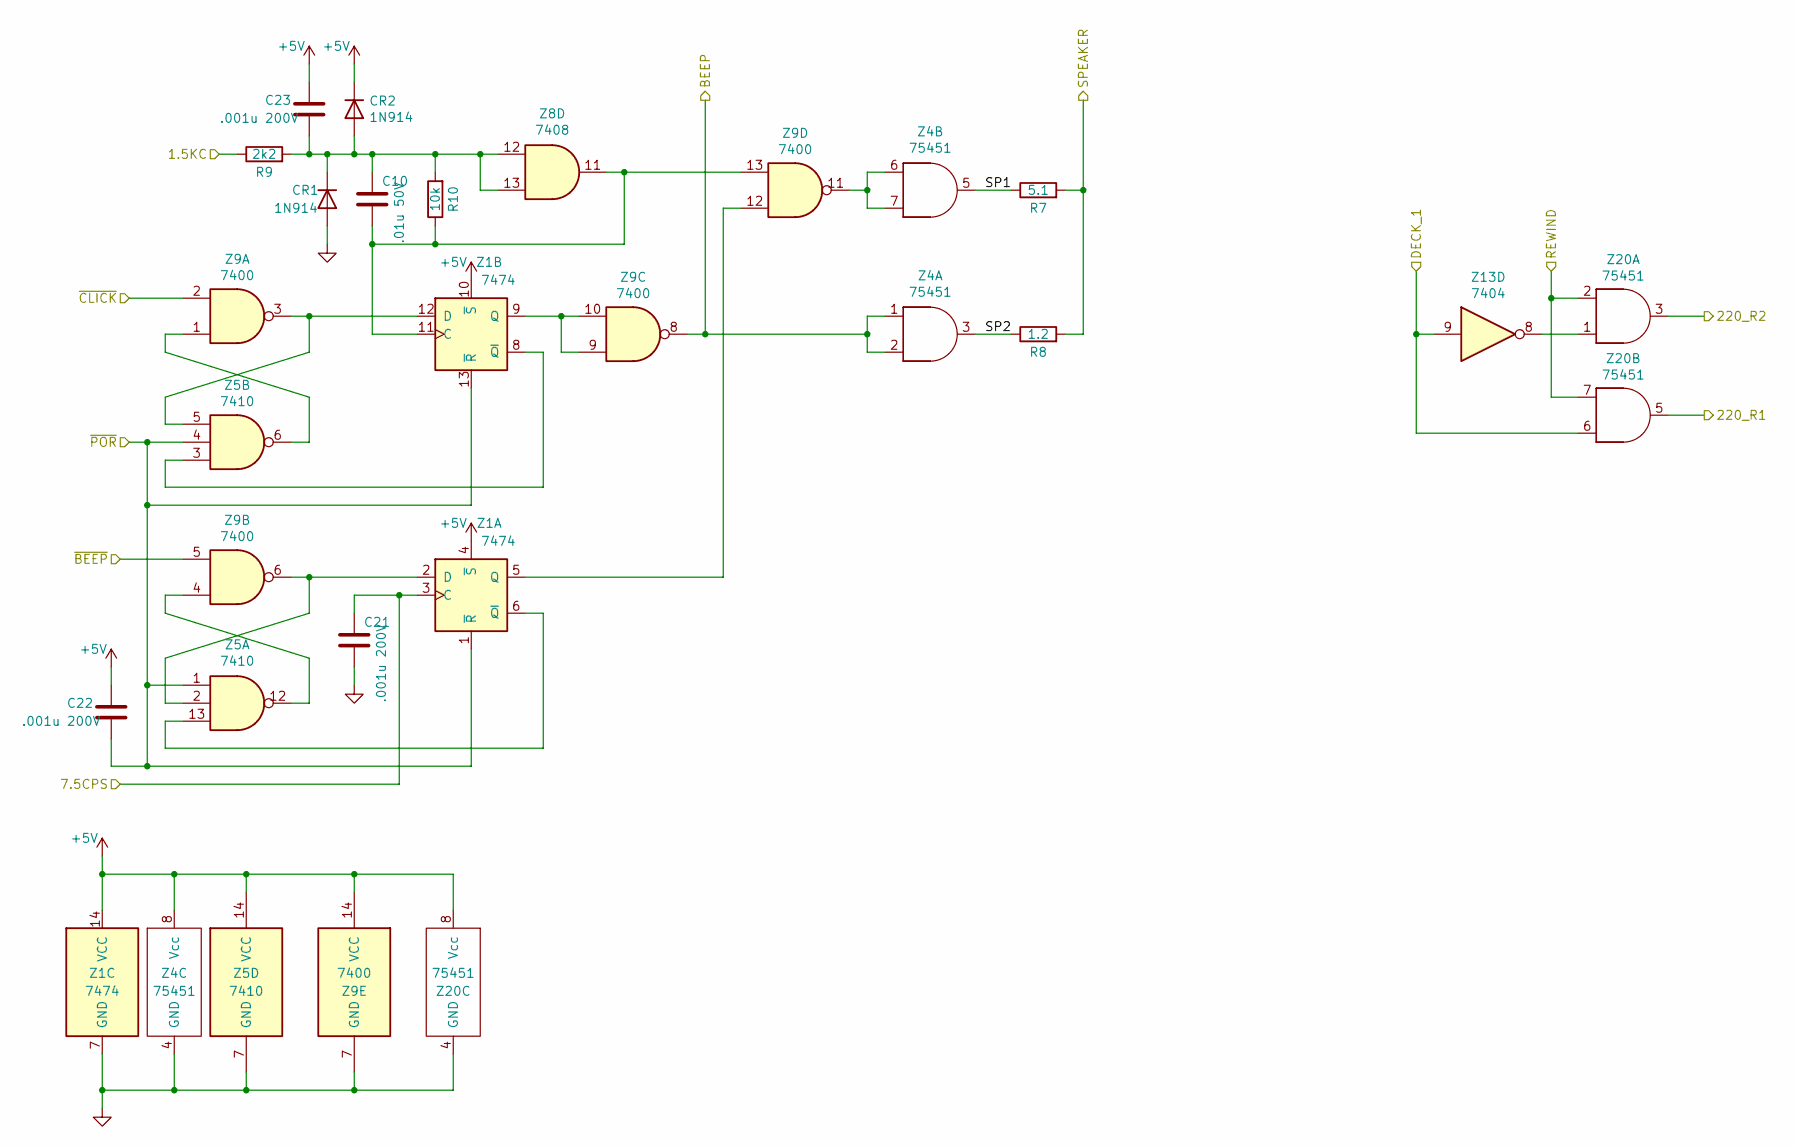
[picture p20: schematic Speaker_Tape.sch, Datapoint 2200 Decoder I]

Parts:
C10: .01u 50V; C_Disc_D7.0mm_W2.5mm_P5.00mm
C21, C22, C23: .001u 200V; C_Disc_D7.0mm_W2.5mm_P5.00mm
CR1, CR2: 1N914; D_DO-34_SOD68_P7.62mm_Horizontal
R7: 5.1; R_Axial_DIN0207_L6.3mm_D2.5mm_P10.16mm_Horizontal
R8: 1.2; R_Axial_DIN0207_L6.3mm_D2.5mm_P10.16mm_Horizontal
R9: 2k2; R_Axial_DIN0207_L6.3mm_D2.5mm_P10.16mm_Horizontal
R10: 10k; R_Axial_DIN0207_L6.3mm_D2.5mm_P10.16mm_Horizontal
Z1: 7474; DIP-14_W7.62mm_Socket
Z4, Z20: 75451; DIP-8_W7.62mm_Socket
Z5: 7410; DIP-14_W7.62mm_Socket
Z8: 7408; DIP-14_W7.62mm_Socket
Z9: 7400; DIP-14_W7.62mm_Socket
Z13: 7404; DIP-14_W7.62mm_Socket

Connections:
1.5KC: R9.1; also elsewhere on the board
7.5CPS: C21.2, Z1.3 (C); also elsewhere on the board
220_R1: Z20.5; also elsewhere on the board
220_R2: Z20.3; also elsewhere on the board
+5V: C22.2, C23.1, CR2.1 (K), Z1.4 (~S), Z1.10 (~S), Z1.14 (VCC), Z4.8 (Vcc), Z5.14 (VCC), Z9.14 (VCC), Z20.8 (Vcc); also elsewhere on the board
/IODecoder/~BEEP: Z9.5; also elsewhere on the board
/IODecoder/~CLICK: Z9.2; also elsewhere on the board
/Speaker_Tape/SP1: R7.1, Z4.5
/Speaker_Tape/SP2: R8.1, Z4.3
BEEP: Z4.1, Z4.2, Z9.8; also elsewhere on the board
DECK_1: Z13.9, Z20.6; also elsewhere on the board
GND: C21.1, CR1.2 (A), Z1.7 (GND), Z4.4 (GND), Z5.7 (GND), Z9.7 (GND), Z20.4 (GND); also elsewhere on the board
unnamed: C10.1, R10.1, Z1.11 (C), Z8.11, Z9.13
unnamed: C10.2, C23.2, CR1.1 (K), CR2.2 (A), R9.2, R10.2, Z8.12, Z8.13
unnamed: Z1.2 (D), Z5.2, Z9.6
unnamed: Z1.5 (Q), Z9.12
unnamed: Z1.6 (~Q), Z5.13
unnamed: Z1.8 (~Q), Z5.3
unnamed: Z1.9 (Q), Z9.9, Z9.10
unnamed: Z1.12 (D), Z5.5, Z9.3
unnamed: Z4.6, Z4.7, Z9.11
unnamed: Z5.6, Z9.1
unnamed: Z5.12, Z9.4
unnamed: Z13.8, Z20.1
REWIND: Z20.2, Z20.7; also elsewhere on the board
SPEAKER: R7.2, R8.2; also elsewhere on the board
~POR: C22.1, Z1.1 (~R), Z1.13 (~R), Z5.1, Z5.4; also elsewhere on the board

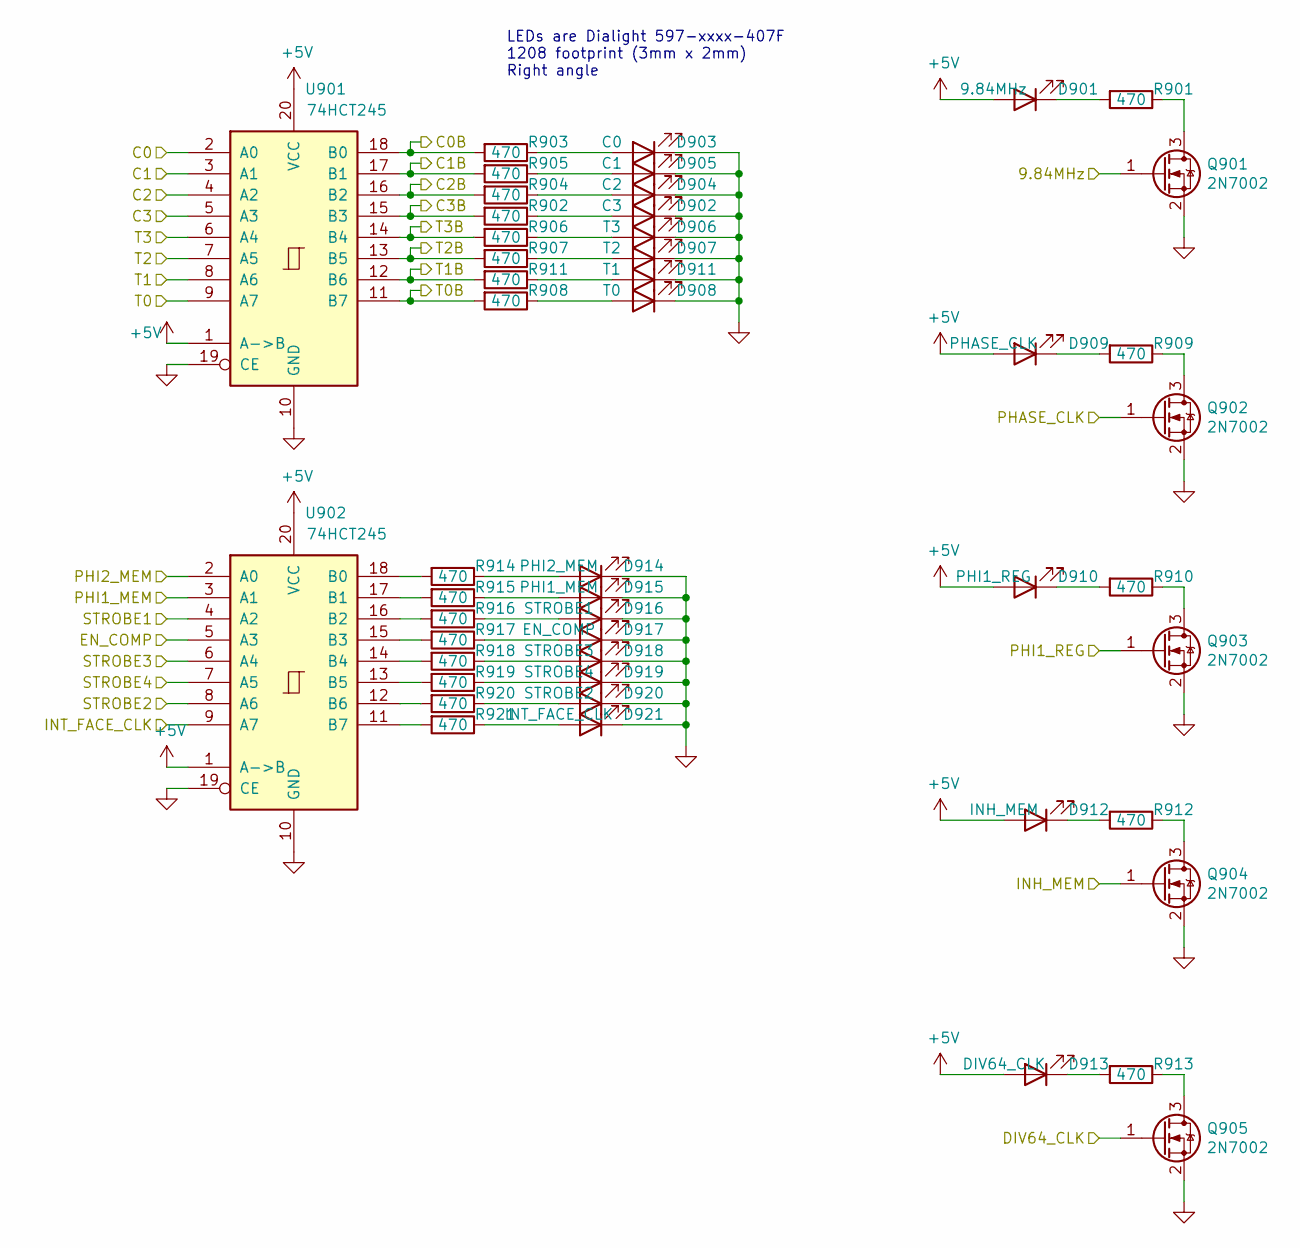
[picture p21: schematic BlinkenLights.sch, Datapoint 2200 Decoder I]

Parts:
D901: 9.84MHz; LED_Dialight_597_xxxx_407F_SMT_RA_3mmx2mmx1mm
D902: C3; LED_Dialight_597_xxxx_407F_SMT_RA_3mmx2mmx1mm
D903: C0; LED_Dialight_597_xxxx_407F_SMT_RA_3mmx2mmx1mm
D904: C2; LED_Dialight_597_xxxx_407F_SMT_RA_3mmx2mmx1mm
D905: C1; LED_Dialight_597_xxxx_407F_SMT_RA_3mmx2mmx1mm
D906: T3; LED_Dialight_597_xxxx_407F_SMT_RA_3mmx2mmx1mm
D907: T2; LED_Dialight_597_xxxx_407F_SMT_RA_3mmx2mmx1mm
D908: T0; LED_Dialight_597_xxxx_407F_SMT_RA_3mmx2mmx1mm
D909: PHASE_CLK; LED_Dialight_597_xxxx_407F_SMT_RA_3mmx2mmx1mm
D910: PHI1_REG; LED_Dialight_597_xxxx_407F_SMT_RA_3mmx2mmx1mm
D911: T1; LED_Dialight_597_xxxx_407F_SMT_RA_3mmx2mmx1mm
D912: INH_MEM; LED_Dialight_597_xxxx_407F_SMT_RA_3mmx2mmx1mm
D913: DIV64_CLK; LED_Dialight_597_xxxx_407F_SMT_RA_3mmx2mmx1mm
D914: PHI2_MEM; LED_Dialight_597_xxxx_407F_SMT_RA_3mmx2mmx1mm
D915: PHI1_MEM; LED_Dialight_597_xxxx_407F_SMT_RA_3mmx2mmx1mm
D916: STROBE1; LED_Dialight_597_xxxx_407F_SMT_RA_3mmx2mmx1mm
D917: EN_COMP; LED_Dialight_597_xxxx_407F_SMT_RA_3mmx2mmx1mm
D918: STROBE3; LED_Dialight_597_xxxx_407F_SMT_RA_3mmx2mmx1mm
D919: STROBE4; LED_Dialight_597_xxxx_407F_SMT_RA_3mmx2mmx1mm
D920: STROBE2; LED_Dialight_597_xxxx_407F_SMT_RA_3mmx2mmx1mm
D921: INT_FACE_CLK; LED_Dialight_597_xxxx_407F_SMT_RA_3mmx2mmx1mm
Q901, Q902, Q903, Q904, Q905: 2N7002; SOT-23
R901, R902, R903, R904, R905, R906, R907, R908, R909, R910, R911, R912, R913, R914, R915, R916, R917, R918, R919, R920, R921: 470; R_0805_2012Metric_Pad1.20x1.40mm_HandSolder
U901, U902: 74HCT245; TSSOP-20_4.4x6.5mm_P0.65mm

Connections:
+5V: D901.2 (A), D909.2 (A), D910.2 (A), D912.2 (A), D913.2 (A), U901.1 (A->B), U901.20 (VCC), U902.1 (A->B), U902.20 (VCC); also elsewhere on the board
/Scheduler/StampClock/C0: R903.2, U901.18 (B0); also elsewhere on the board
/Scheduler/StampClock/C1: R905.2, U901.17 (B1); also elsewhere on the board
/Scheduler/StampClock/C2: R904.2, U901.16 (B2); also elsewhere on the board
/Scheduler/StampClock/C3: R902.2, U901.15 (B3); also elsewhere on the board
/Scheduler/StampClock/T0: R908.2, U901.11 (B7); also elsewhere on the board
/Scheduler/StampClock/T1: R911.2, U901.12 (B6); also elsewhere on the board
/Scheduler/StampClock/T2: R907.2, U901.13 (B5); also elsewhere on the board
/Scheduler/StampClock/T3: R906.2, U901.14 (B4); also elsewhere on the board
C0: U901.2 (A0); also elsewhere on the board
C1: U901.3 (A1); also elsewhere on the board
C2: U901.4 (A2); also elsewhere on the board
C3: Q905.1 (G), U901.5 (A3); also elsewhere on the board
EN_COMP: U902.5 (A3); also elsewhere on the board
GND: D902.1 (K), D903.1 (K), D904.1 (K), D905.1 (K), D906.1 (K), D907.1 (K), D908.1 (K), D911.1 (K), D914.1 (K), D915.1 (K), D916.1 (K), D917.1 (K), D918.1 (K), D919.1 (K), D920.1 (K), D921.1 (K), Q901.2 (S), Q902.2 (S), Q903.2 (S), Q904.2 (S), Q905.2 (S), U901.10 (GND), U901.19 (CE), U902.10 (GND), U902.19 (CE); also elsewhere on the board
INH_MEM: Q904.1 (G); also elsewhere on the board
INT_FACE_CLK: U902.9 (A7); also elsewhere on the board
unnamed: D901.1 (K), R901.2
unnamed: D902.2 (A), R902.1
unnamed: D903.2 (A), R903.1
unnamed: D904.2 (A), R904.1
unnamed: D905.2 (A), R905.1
unnamed: D906.2 (A), R906.1
unnamed: D907.2 (A), R907.1
unnamed: D908.2 (A), R908.1
unnamed: D909.1 (K), R909.2
unnamed: D910.1 (K), R910.2
unnamed: D911.2 (A), R911.1
unnamed: D912.1 (K), R912.2
unnamed: D913.1 (K), R913.2
unnamed: D914.2 (A), R914.1
unnamed: D915.2 (A), R915.1
unnamed: D916.2 (A), R916.1
unnamed: D917.2 (A), R917.1
unnamed: D918.2 (A), R918.1
unnamed: D919.2 (A), R919.1
unnamed: D920.2 (A), R920.1
unnamed: D921.2 (A), R921.1
unnamed: Q901.3 (D), R901.1
unnamed: Q902.3 (D), R909.1
unnamed: Q903.3 (D), R910.1
unnamed: Q904.3 (D), R912.1
unnamed: Q905.3 (D), R913.1
unnamed: R914.2, U902.18 (B0)
unnamed: R915.2, U902.17 (B1)
unnamed: R916.2, U902.16 (B2)
unnamed: R917.2, U902.15 (B3)
unnamed: R918.2, U902.14 (B4)
unnamed: R919.2, U902.13 (B5)
unnamed: R920.2, U902.12 (B6)
unnamed: R921.2, U902.11 (B7)
PHASE_CLK: Q902.1 (G); also elsewhere on the board
PHI1_MEM: U902.3 (A1); also elsewhere on the board
PHI1_REG: Q903.1 (G); also elsewhere on the board
PHI2_MEM: U902.2 (A0); also elsewhere on the board
STROBE_1: U902.4 (A2); also elsewhere on the board
STROBE_2: U902.8 (A6); also elsewhere on the board
STROBE_3: U902.6 (A4); also elsewhere on the board
STROBE_4: U902.7 (A5); also elsewhere on the board
SYS_CLK: Q901.1 (G); also elsewhere on the board
T0: U901.9 (A7); also elsewhere on the board
T1: U901.8 (A6); also elsewhere on the board
T2: U901.7 (A5); also elsewhere on the board
T3: U901.6 (A4); also elsewhere on the board

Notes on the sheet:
LEDs are Dialight 597-xxxx-407F 1208 footprint (3mm x 2mm) Right angle

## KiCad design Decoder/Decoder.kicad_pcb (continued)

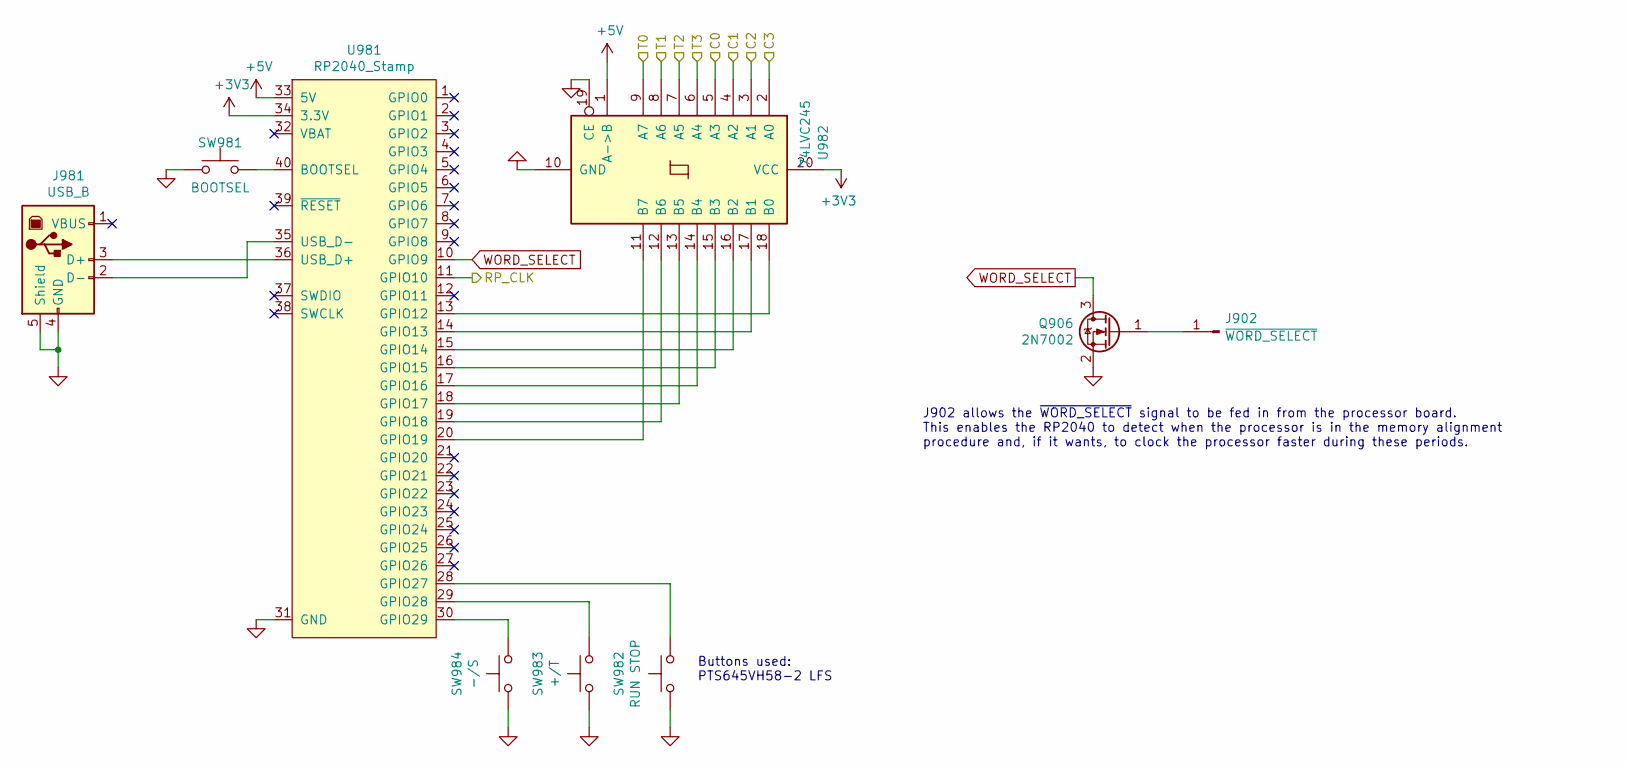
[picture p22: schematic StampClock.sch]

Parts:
J902: ~WORD_SELECT; PinHeader_1x01_P2.54mm_Horizontal
J981: USB_B; USB_B_Lumberg_2411_02_Horizontal
Q906: 2N7002; SOT-23
SW981: BOOTSEL; SW_Push_1P1T_NO_6x6mm_H9.5mm
SW982: RUN STOP; SW_Tactile_SPST_Angled_PTS645Vx58-2LFS
SW983: +/T; SW_Tactile_SPST_Angled_PTS645Vx58-2LFS
SW984: -/S; SW_Tactile_SPST_Angled_PTS645Vx58-2LFS
U981: RP2040_Stamp; RP2040_Stamp_SMD
U982: 74LVC245; TSSOP-20_4.4x6.5mm_P0.65mm

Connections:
+3V3: U981.34 (3.3V), U982.20 (VCC)
+5V: U981.33 (5V), U982.1 (A->B); also elsewhere on the board
/Scheduler/StampClock/C0: U982.5 (A3); also elsewhere on the board
/Scheduler/StampClock/C1: U982.4 (A2); also elsewhere on the board
/Scheduler/StampClock/C2: U982.3 (A1); also elsewhere on the board
/Scheduler/StampClock/C3: U982.2 (A0); also elsewhere on the board
/Scheduler/StampClock/T0: U982.9 (A7); also elsewhere on the board
/Scheduler/StampClock/T1: U982.8 (A6); also elsewhere on the board
/Scheduler/StampClock/T2: U982.7 (A5); also elsewhere on the board
/Scheduler/StampClock/T3: U982.6 (A4); also elsewhere on the board
GND: J981.4 (GND), J981.5 (Shield), Q906.2 (S), SW981.1, SW982.1, SW983.1, SW984.1, U981.31 (GND), U982.10 (GND), U982.19 (CE); also elsewhere on the board
unnamed: J902.1, Q906.1 (G)
unnamed: J981.2 (D-), U981.35 (USB_D-)
unnamed: J981.3 (D+), U981.36 (USB_D+)
unnamed: SW981.2, U981.40 (BOOTSEL)
unnamed: SW982.2, U981.28 (GPIO27)
unnamed: SW983.2, U981.29 (GPIO28)
unnamed: SW984.2, U981.30 (GPIO29)
unnamed: U981.13 (GPIO12), U982.18 (B0)
unnamed: U981.14 (GPIO13), U982.17 (B1)
unnamed: U981.15 (GPIO14), U982.16 (B2)
unnamed: U981.16 (GPIO15), U982.15 (B3)
unnamed: U981.17 (GPIO16), U982.14 (B4)
unnamed: U981.18 (GPIO17), U982.13 (B5)
unnamed: U981.19 (GPIO18), U982.12 (B6)
unnamed: U981.20 (GPIO19), U982.11 (B7)
RP_CLK: U981.11 (GPIO10); also elsewhere on the board
WORD_SELECT: Q906.3 (D), U981.10 (GPIO9)

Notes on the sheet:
J902 allows the ~WORD_SELECT~ signal to be fed in from the processor board. This enables the RP2040 to detect when the processor is in the memory alignment procedure and, if it wants, to clock the processor faster during these periods.
Buttons used: PTS645VH58-2 LFS

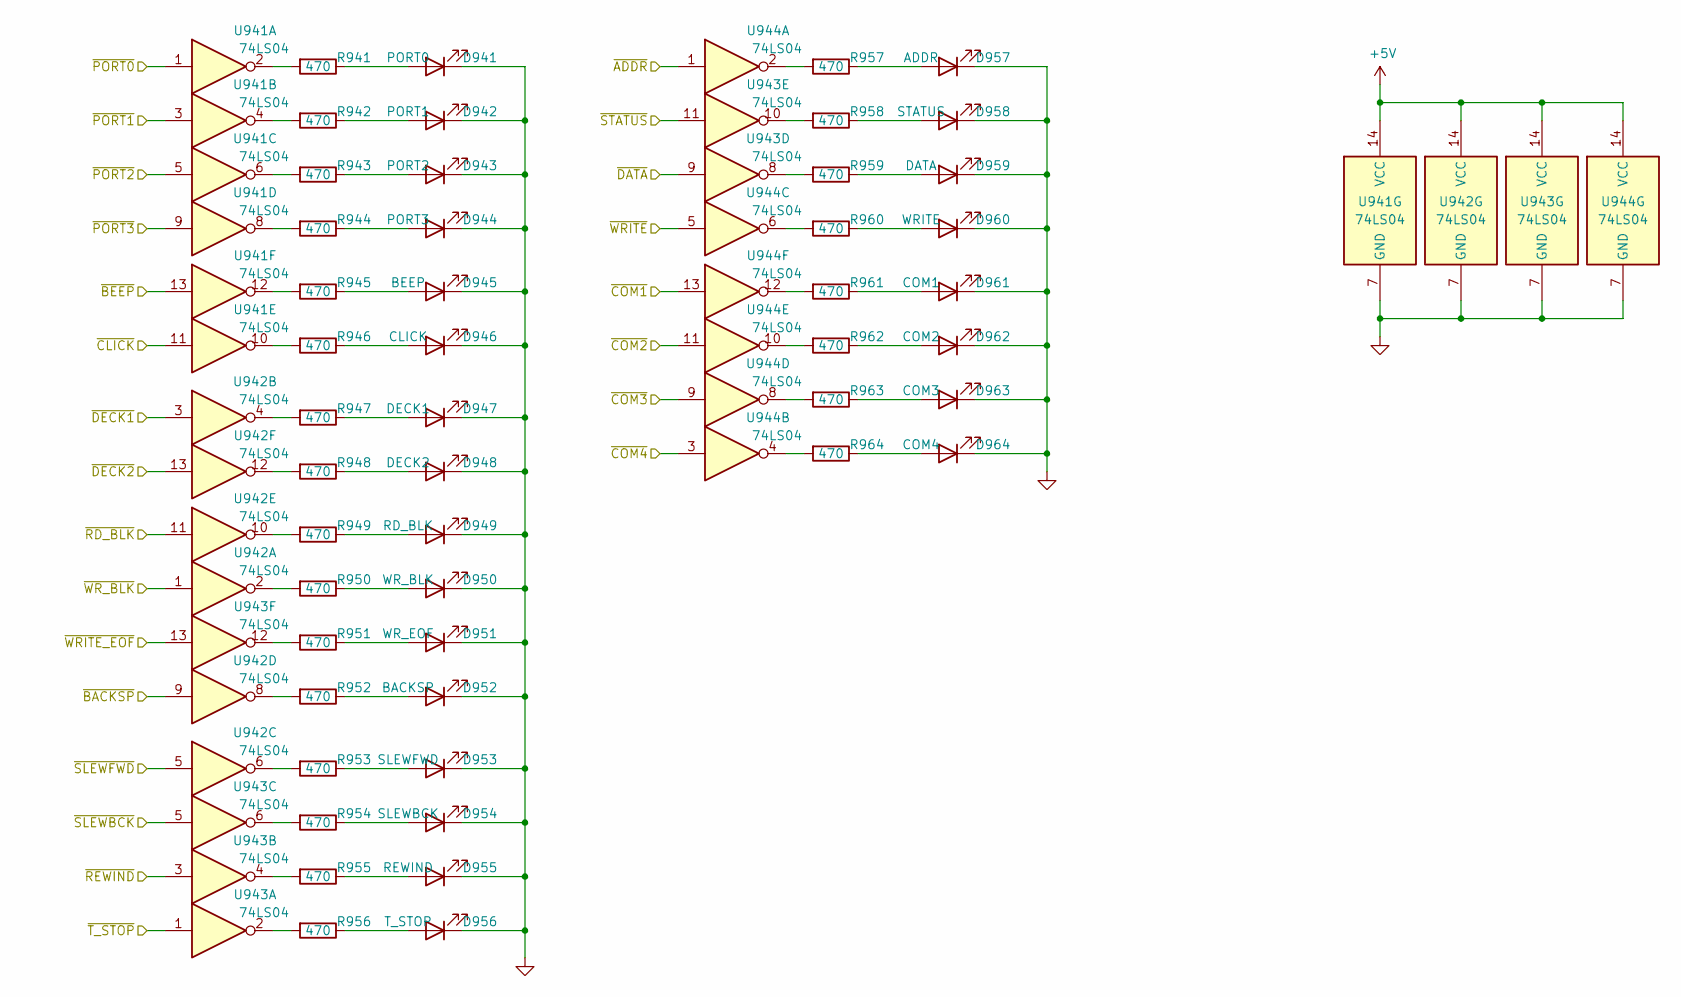
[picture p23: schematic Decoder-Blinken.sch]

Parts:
D941: PORT0; LED_Dialight_597_xxxx_407F_SMT_RA_3mmx2mmx1mm
D942: PORT1; LED_Dialight_597_xxxx_407F_SMT_RA_3mmx2mmx1mm
D943: PORT2; LED_Dialight_597_xxxx_407F_SMT_RA_3mmx2mmx1mm
D944: PORT3; LED_Dialight_597_xxxx_407F_SMT_RA_3mmx2mmx1mm
D945: BEEP; LED_Dialight_597_xxxx_407F_SMT_RA_3mmx2mmx1mm
D946: CLICK; LED_Dialight_597_xxxx_407F_SMT_RA_3mmx2mmx1mm
D947: DECK1; LED_Dialight_597_xxxx_407F_SMT_RA_3mmx2mmx1mm
D948: DECK2; LED_Dialight_597_xxxx_407F_SMT_RA_3mmx2mmx1mm
D949: RD_BLK; LED_Dialight_597_xxxx_407F_SMT_RA_3mmx2mmx1mm
D950: WR_BLK; LED_Dialight_597_xxxx_407F_SMT_RA_3mmx2mmx1mm
D951: WR_EOF; LED_Dialight_597_xxxx_407F_SMT_RA_3mmx2mmx1mm
D952: BACKSP; LED_Dialight_597_xxxx_407F_SMT_RA_3mmx2mmx1mm
D953: SLEWFWD; LED_Dialight_597_xxxx_407F_SMT_RA_3mmx2mmx1mm
D954: SLEWBCK; LED_Dialight_597_xxxx_407F_SMT_RA_3mmx2mmx1mm
D955: REWIND; LED_Dialight_597_xxxx_407F_SMT_RA_3mmx2mmx1mm
D956: T_STOP; LED_Dialight_597_xxxx_407F_SMT_RA_3mmx2mmx1mm
D957: ADDR; LED_Dialight_597_xxxx_407F_SMT_RA_3mmx2mmx1mm
D958: STATUS; LED_Dialight_597_xxxx_407F_SMT_RA_3mmx2mmx1mm
D959: DATA; LED_Dialight_597_xxxx_407F_SMT_RA_3mmx2mmx1mm
D960: WRITE; LED_Dialight_597_xxxx_407F_SMT_RA_3mmx2mmx1mm
D961: COM1; LED_Dialight_597_xxxx_407F_SMT_RA_3mmx2mmx1mm
D962: COM2; LED_Dialight_597_xxxx_407F_SMT_RA_3mmx2mmx1mm
D963: COM3; LED_Dialight_597_xxxx_407F_SMT_RA_3mmx2mmx1mm
D964: COM4; LED_Dialight_597_xxxx_407F_SMT_RA_3mmx2mmx1mm
R941, R942, R943, R944, R945, R946, R947, R948, R949, R950, R951, R952, R953, R954, R955, R956, R957, R958, R959, R960, R961, R962, R963, R964: 470; R_0805_2012Metric_Pad1.20x1.40mm_HandSolder
U941, U942, U943, U944: 74LS04; TSSOP-14_4.4x5mm_P0.65mm

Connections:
+5V: U941.14 (VCC), U942.14 (VCC), U943.14 (VCC), U944.14 (VCC); also elsewhere on the board
/IODecoder/~BEEP: U941.13; also elsewhere on the board
/IODecoder/~CLICK: U941.11; also elsewhere on the board
GND: D941.1 (K), D942.1 (K), D943.1 (K), D944.1 (K), D945.1 (K), D946.1 (K), D947.1 (K), D948.1 (K), D949.1 (K), D950.1 (K), D951.1 (K), D952.1 (K), D953.1 (K), D954.1 (K), D955.1 (K), D956.1 (K), D957.1 (K), D958.1 (K), D959.1 (K), D960.1 (K), D961.1 (K), D962.1 (K), D963.1 (K), D964.1 (K), U941.7 (GND), U942.7 (GND), U943.7 (GND), U944.7 (GND); also elsewhere on the board
unnamed: D941.2 (A), R941.1
unnamed: D942.2 (A), R942.1
unnamed: D943.2 (A), R943.1
unnamed: D944.2 (A), R944.1
unnamed: D945.2 (A), R945.1
unnamed: D946.2 (A), R946.1
unnamed: D947.2 (A), R947.1
unnamed: D948.2 (A), R948.1
unnamed: D949.2 (A), R949.1
unnamed: D950.2 (A), R950.1
unnamed: D951.2 (A), R951.1
unnamed: D952.2 (A), R952.1
unnamed: D953.2 (A), R953.1
unnamed: D954.2 (A), R954.1
unnamed: D955.2 (A), R955.1
unnamed: D956.2 (A), R956.1
unnamed: D957.2 (A), R957.1
unnamed: D958.2 (A), R958.1
unnamed: D959.2 (A), R959.1
unnamed: D960.2 (A), R960.1
unnamed: D961.2 (A), R961.1
unnamed: D962.2 (A), R962.1
unnamed: D963.2 (A), R963.1
unnamed: D964.2 (A), R964.1
unnamed: R941.2, U941.2
unnamed: R942.2, U941.4
unnamed: R943.2, U941.6
unnamed: R944.2, U941.8
unnamed: R945.2, U941.12
unnamed: R946.2, U941.10
unnamed: R947.2, U942.4
unnamed: R948.2, U942.12
unnamed: R949.2, U942.10
unnamed: R950.2, U942.2
unnamed: R951.2, U943.12
unnamed: R952.2, U942.8
unnamed: R953.2, U942.6
unnamed: R954.2, U943.6
unnamed: R955.2, U943.4
unnamed: R956.2, U943.2
unnamed: R957.2, U944.2
unnamed: R958.2, U943.10
unnamed: R959.2, U943.8
unnamed: R960.2, U944.6
unnamed: R961.2, U944.12
unnamed: R962.2, U944.10
unnamed: R963.2, U944.8
unnamed: R964.2, U944.4
~ADR: U944.1; also elsewhere on the board
~BACK_SPACE: U942.9; also elsewhere on the board
~COM1: U944.13; also elsewhere on the board
~COM2: U944.11; also elsewhere on the board
~COM3: U944.9; also elsewhere on the board
~COM4: U944.3; also elsewhere on the board
~DECK_1: U942.3; also elsewhere on the board
~DECK_2: U942.13; also elsewhere on the board
~PORT0: U941.1; also elsewhere on the board
~PORT1: U941.3; also elsewhere on the board
~PORT2: U941.5; also elsewhere on the board
~PORT3: U941.9; also elsewhere on the board
~READ_BLK: U942.11; also elsewhere on the board
~RWD: U943.3; also elsewhere on the board
~SENSE_DATA: U943.9; also elsewhere on the board
~SENSE_STATUS: U943.11; also elsewhere on the board
~SLEW_FWB: U942.5; also elsewhere on the board
~SLEW_REV: U943.5; also elsewhere on the board
~T_STOP: U943.1; also elsewhere on the board
~WRITE: U944.5; also elsewhere on the board
~WRITE_BLK: U942.1; also elsewhere on the board
~WRITE_EOF_STB: U943.13; also elsewhere on the board



Board: 2 copper layers, 272.4 x 146.7 mm, 202 parts (78 on the bottom side), 234 nets.

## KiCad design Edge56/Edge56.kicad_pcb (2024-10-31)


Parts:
J1, J6: Conn_02x04_Top_Bottom; PinHeader_2x04_P2.54mm_Horizontal
J2, J7, J12, J13: Conn_02x04_Top_Bottom; PinSocket_2x04_P2.54mm_Horizontal
J3, J4, J5, J9, J10, J11: Conn_01x28_Female; PinSocket_1x28_P2.54mm_Vertical
J8: Conn_02x28_Top_Bottom; EdgeConn_Socket_56_Pin_Pitch_3.96mm
J14, J15: Conn_02x04_Top_Bottom; PinHeader_2x04_P2.54mm_Vertical

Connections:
+5V: J1.1, J1.2, J1.3, J1.4, J1.5, J1.6, J1.7, J1.8, J2.1, J2.2, J2.3, J2.4, J2.5, J2.6, J2.7, J2.8, J12.1, J12.2, J12.3, J12.4, J12.5, J12.6, J12.7, J12.8, J14.1, J14.2, J14.3, J14.4, J14.5, J14.6, J14.7, J14.8
GND: J6.1, J6.2, J6.3, J6.4, J6.5, J6.6, J6.7, J6.8, J7.1, J7.2, J7.3, J7.4, J7.5, J7.6, J7.7, J7.8, J13.1, J13.2, J13.3, J13.4, J13.5, J13.6, J13.7, J13.8, J15.1, J15.2, J15.3, J15.4, J15.5, J15.6, J15.7, J15.8
unnamed: J3.1, J4.1, J5.1, J8.1
unnamed: J3.2, J4.2, J5.2, J8.2
unnamed: J3.3, J4.3, J5.3, J8.3
unnamed: J3.4, J4.4, J5.4, J8.4
unnamed: J3.5, J4.5, J5.5, J8.5
unnamed: J3.6, J4.6, J5.6, J8.6
unnamed: J3.7, J4.7, J5.7, J8.7
unnamed: J3.8, J4.8, J5.8, J8.8
unnamed: J3.9, J4.9, J5.9, J8.9
unnamed: J3.10, J4.10, J5.10, J8.10
unnamed: J3.11, J4.11, J5.11, J8.11
unnamed: J3.12, J4.12, J5.12, J8.12
unnamed: J3.13, J4.13, J5.13, J8.13
unnamed: J3.14, J4.14, J5.14, J8.14
unnamed: J3.15, J4.15, J5.15, J8.15
unnamed: J3.16, J4.16, J5.16, J8.16
unnamed: J3.17, J4.17, J5.17, J8.17
unnamed: J3.18, J4.18, J5.18, J8.18
unnamed: J3.19, J4.19, J5.19, J8.19
unnamed: J3.20, J4.20, J5.20, J8.20
unnamed: J3.21, J4.21, J5.21, J8.21
unnamed: J3.22, J4.22, J5.22, J8.22
unnamed: J3.23, J4.23, J5.23, J8.23
unnamed: J3.24, J4.24, J5.24, J8.24
unnamed: J3.25, J4.25, J5.25, J8.25
unnamed: J3.26, J4.26, J5.26, J8.26
unnamed: J3.27, J4.27, J5.27, J8.27
unnamed: J3.28, J4.28, J5.28, J8.28
unnamed: J8.29, J9.1, J10.1, J11.1
unnamed: J8.30, J9.2, J10.2, J11.2
unnamed: J8.31, J9.3, J10.3, J11.3
unnamed: J8.32, J9.4, J10.4, J11.4
unnamed: J8.33, J9.5, J10.5, J11.5
unnamed: J8.34, J9.6, J10.6, J11.6
unnamed: J8.35, J9.7, J10.7, J11.7
unnamed: J8.36, J9.8, J10.8, J11.8
unnamed: J8.37, J9.9, J10.9, J11.9
unnamed: J8.38, J9.10, J10.10, J11.10
unnamed: J8.39, J9.11, J10.11, J11.11
unnamed: J8.40, J9.12, J10.12, J11.12
unnamed: J8.41, J9.13, J10.13, J11.13
unnamed: J8.42, J9.14, J10.14, J11.14
unnamed: J8.43, J9.15, J10.15, J11.15
unnamed: J8.44, J9.16, J10.16, J11.16
unnamed: J8.45, J9.17, J10.17, J11.17
unnamed: J8.46, J9.18, J10.18, J11.18
unnamed: J8.47, J9.19, J10.19, J11.19
unnamed: J8.48, J9.20, J10.20, J11.20
unnamed: J8.49, J9.21, J10.21, J11.21
unnamed: J8.50, J9.22, J10.22, J11.22
unnamed: J8.51, J9.23, J10.23, J11.23
unnamed: J8.52, J9.24, J10.24, J11.24
unnamed: J8.53, J9.25, J10.25, J11.25
unnamed: J8.54, J9.26, J10.26, J11.26
unnamed: J8.55, J9.27, J10.27, J11.27
unnamed: J8.56, J9.28, J10.28, J11.28


Board: 2 copper layers, 36.2 x 141.0 mm, 15 parts (1 on the bottom side), 58 nets.

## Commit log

2022-06-19 README update
    Better formatting and extra board detail
2023-04-07 Decoder 1 Rev 1
    [ALU.sch, AddrRegStackControl.sch, BlinkenLights.sch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]
2024-10-31 Schematics for display & keyboard, adding LEDs to processor PCB
    [ALU.sch, ALUBlinken.sch, ARegister.sch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]
2024-11-01 Added Decoder PCB photos
2024-11-01 Added Memory PCB photos
2024-11-01 Added renders of processor PCB

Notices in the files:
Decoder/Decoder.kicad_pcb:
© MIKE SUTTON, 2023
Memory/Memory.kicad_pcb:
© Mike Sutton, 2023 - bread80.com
